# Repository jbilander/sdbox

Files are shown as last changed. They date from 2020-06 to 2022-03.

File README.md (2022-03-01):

# SDBox for Amiga

***
This version `v1` is superseded by the new `SDBox-v2` here: https://github.com/jbilander/SDBox-v2

There is also a SDBox Mini available here: https://github.com/jbilander/SDBox-Mini
***

### A parallel to sd-card project for the Amiga

This code uses the code from the amiga-par-to-spi-adapter https://github.com/niklasekstrom/amiga-par-to-spi-adapter written by Niklas Ekström. KiCad design, Schematics and files for DesignSpark Mechanical v4 is made by me. Design of the 3d-printable sdbox case is made by me and Tobias Niva (niva3d, http://www.niva3d.com/). It is a collaborative work done by us three, Enjoy!

***

<a href="images/sdbox_rev_1a_pic1.png">
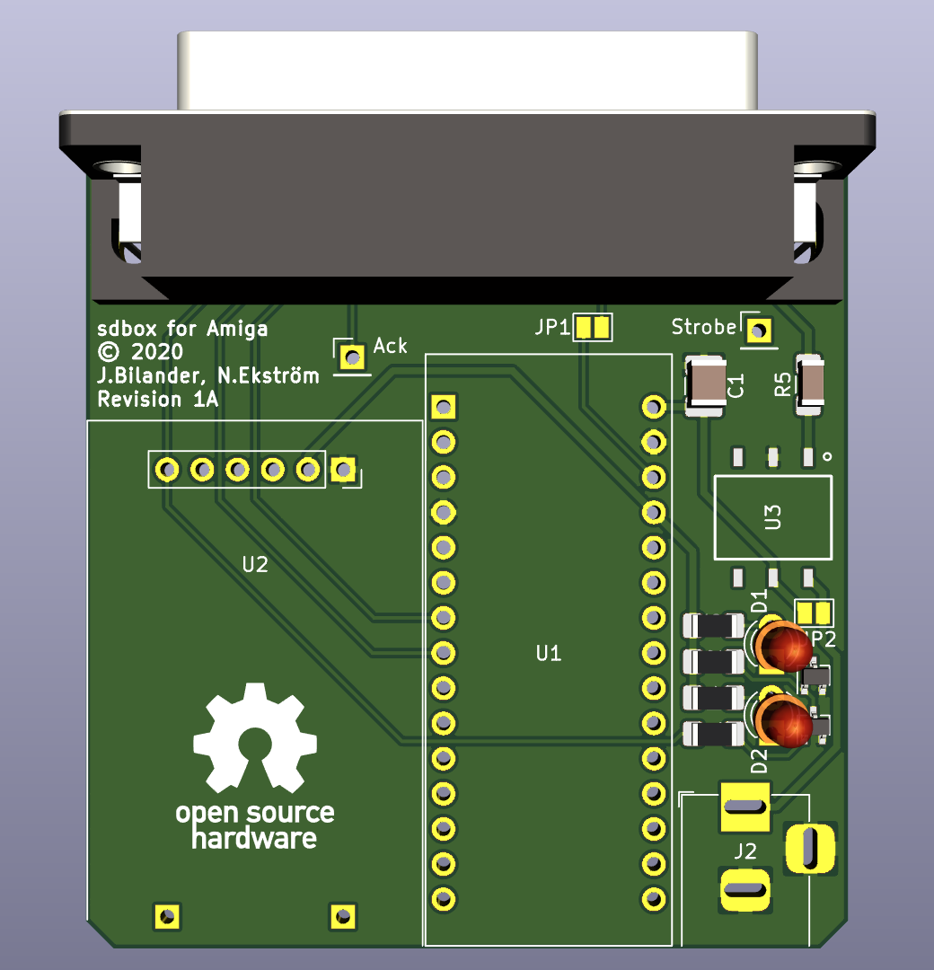
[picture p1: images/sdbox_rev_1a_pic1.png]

</a>
<a href="images/pcb_pic1.jpg">
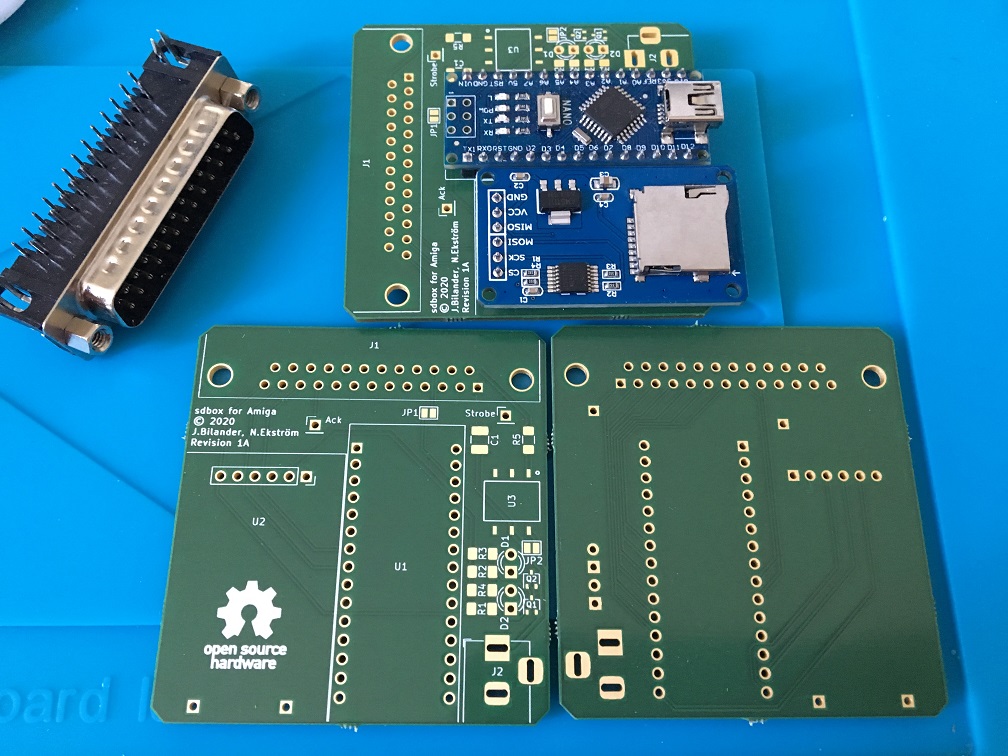
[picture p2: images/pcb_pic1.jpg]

</a>
<a href="images/sd_box_pic1.jpg">
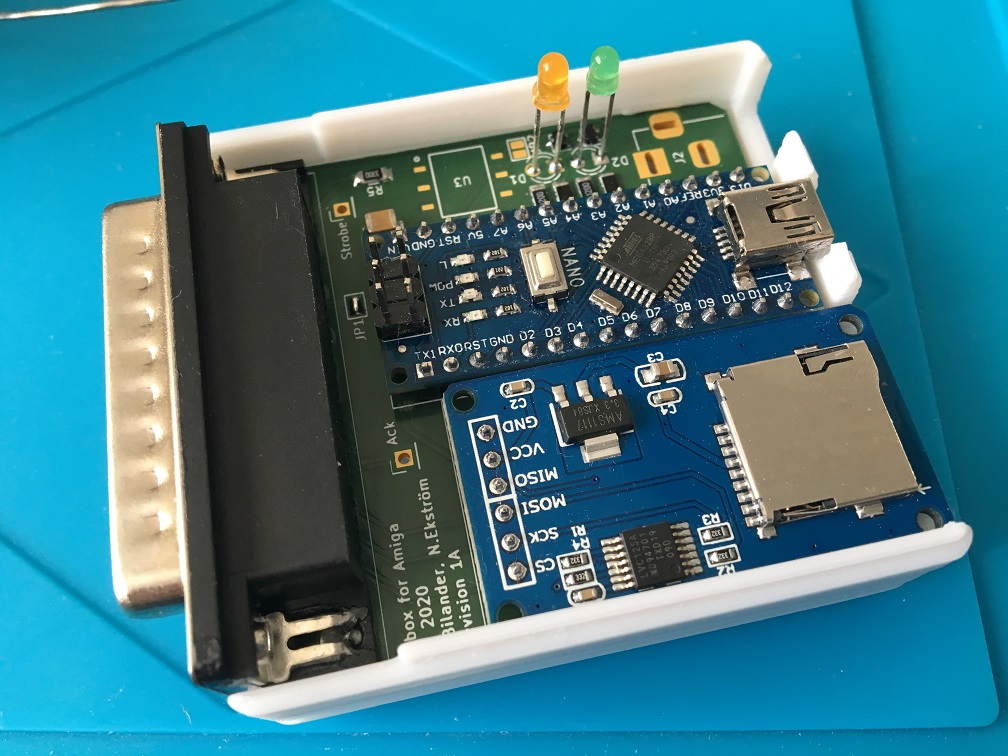
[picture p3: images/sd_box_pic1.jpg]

</a>
<a href="images/sdbox_front.jpg">
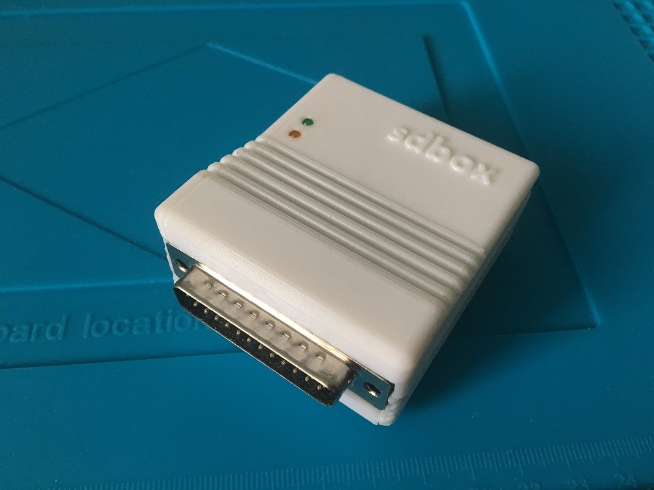
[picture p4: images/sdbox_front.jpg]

</a>
<a href="images/sdbox_backside_pic1.jpg">
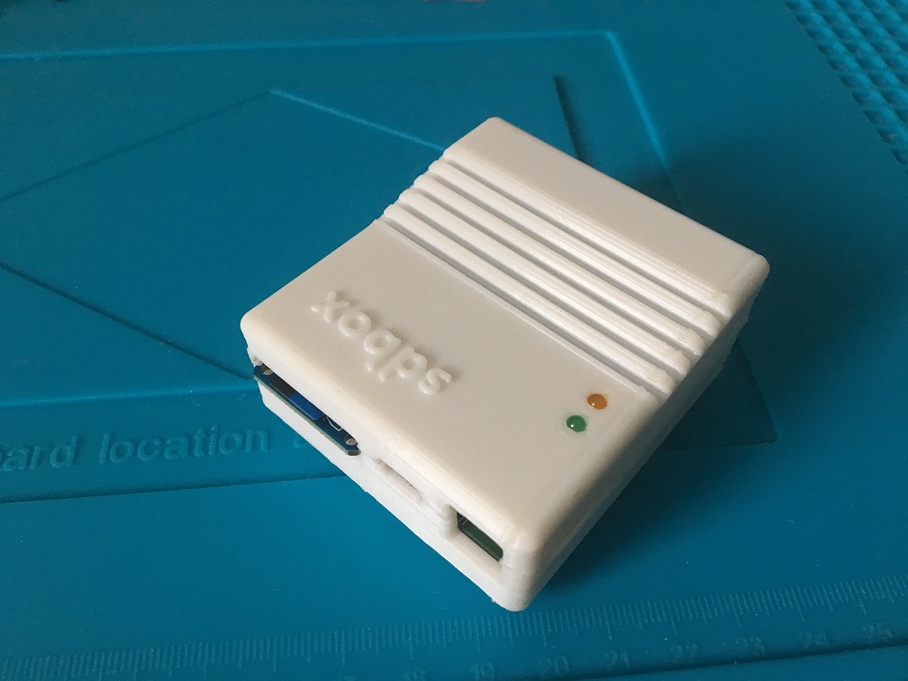
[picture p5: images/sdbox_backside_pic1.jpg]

</a>
<a href="images/sdbox_backside_pic2.jpg">
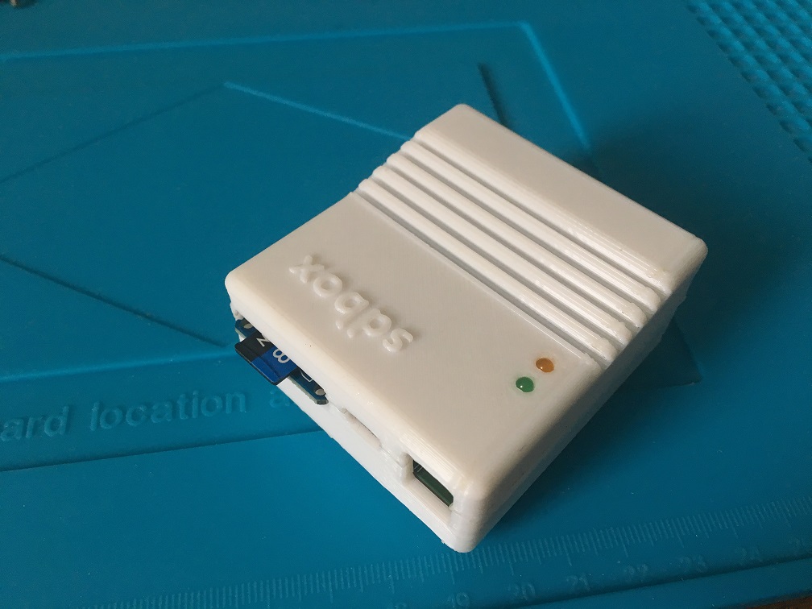
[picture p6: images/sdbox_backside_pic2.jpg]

</a>

***

What is the sdbox for Amiga? 

It is a small device that you can plug into your Amiga's parallel port and get access to a sd-card formatted with e.g. a windows FAT file system. It uses an Arduino Nano V3 and a common cheap MicroSD Card Adapter that has a voltage level shifter on board. These small devices are soldered onto a small PCB together with a male d-sub db25 connector that fits into the Amiga parallel port (The A1000 needs a proper gender changer, be aware). The device must be powered externally either through the usb-connector on the Nano or via the separate barrel jack connector on the main PCB. A power supply with 1A DC capacity should suffice. `5V` via USB or `7-12V` via the barrel jack power connector that goes to the VIN of the Nano V3. The driver should be AmigaOS system friendly but takes exclusive access over the parallel port so don't expect to run other things on this port together with the sdbox with some kind of breakout cable. It should work from 1.3 and upwards, verified working on 1.3, 3.1 and 3.1.4 so far.

The schematics, BOM, kicad drawings and the 3d-printable case source and stl files can all be found in the hardware folder.

PCBs can be order directly via link below or you can send the gerbers zip (or generate gerbers yourself) and send them to your favorite boardhouse.

https://aisler.net/p/YVXJBQHM

***
Ok enough talk!, show us some videos:
<br />

Copying from Amiga to sd-card<br />
https://i.imgur.com/um15pal.mp4

Copying from sd-card to the Amiga (cpu fastrom activated, KS ROM loaded into Fast RAM)<br />
https://i.imgur.com/G6VRPpx.mp4

Copying from sd-card to the Amiga  (without fastrom activated) <br />
https://i.imgur.com/ADebdlJ.mp4

***

<a href="images/sd_box_pic2.jpg">
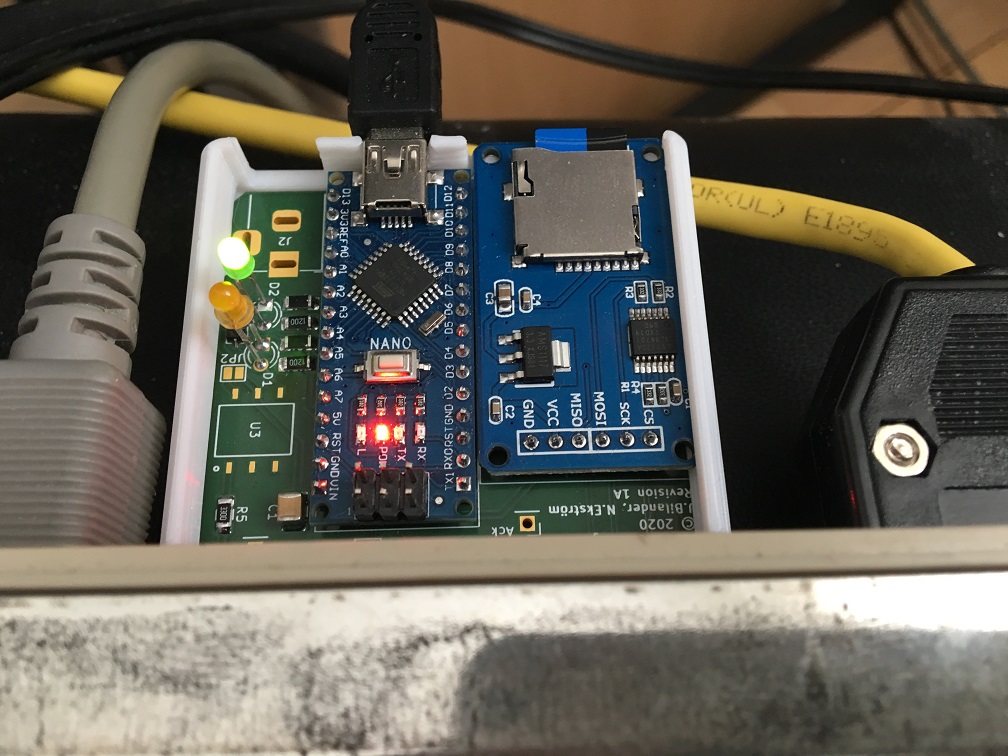
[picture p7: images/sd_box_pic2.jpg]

</a>
<a href="images/sd_box_pic3.jpg">
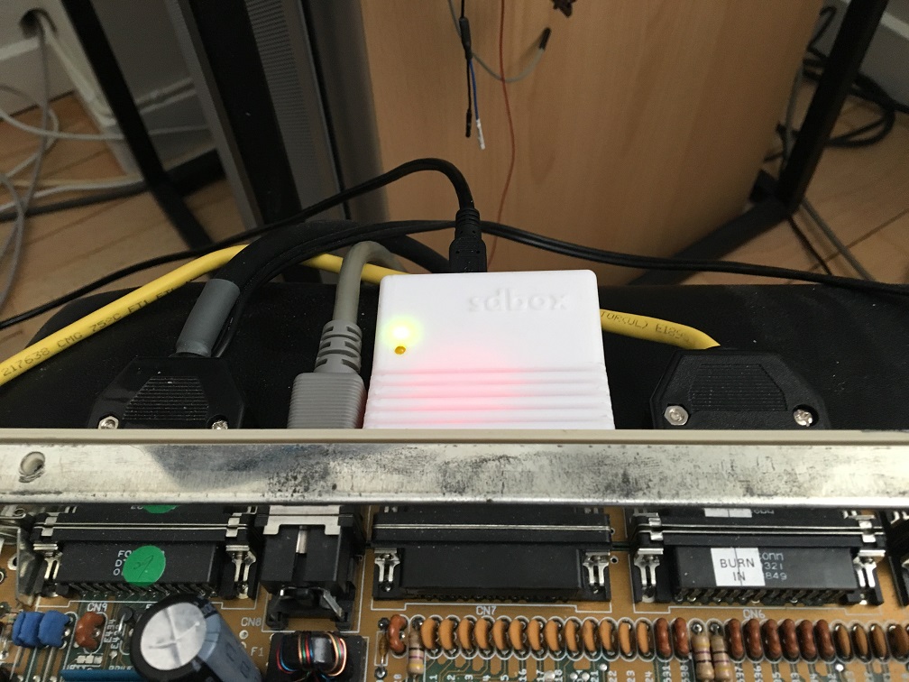
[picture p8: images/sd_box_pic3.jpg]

</a>
<a href="images/sd_box_pic4.jpg">
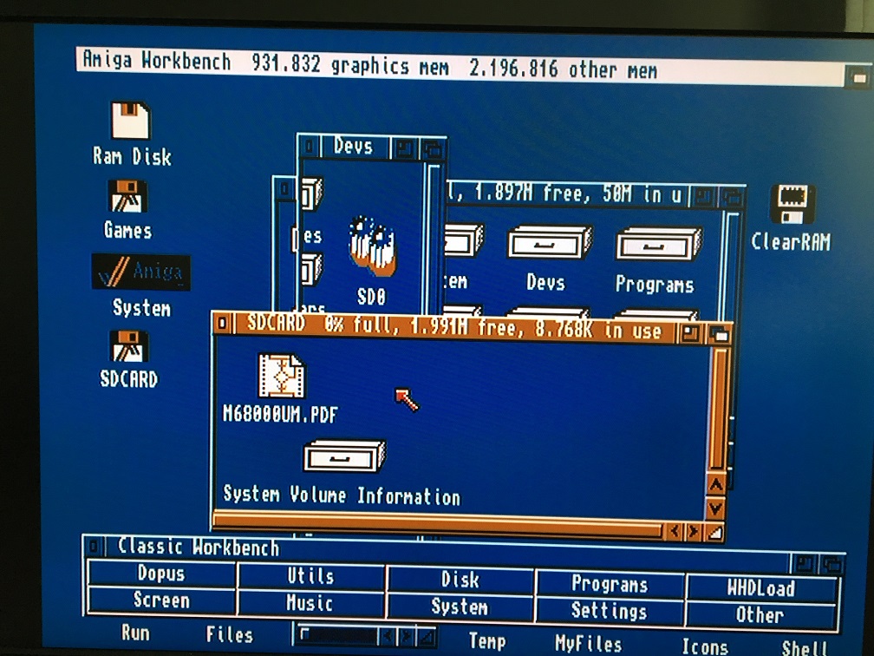
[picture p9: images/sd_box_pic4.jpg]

</a>

***

<a href="images/sdbox_3d_model_pic1.jpg">
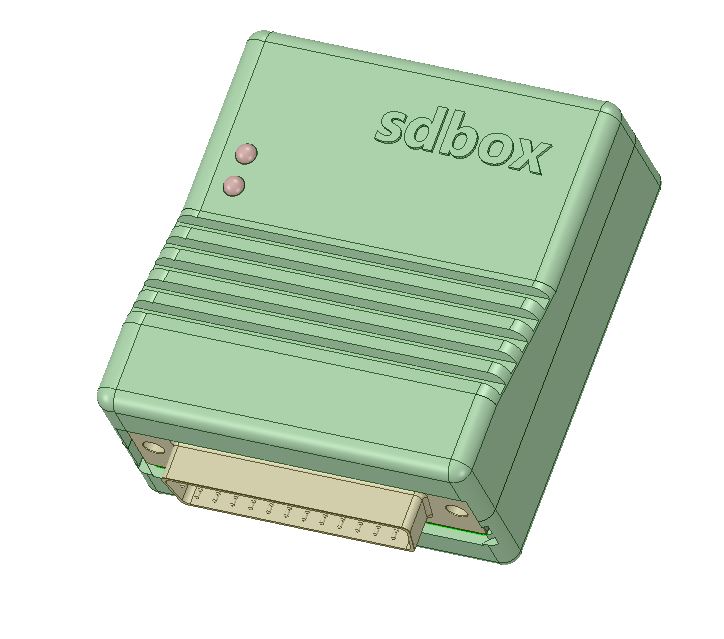
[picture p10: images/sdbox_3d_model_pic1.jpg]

</a>
<a href="images/vFinal-4view.png">
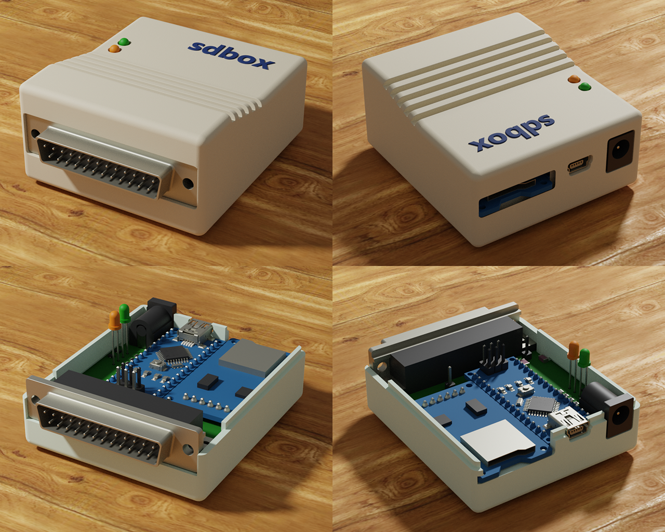
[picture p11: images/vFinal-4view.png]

</a>
<br />

More rendered pictures and concepts by `niva3d` under the `images/_renders` directory, made in Blender, check it out!

***

### 3d-printing

Check the README in the `hardware/DSM` folder

***

### Howto build the spisd.device driver

Check the README in the sd folder.

For the lazy: Binaries available now in a zip file under the `release` tab above.

***

### Caveats

One little caveat to keep in mind is that we do no CRC-verification of data being copied so please verify your files afterwards manually if you are going to copy important files over this way like taking a backup or something. Another caveat is that not all sd-cards might work with the sdbox so aim for a cheap 4/8 GB card and format it with a smaller partition `below 4GB` with FAT is a good starting point. If you see an error message saying `bad number` when trying to mount `SD0` it may be an indication that your particular sd-card simply doesn't work with the sdbox for some reason.

Everything done here is provide `as is`, don't blame us if your Amiga CIAs dies or your files get corrupted using the sdbox. I don't think it will happen though. Be careful though when plugging the sdbox in or out of the Amiga, always do that with the Amiga turned off.

    Some advice from Tom Handley / 18 April 93 (taken from pario on Aminet)

    NEVER connect, disconnect, or switch, parallel port lines with the power on!  
    ALWAYS shut the power off first!  In most cases, you should use the following sequence:

       Power up:   - Turn on your Amiga
                   - Turn on the external device

       Power down: - Turn off the external device
                   - Turn off your Amiga
                   
    If you have been switching devices with the power on you have been lucky...
    Not following the above precaution, and static electricity, are the two main
    causes of user-induced 8520 failures.
***

The sequence I use when powering the sdbox via USB is this:

* Plug the micro sd-card into the MicroSD card slot of the sdbox
* With the Amiga turned off plug the sdbox into the Amiga 
* Connect the +5V USB power cable into the sdbox, the two LEDs will light up with a steady shine. Don't worry that the activity LED light turns on, it's on when the SEL/CS line goes low (Zero). It will turn off as soon as the Amiga is turned on.
* Turn on the Amiga
* In wb mount the card
* When done, turn off the Amiga, the sdbox Activity LED will light up again as a reminder to unplug the USB power cable
* Unplug the sdbox from the Amiga if you want to remove it.

This has worked without any issues for me.

Hopefully powering via the barrel jack and using U3 chip (Solid State Relay) will work and automatically handle the Power cycling following the Amiga's on/off.

__UPDATE: Powering via the barrel jack is now verified and working.__ see last section in this readme

***

### Kudos

Many thanks to Mike Stirling for writing the original k1208-drivers and making them open source, we built further on his code. It was a good starting point. Thanks Mike and kipper2k and others involved in k1208.

***

### Performance 

What about performance you may ask? 

Well, Niklas managed to write the drivers with some real clever assembler to make it go at 2E-speed (theoretical 350 KB/s, IRL around 225-280 KB/s) if you have some kind of Accelerator installed in your A500. 
Copying a 23 MB file from the SD-card to the compact flash in the HC508 took 98 seconds, giving a throughput of 225 KB/s. We think this is a good result given the fact of the slow clocking of the CIAs (E-clock). It will also work with a standard 68k CPU at 7 MHz although slower.

With my TF534 and 3.1 rom loaded into Fast RAM via the command `cpu fastrom` (requires a MMU) I get 280 KB/s in SysInfo, and without fastrom 250 KB/s. It is a little slower copying to the Amiga than from the Amiga.

<a href="images/screenshots/sdcard_sysinfo_speed.jpg">
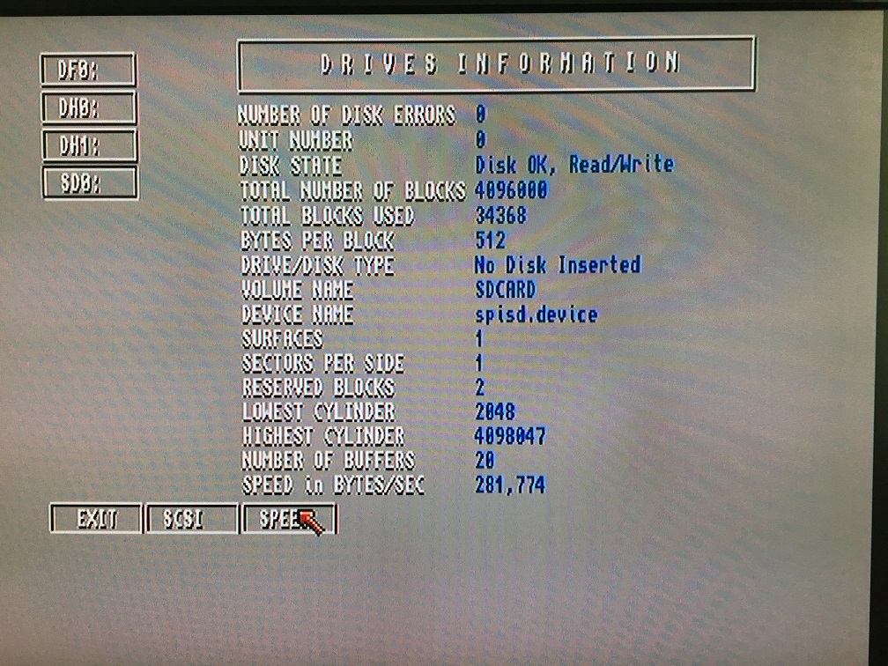
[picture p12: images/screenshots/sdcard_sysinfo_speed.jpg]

</a>
<a href="images/screenshots/amiga_parallel_port_2E_speed.jpg">
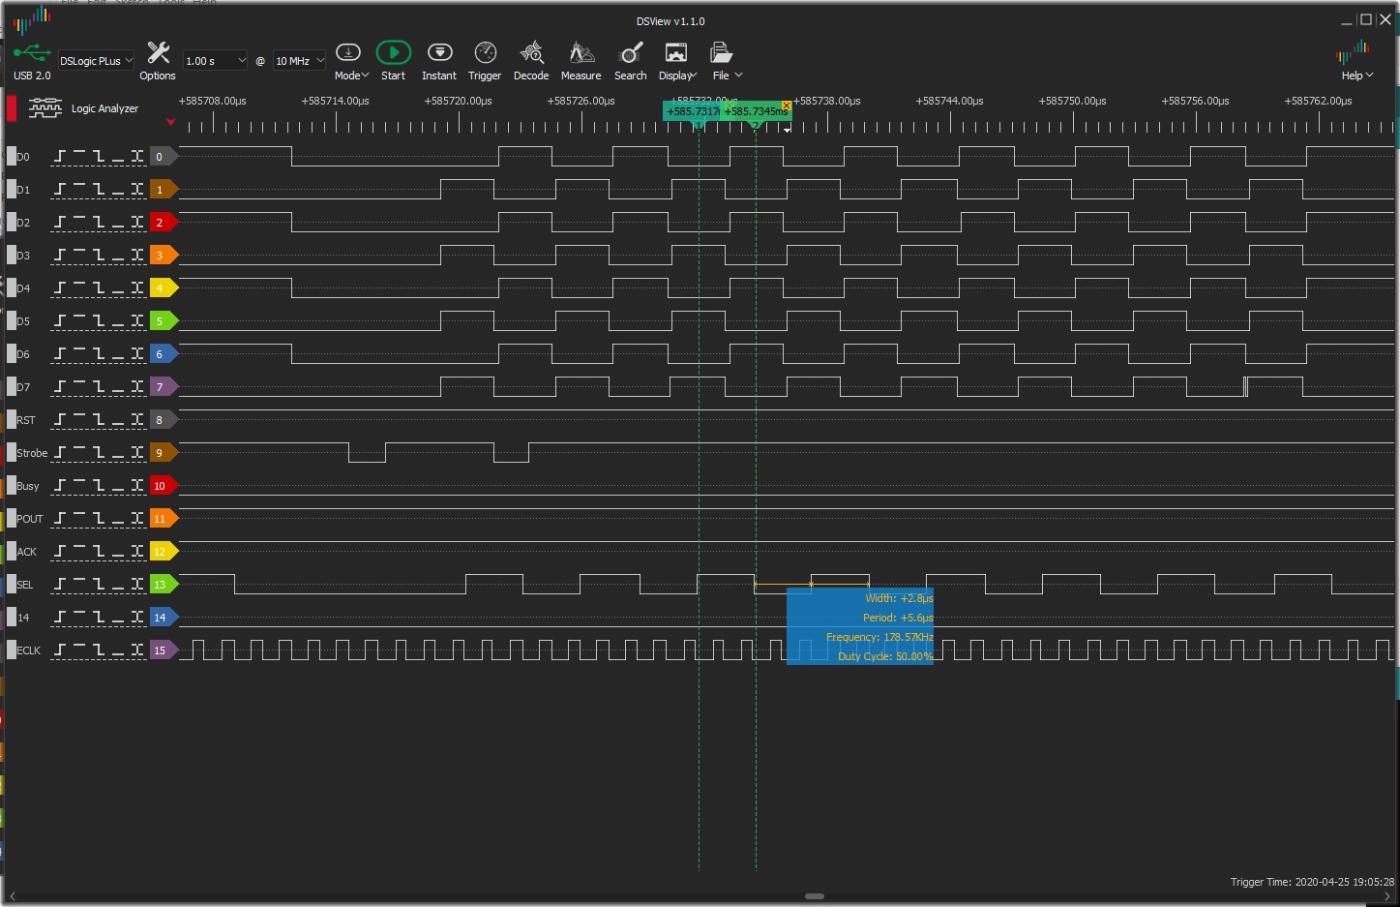
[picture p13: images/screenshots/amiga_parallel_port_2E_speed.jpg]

</a>

Speed definition of 2E here: <br />
https://lallafa.de/blog/2015/09/amiga-parallel-port-how-fast-can-you-go/

***

### Howto build the sdbox

Start with removing the angled pins from the MicroSD Card Adapter and replace with straight pins like shown on pictures below:

<a href="images/build/sdbox_build_pic1.jpg">
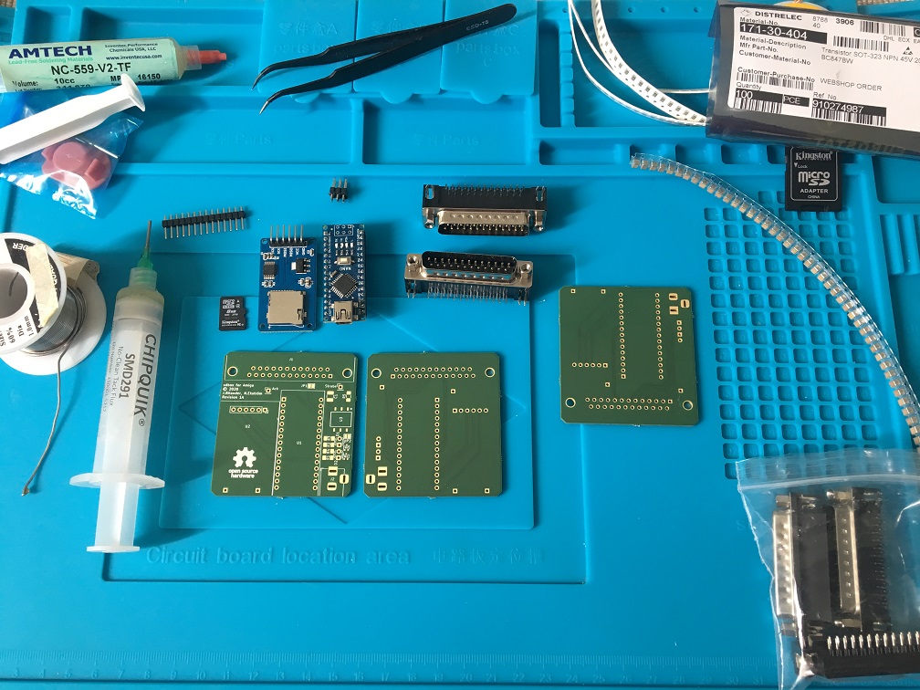
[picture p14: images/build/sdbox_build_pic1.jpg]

</a>
<a href="images/build/sdbox_build_pic2.jpg">
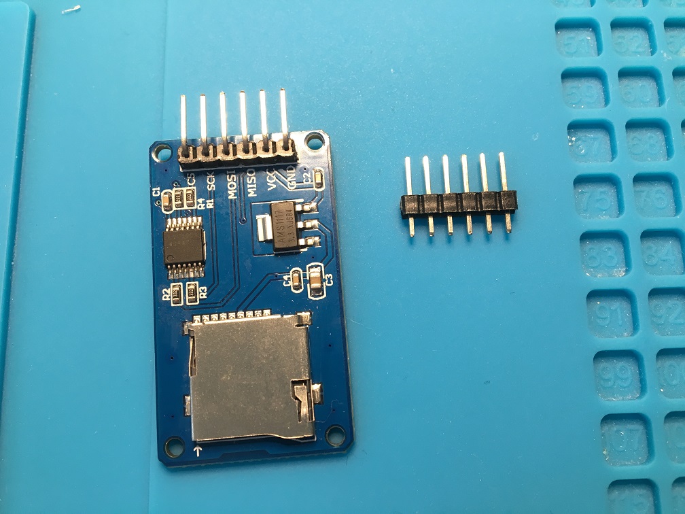
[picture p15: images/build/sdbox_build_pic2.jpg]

</a>
<a href="images/build/sdbox_build_pic3.jpg">
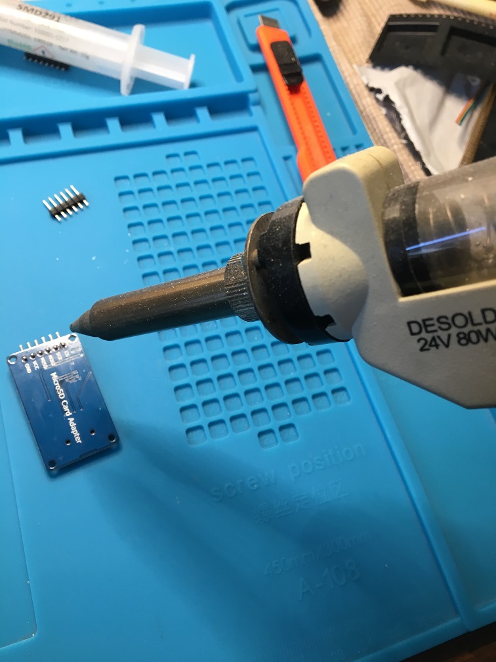
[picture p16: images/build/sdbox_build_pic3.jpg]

</a>
<a href="images/build/sdbox_build_pic4.jpg">
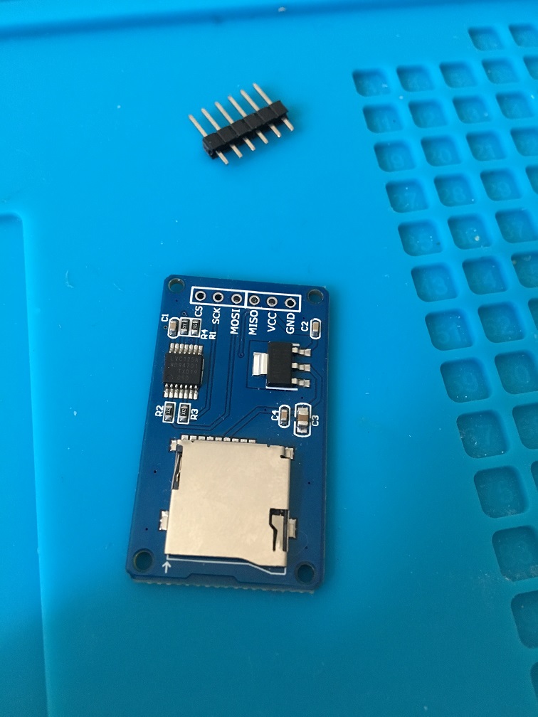
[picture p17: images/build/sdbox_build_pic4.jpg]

</a>
<a href="images/build/sdbox_build_pic5.jpg">
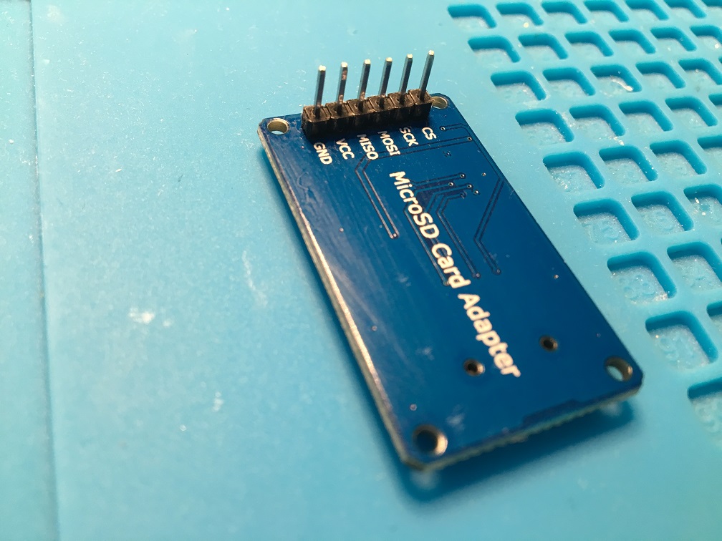
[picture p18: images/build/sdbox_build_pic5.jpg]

</a>
<a href="images/build/sdbox_build_pic6.jpg">
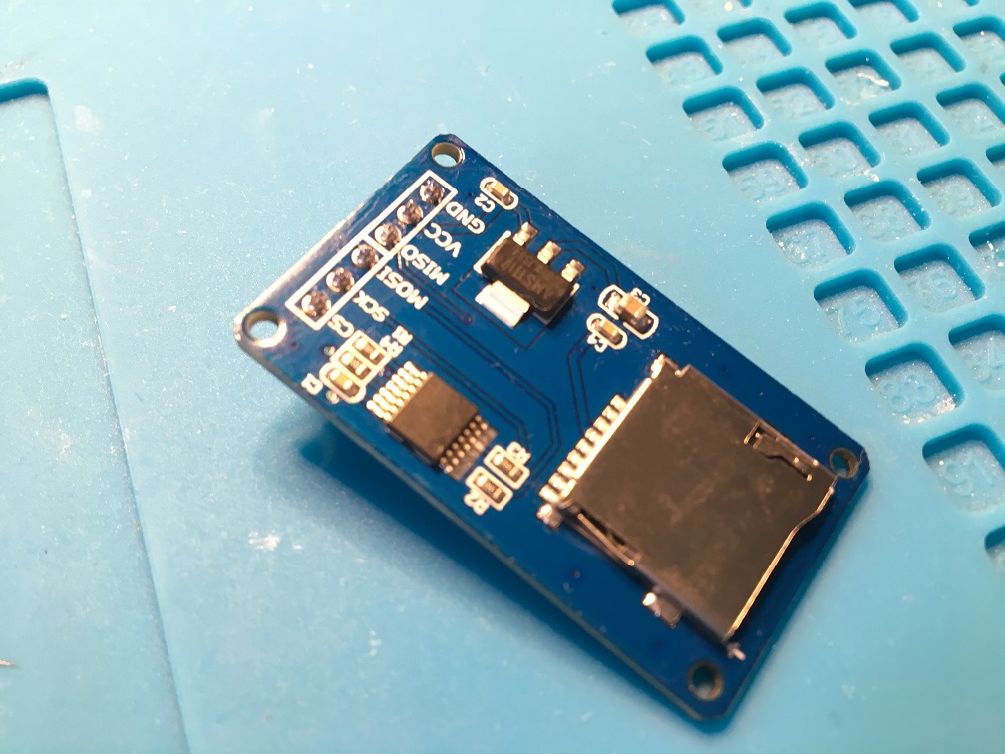
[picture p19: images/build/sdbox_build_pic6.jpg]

</a>

***

Now we start soldering on the surface mount parts, the passives, also known as the birdseed :) Start with Q1 and Q2, they are tiny so you probably need some sort of magnification. I use a lamp with a built-in magnifier glass, it works well, I do not have a microscope. Use a fine tip with your solder iron...

***

<a href="images/build/sdbox_build_pic7.jpg">
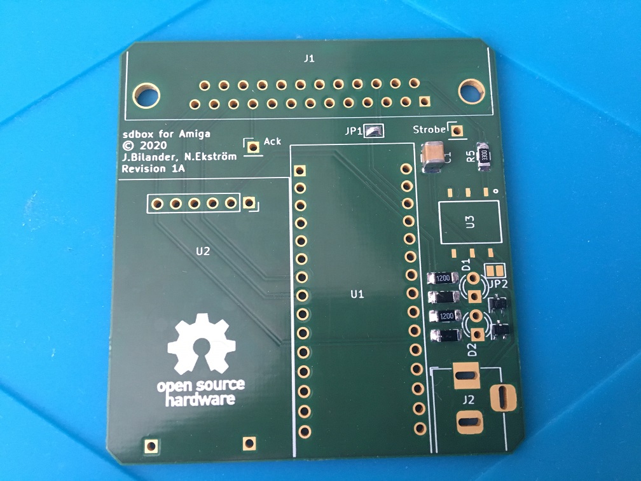
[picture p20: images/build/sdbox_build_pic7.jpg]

</a>
<a href="images/build/sdbox_build_pic8.jpg">
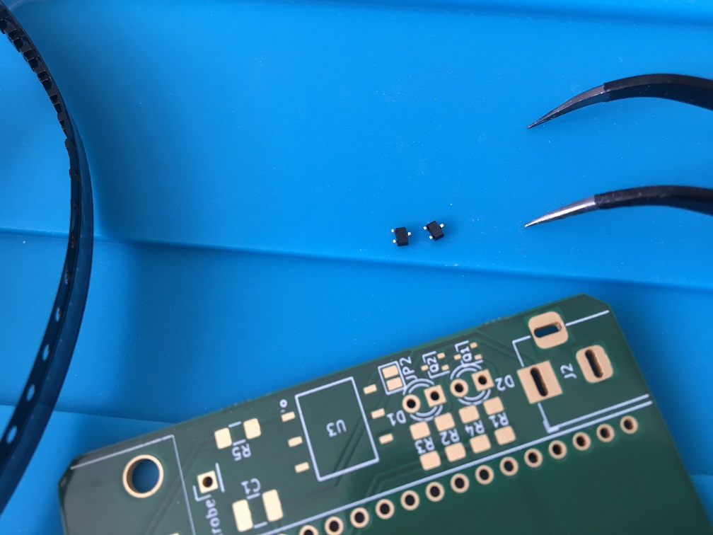
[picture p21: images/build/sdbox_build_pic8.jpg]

</a>
<a href="images/build/sdbox_build_pic10.jpg">
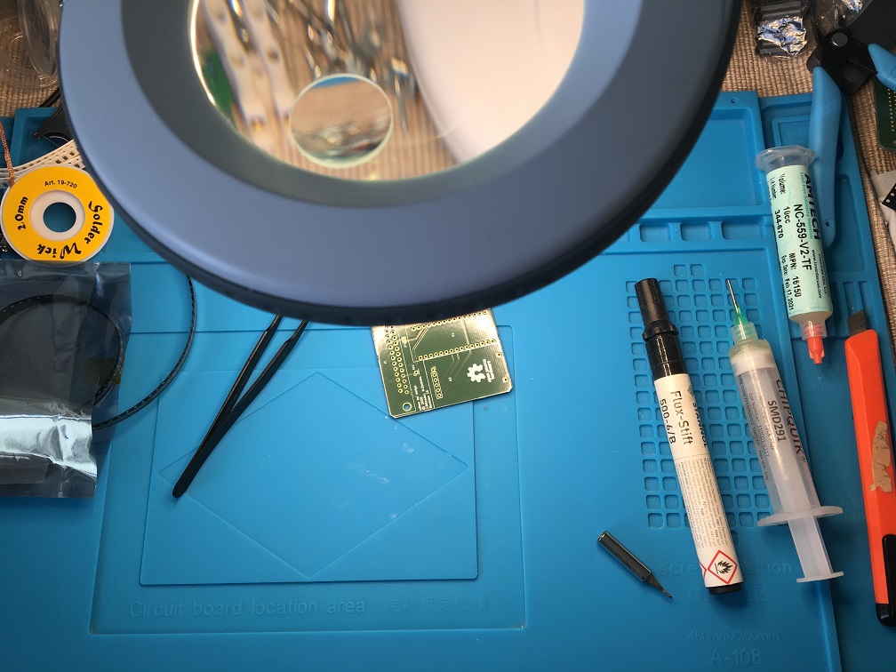
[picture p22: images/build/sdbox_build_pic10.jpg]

</a>
<a href="images/build/sdbox_build_pic9.jpg">
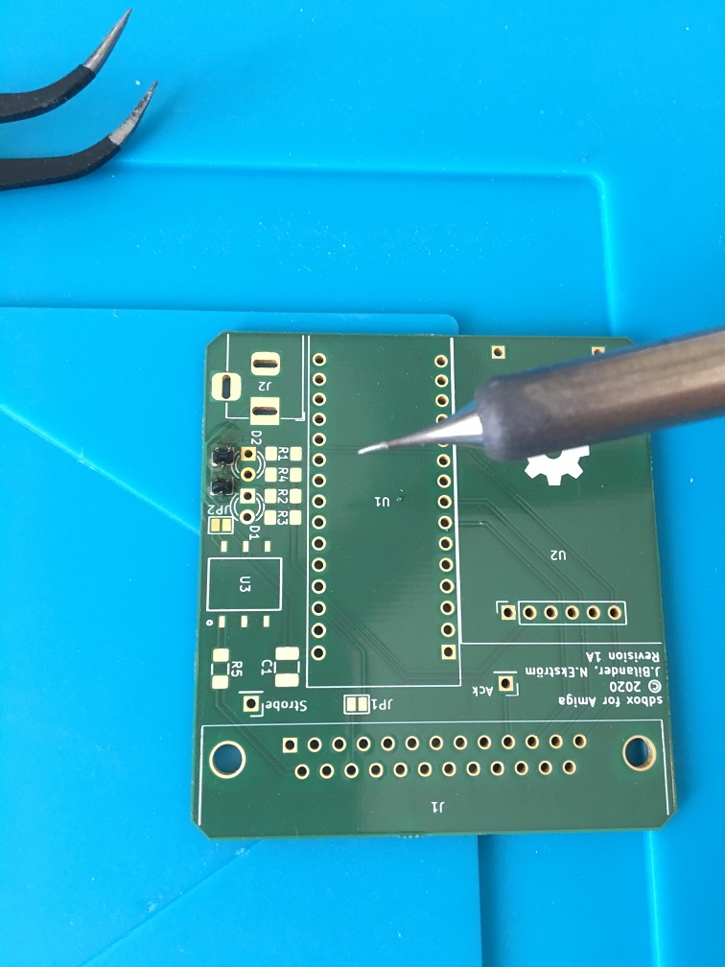
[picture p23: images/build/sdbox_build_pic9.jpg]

</a>
<a href="images/build/sdbox_build_pic11.jpg">
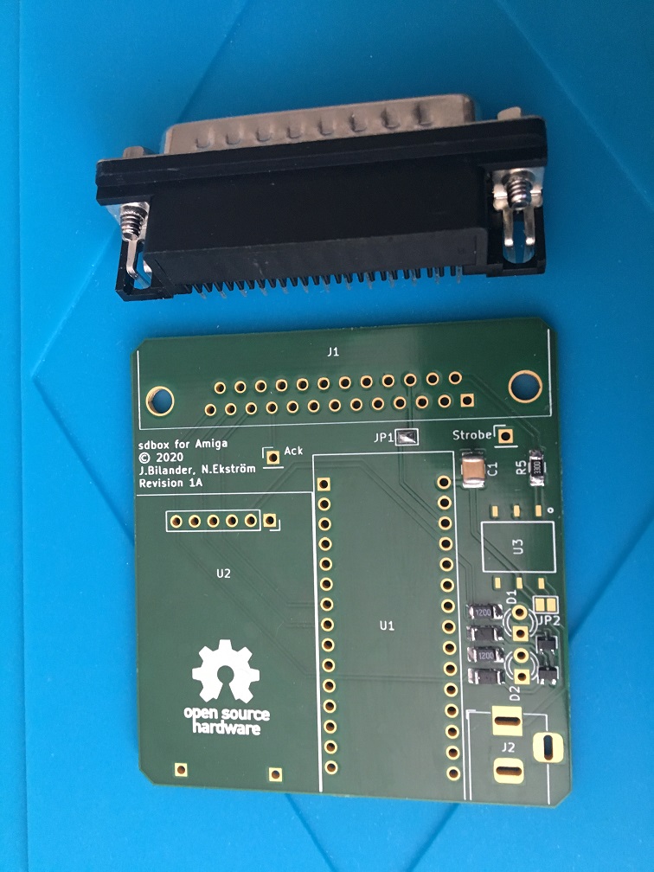
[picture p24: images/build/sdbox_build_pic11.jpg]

</a>

***

Now with the surface mount stuff done we do the through-hole stuff, solder on two cut-down pins as leg support for the MicroSD Card Adapter, the adapter will rest on these and make it in level and the same height as the Nano.

***

<a href="images/build/sdbox_build_pic12.jpg">
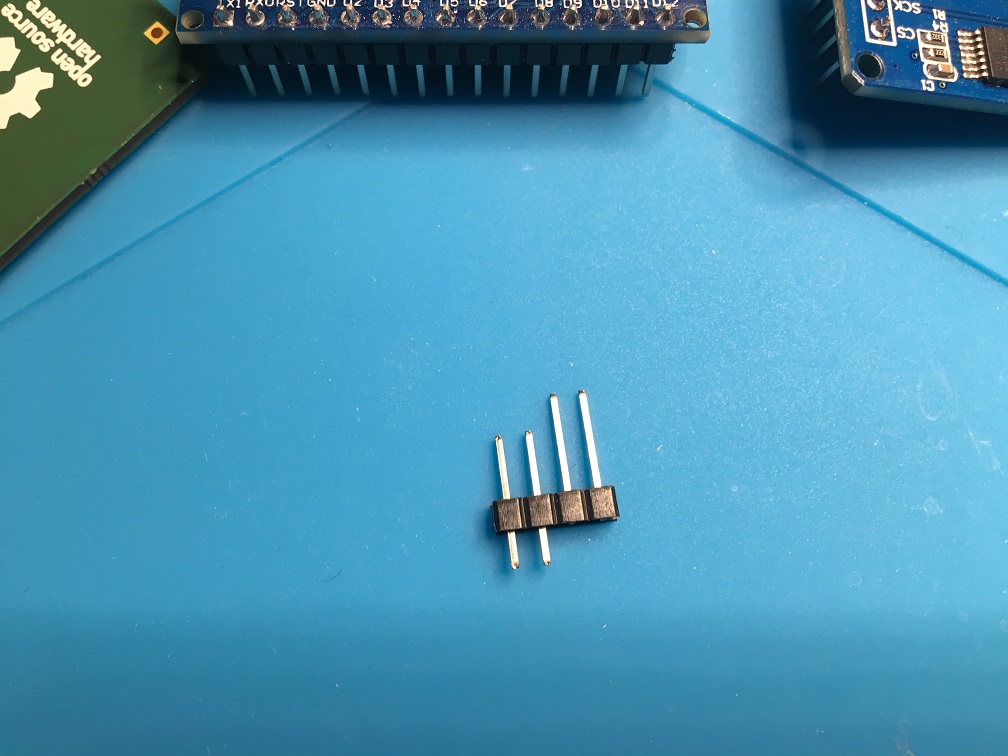
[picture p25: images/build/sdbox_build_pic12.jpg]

</a>
<a href="images/build/sdbox_build_pic13.jpg">
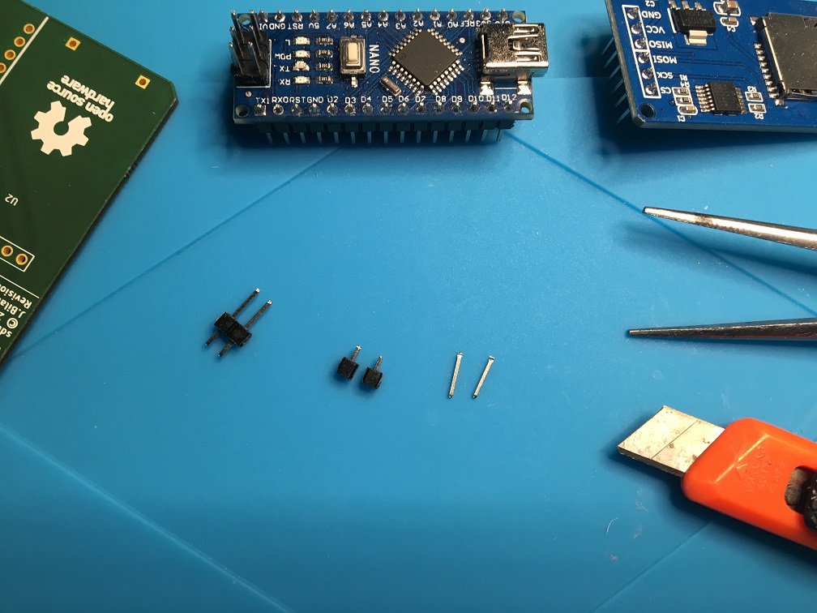
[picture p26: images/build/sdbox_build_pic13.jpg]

</a>
<a href="images/build/sdbox_build_pic14.jpg">
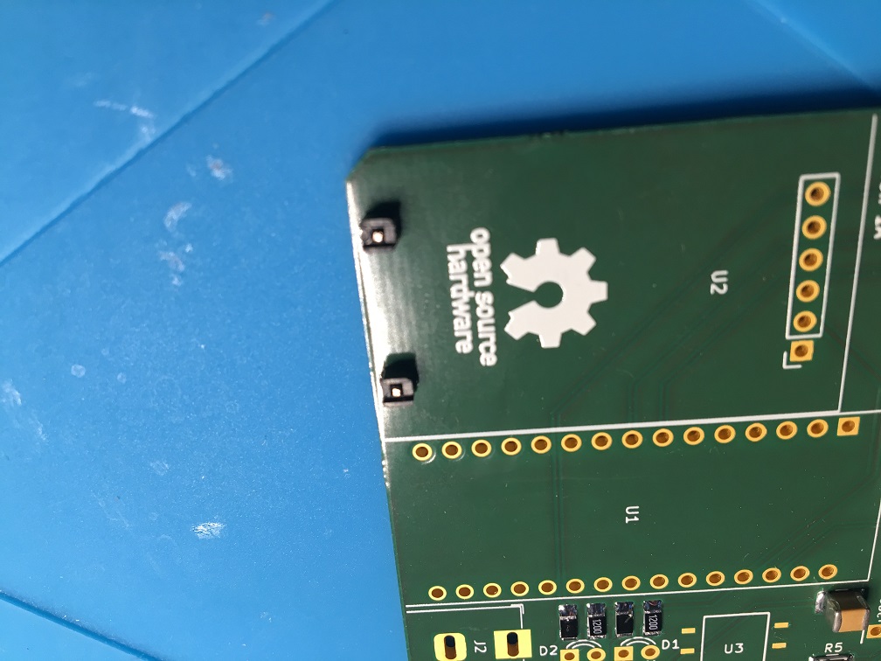
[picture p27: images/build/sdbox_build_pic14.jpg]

</a>
<a href="images/build/sdbox_build_pic15.jpg">
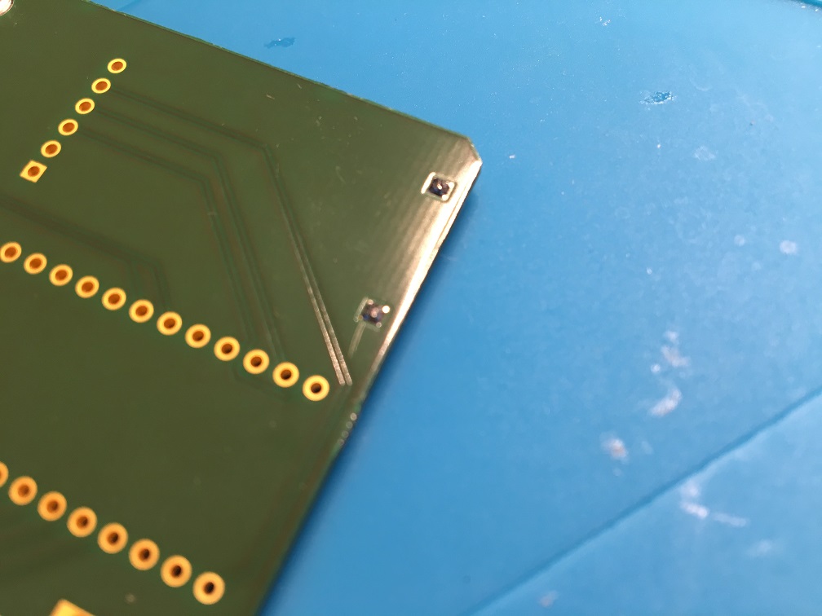
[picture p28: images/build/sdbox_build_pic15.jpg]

</a>

***

Now, with this type of connector the metal plate comes loose when you unscrew the connector nuts. We need to remove them because we don't want to remove them on the Amiga side. Use some super glue and a vise or similar to press them together a couple of minutes until the glue bites. Be quick if you use super glue! Then put the screws back while soldering, we want the metal pieces in there as a support taking some force off the pins when plugging the device in and out of the Amiga.

***
<a href="images/build/sdbox_build_pic16.jpg">
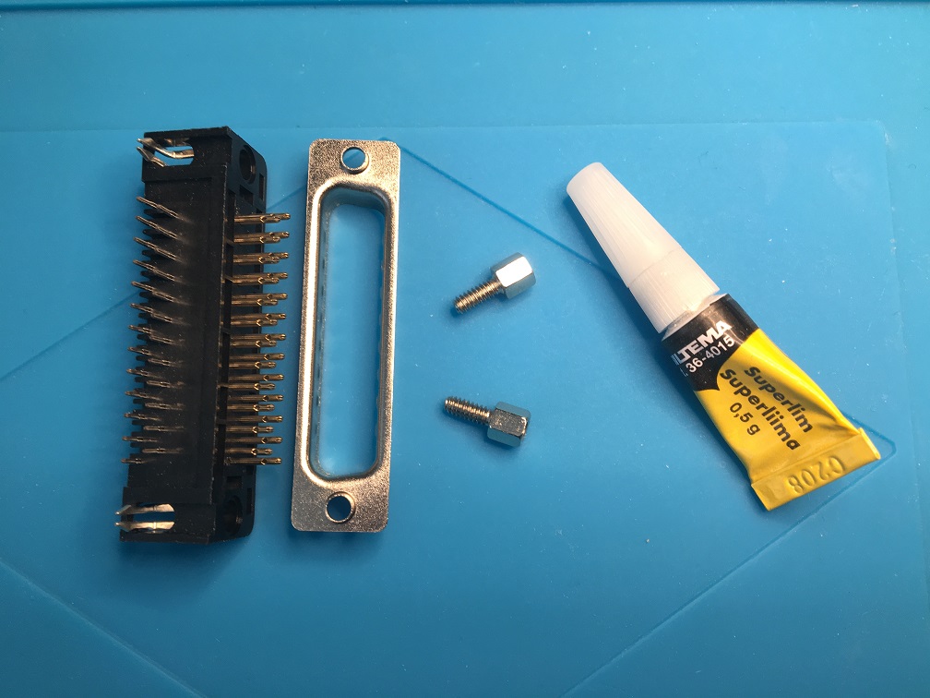
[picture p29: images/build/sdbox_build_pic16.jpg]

</a>
<a href="images/build/sdbox_build_pic17.jpg">
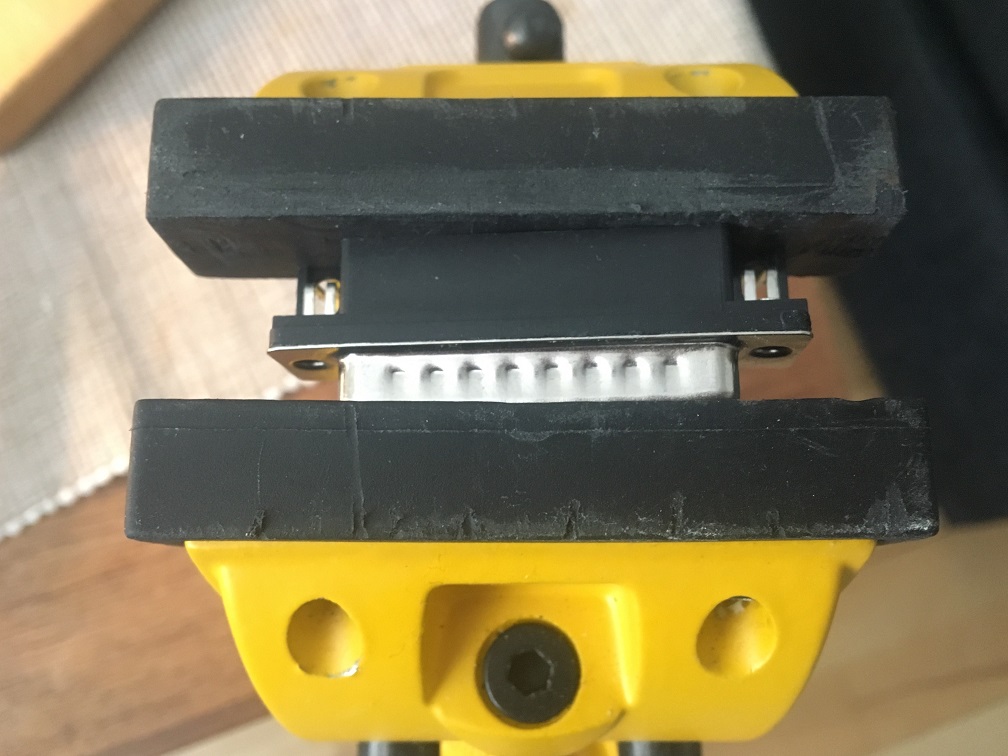
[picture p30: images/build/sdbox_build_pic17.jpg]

</a>
<a href="images/build/sdbox_build_pic18.jpg">
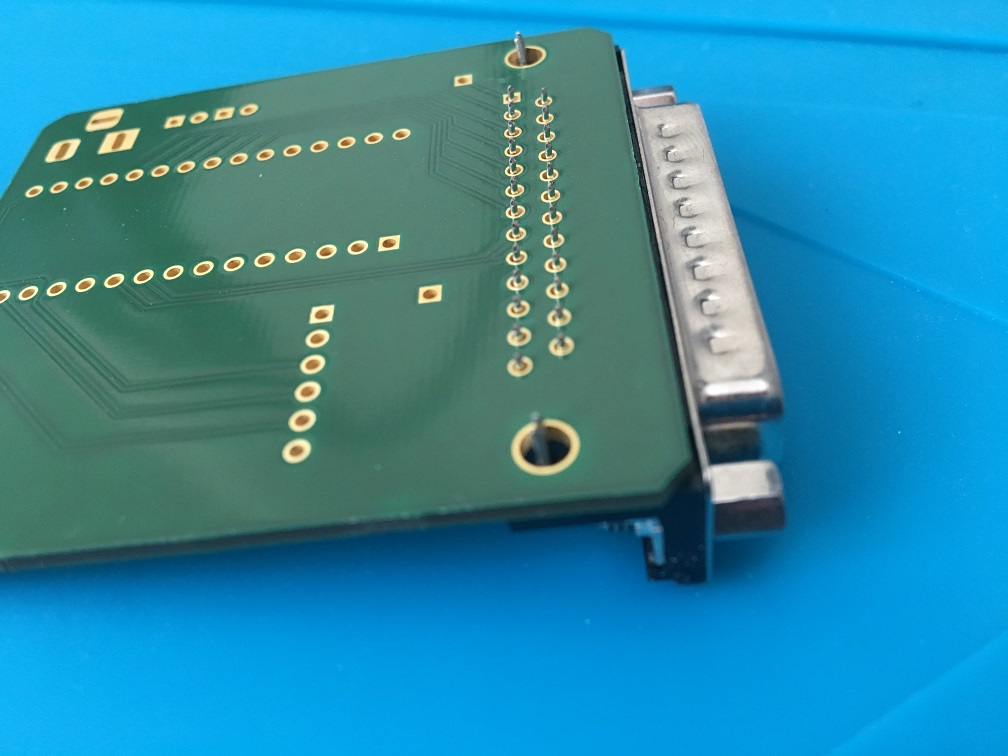
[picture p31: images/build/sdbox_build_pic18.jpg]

</a>
<a href="images/build/sdbox_build_pic19.jpg">
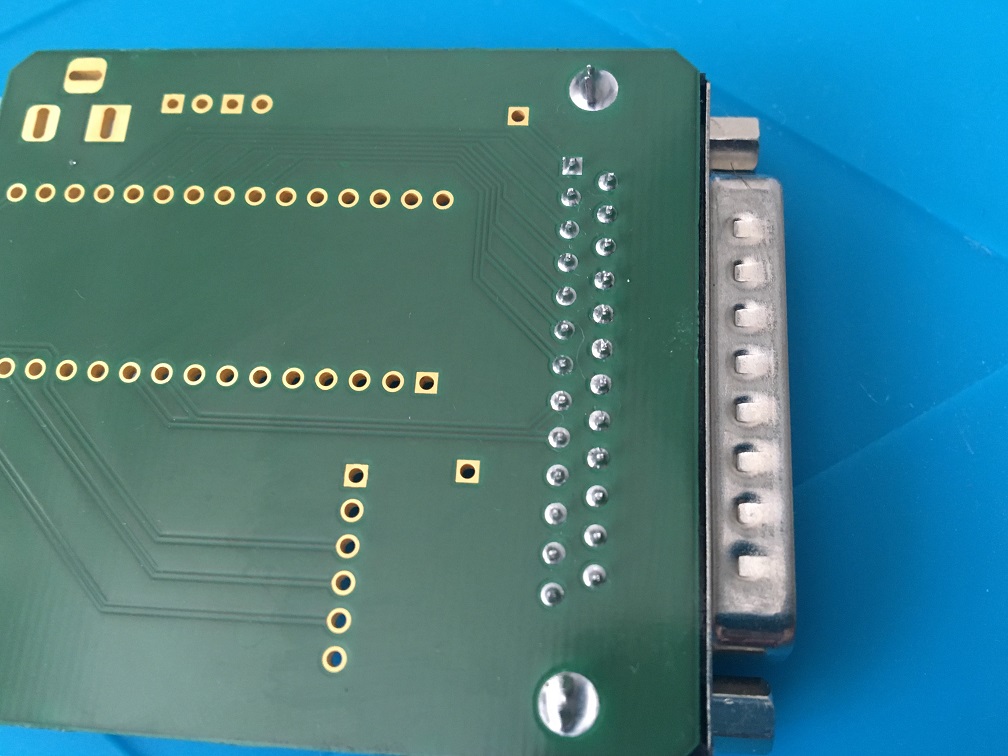
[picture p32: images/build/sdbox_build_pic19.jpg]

</a>

***

Now solder the MicroSD Card Adapter and the Nano down to the PCB as well.

***

<a href="images/build/sdbox_build_pic20.jpg">
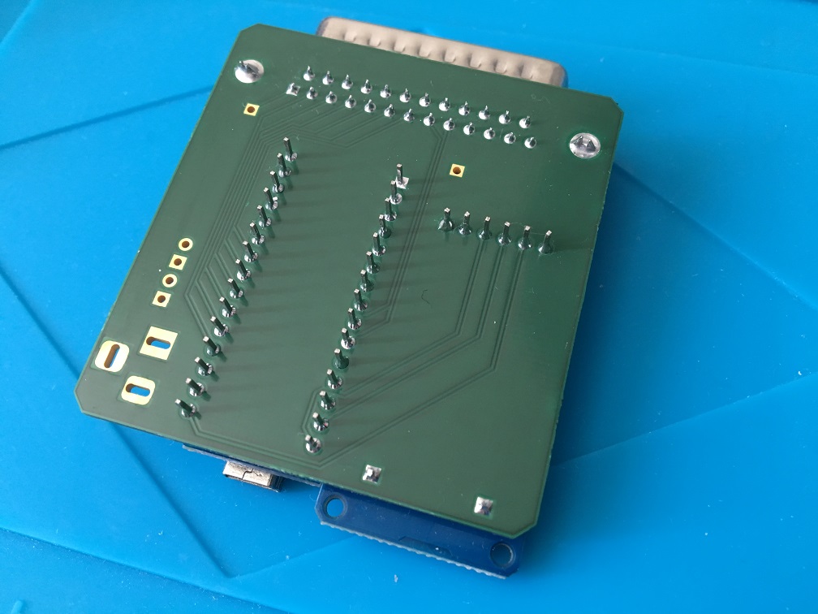
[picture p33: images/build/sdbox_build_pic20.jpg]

</a>
<a href="images/build/sdbox_build_pic21.jpg">
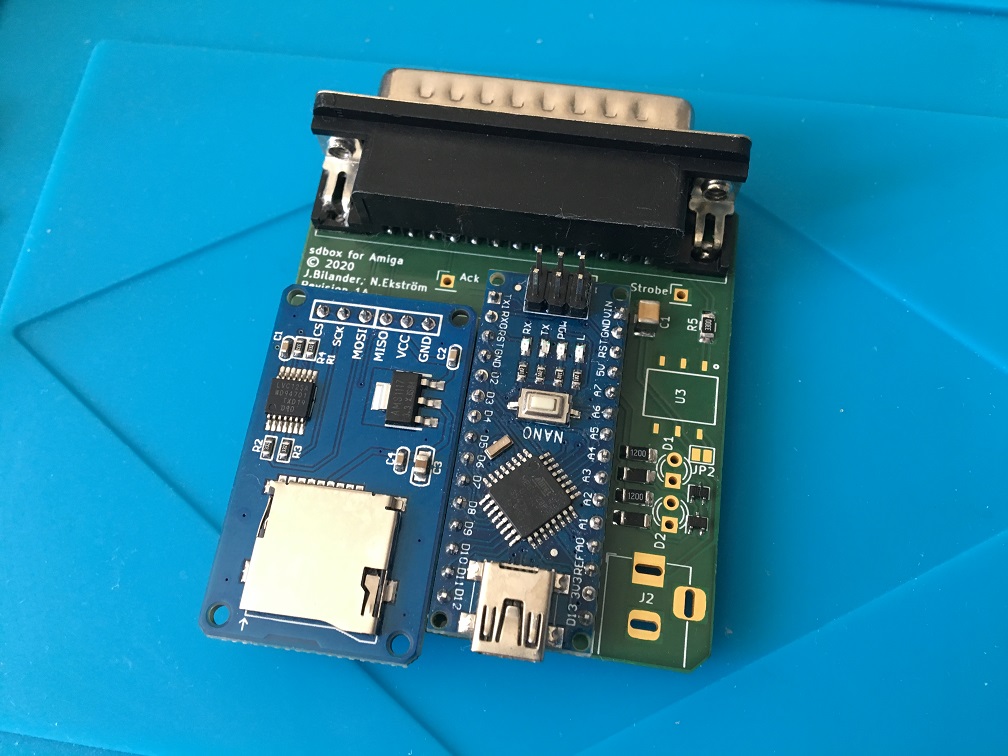
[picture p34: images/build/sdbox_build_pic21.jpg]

</a>

***

Almost done!, time to put the LEDs in. To get the correct LED height for the sdbox 3d-printable case, I used a leftover trial print of the bottom part and drilled a hole through it to give me access to tack the LEDs down, with the iron, while holding the LEDs in place pressing on the legs gently. Cut the legs like in the picture below so that you can remove the pcb from the case and solder and trim them better afterwards. Job done!

***

<a href="images/build/sdbox_build_pic22.jpg">
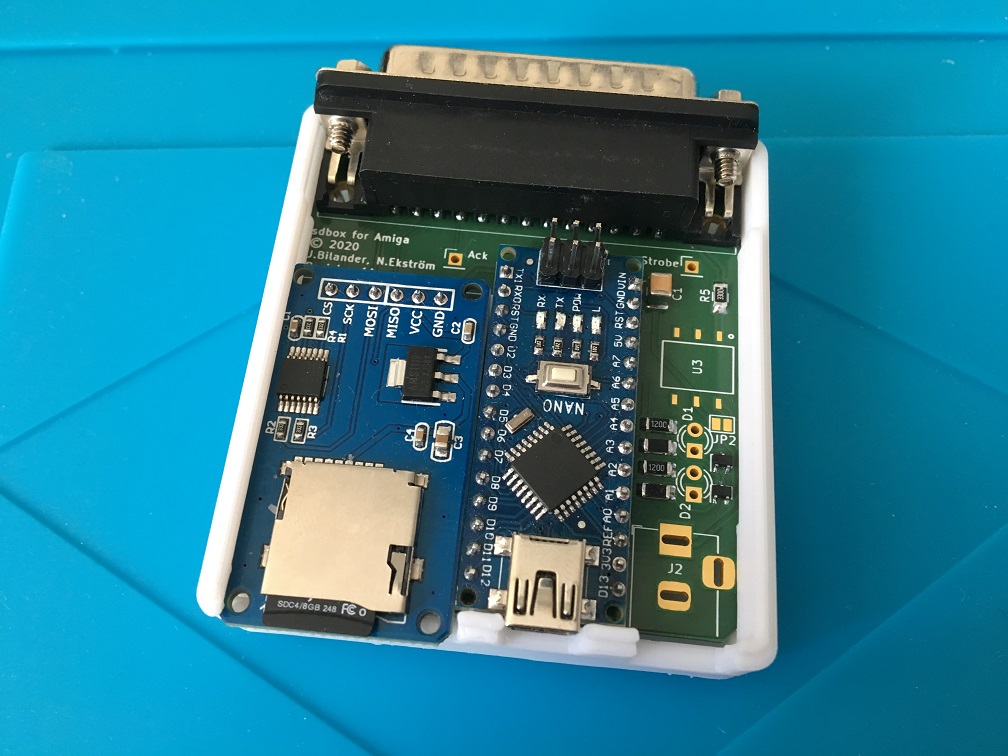
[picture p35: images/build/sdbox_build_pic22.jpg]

</a>
<a href="images/build/sdbox_build_pic23.jpg">
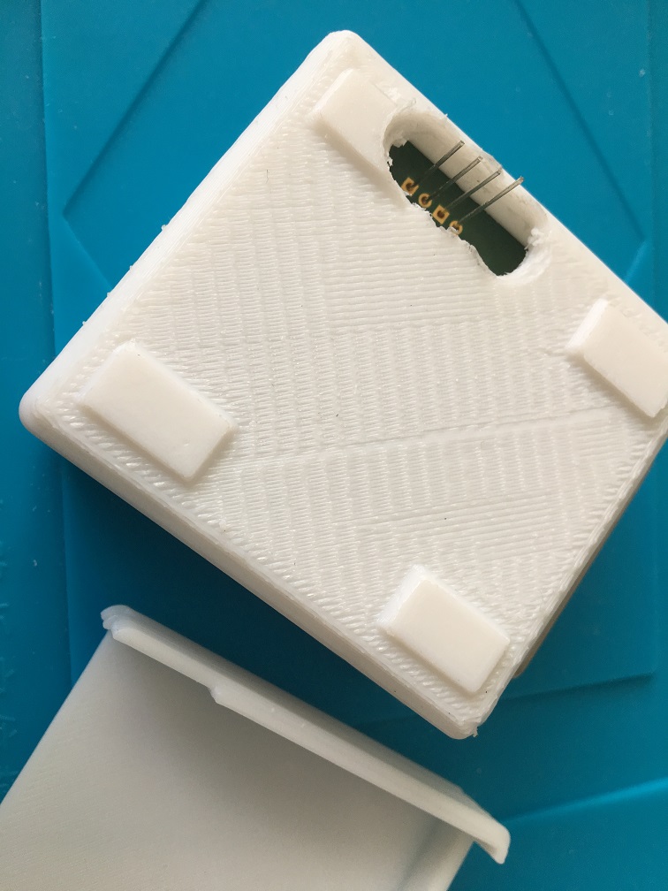
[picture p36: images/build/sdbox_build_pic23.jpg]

</a>
<a href="images/build/sdbox_build_pic24.jpg">
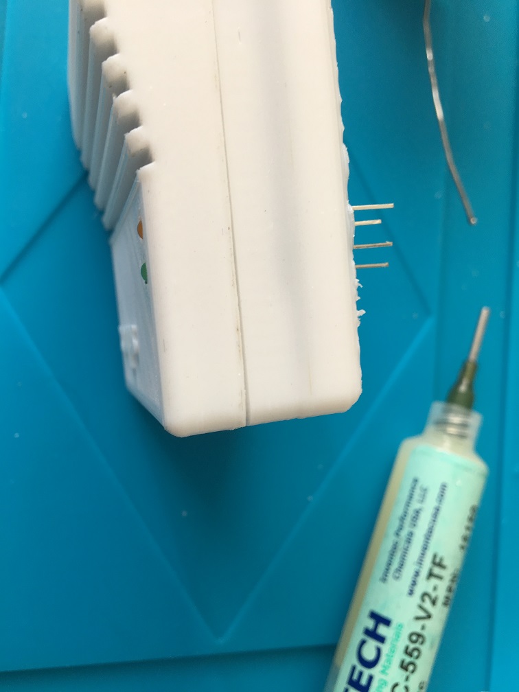
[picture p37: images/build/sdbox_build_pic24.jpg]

</a>
<a href="images/build/sdbox_build_pic25.jpg">
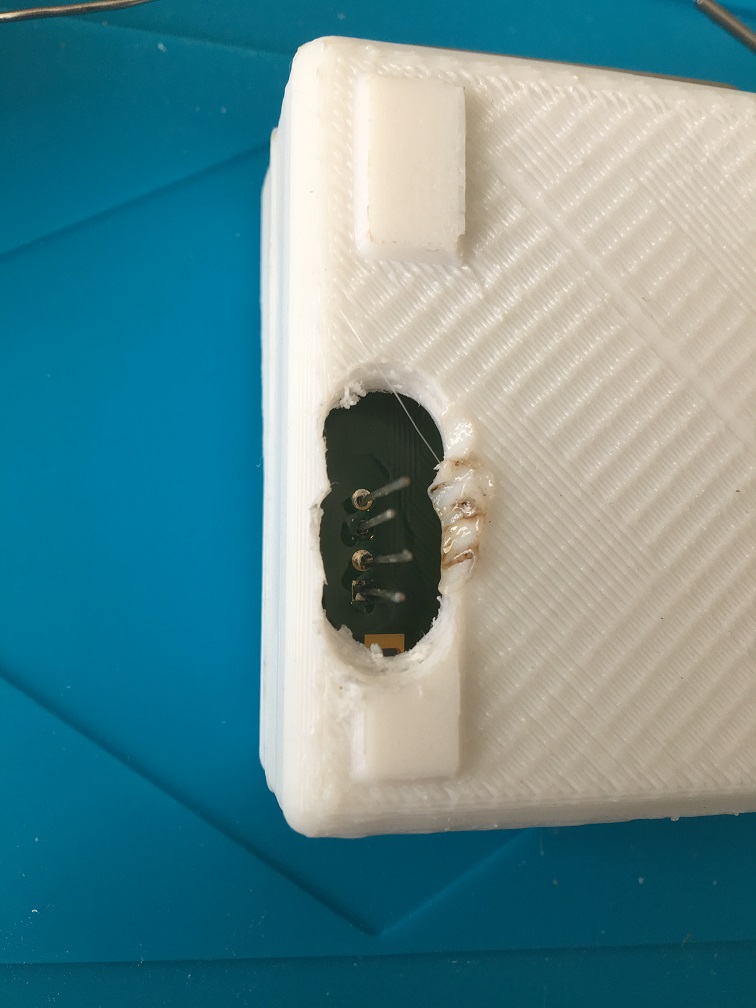
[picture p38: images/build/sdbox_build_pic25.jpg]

</a>
<a href="images/build/sdbox_build_pic26.jpg">
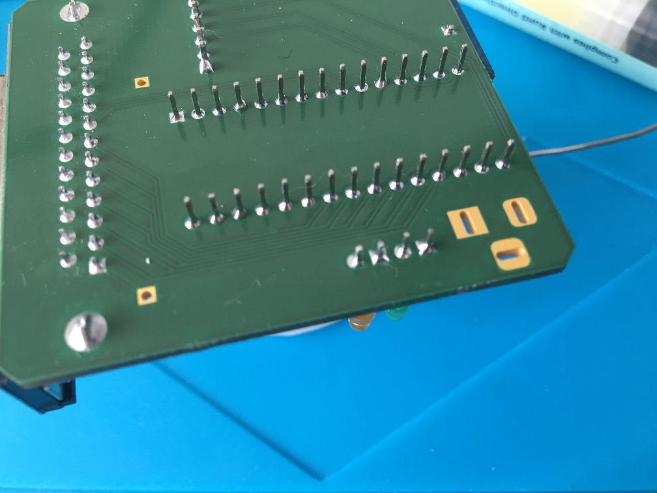
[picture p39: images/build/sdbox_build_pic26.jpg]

</a>
<a href="images/build/sdbox_build_pic27.jpg">
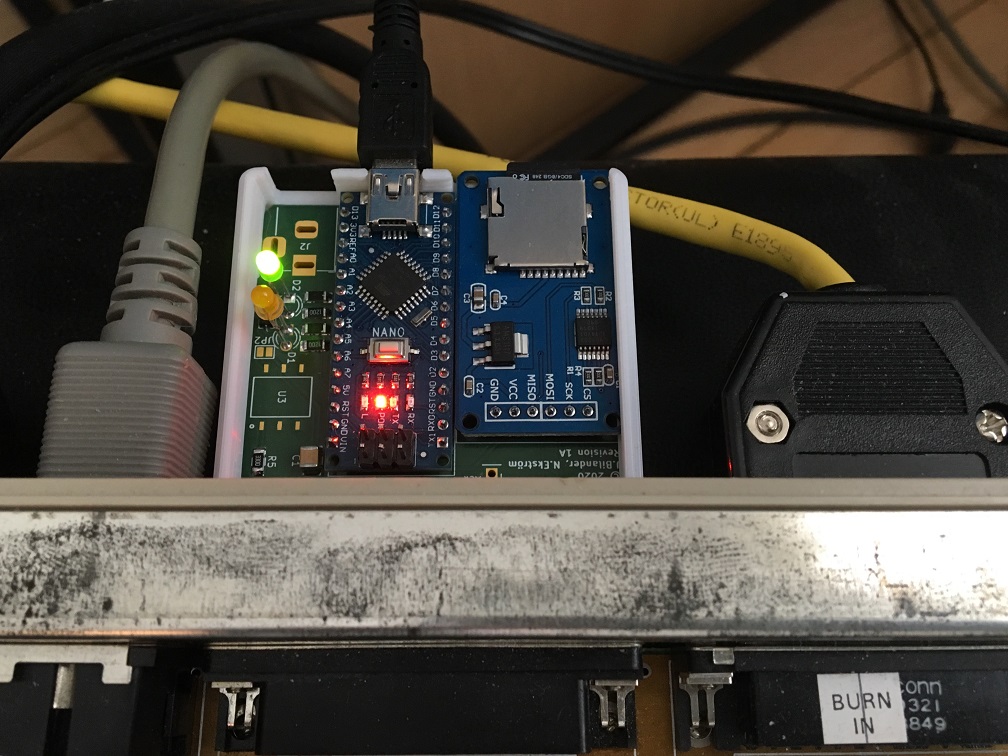
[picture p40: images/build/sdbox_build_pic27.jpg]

</a>

***
### Update: Powering via the barrel jack

So I finally got parts to try out powering the device via the optional barrel jack. It seems to work just fine. I used a `9V DC 1A`, center pin positive, adapter.

Solder the barrel jack and the solid state relay (PVG612S) to the PCB. I made a small parallel extension adapter in order to let me easily measure the control current draw of the `PVG612S`.

***

<a href="images/build/sdbox_build_pic28.jpg">

</a>
<a href="images/build/sdbox_build_pic29.jpg">

</a>
<a href="images/build/sdbox_build_pic30.jpg">

</a>

***

Video clip below, as you can see powering of the sdbox is now controlled by the Amiga's on/off and you can just leave the sdbox always connected via the barrel jack. The control current draw for the solid state relay is around `9.7 mA` which is just below the `10 mA` max recommended draw from the Amigas parallel port pin 14. Great!

https://i.imgur.com/eSkcy3X.mp4

First checking the `9V` adapter and verifying it is indeed center pin positive and outputs around 9V. It shows around `9.3V`. The current draw I measured to around `9.7 mA` with the `330 Ohm` on R5 in series with the Amigas internal `47 Ohm`. Voltage input to `PVG612S` is around `1.2V`, perfect! The `5V` on the Nano V3 shows `5.03V`, Spot On!

***

<a href="images/build/sdbox_build_pic31.jpg">

</a>
<a href="images/build/sdbox_build_pic32.jpg">

</a>
<a href="images/build/sdbox_build_pic33.jpg">

</a>
<a href="images/build/sdbox_build_pic34.jpg">

</a>
<a href="images/build/sdbox_build_pic35.jpg">

</a>

***

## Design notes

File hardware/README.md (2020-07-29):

## sdbox for Amiga

This is a PCB made in KiCad (5.1.2-1) for hooking up an Arduino Nano V3 with a micro-sd-card module to the Amiga parallel-port.

<a href="../images/sdbox_rev_1a_pic1.png">

</a>
<a href="../images/sdbox_rev_1a_pic2.png">
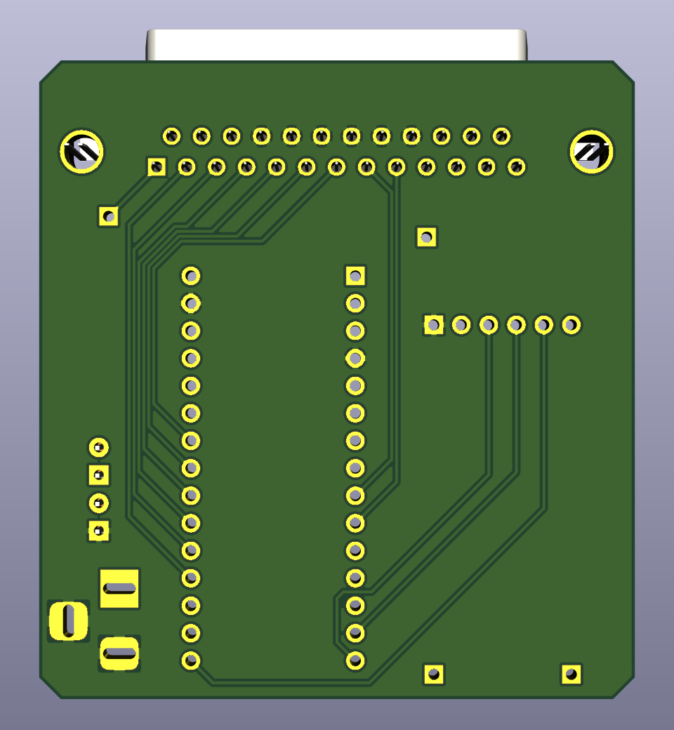
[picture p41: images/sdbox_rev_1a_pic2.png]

</a>
<a href="../images/sdbox_rev_1a_pic3.png">
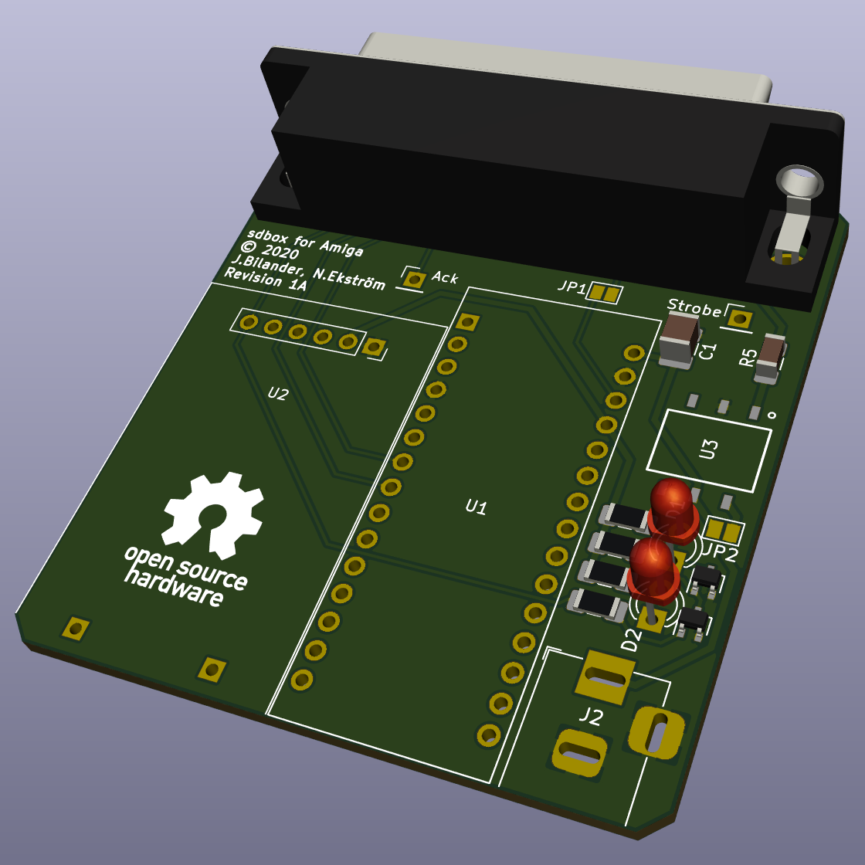
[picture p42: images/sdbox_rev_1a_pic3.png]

</a>
<a href="../images/sdbox_rev_1a_pic4.png">
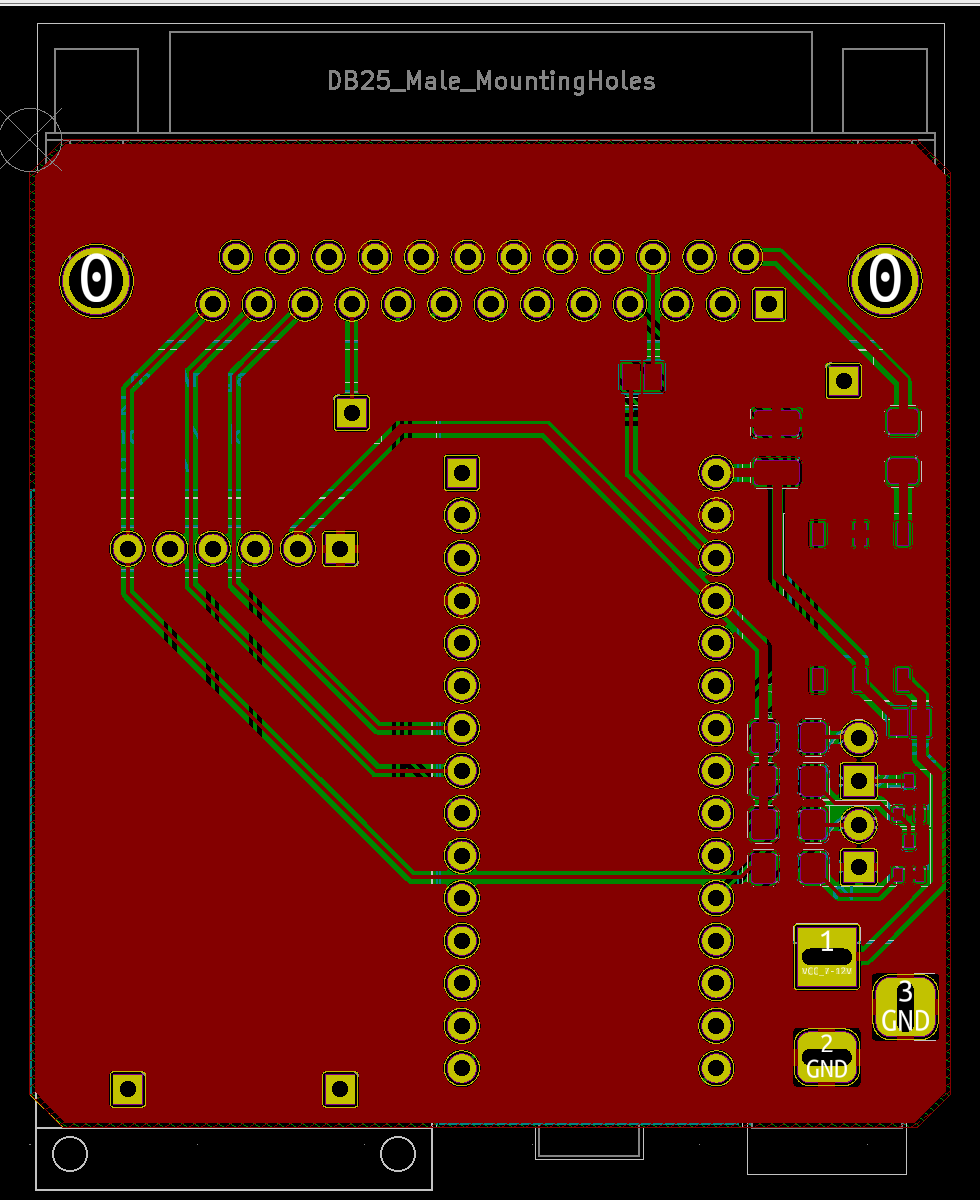
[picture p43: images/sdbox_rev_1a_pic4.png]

</a>
<a href="../images/sdbox_schematics_rev_1a.png">
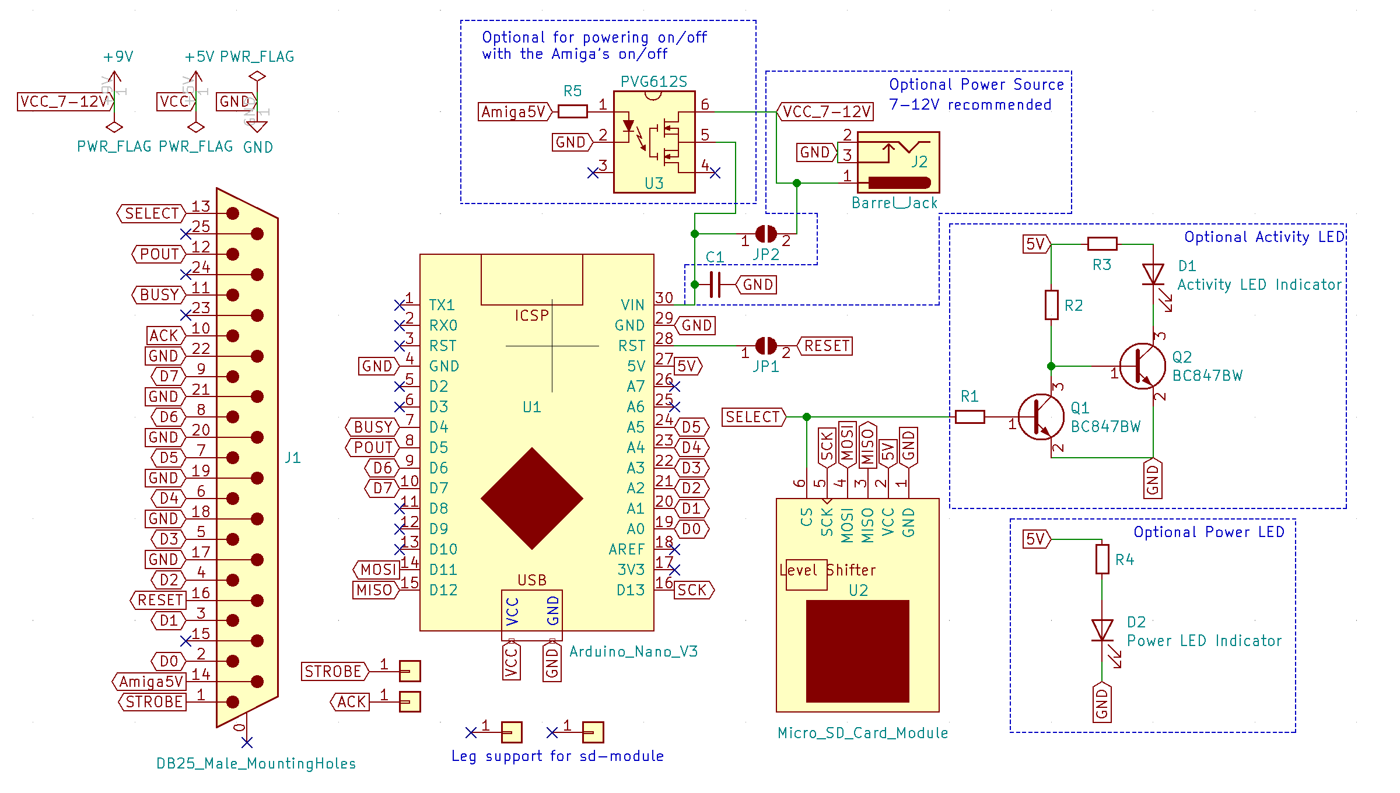
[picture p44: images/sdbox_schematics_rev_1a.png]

</a>

***

For 3d-printing the sdbox case, check the README in the DSM folder.

***

BOM, now verified!

Please note, you don't need to populate C1 if you're not going to use the barrel jack. R5 is only needed if U3 is populated.
***

PART  | Value | Description
----- | ----- | -------
U1    |       | Arduino Nano V3
U2    |       | Micro SD-Card Adapter (with onboard bidirectional level shifter)
U2    |Pin strip| 1 Pcs 2.54mm Single Row Male Pin Header Strip For mounting and connecting Micro SD-Card Adapter directly into base PCB. Cut out one with 6 pins and two with single pins. The current angled pins on module will be desoldered and removed.
U3    |PVG612S| Solid State Relay, 6-SMD (0,300", 7,62mm) Automatic power down with the Amiga (optional)
J1    |DB25   | DB25 Male MountingHoles 
J2    |5.5x2.1 mm | Barrel Jack Power Connector, center positive (optional)
C1    |100uF-220uF| 1210 ceramic decoupling capacitor for VIN, 16 VDC or at least above you voltage input 7-12V. Not needed if powering via USB.
R1    |4.7k Ohm| 1206 smd resistor (should give around 0.9mA when CS/SEL is high)
R2    |4.7k Ohm| 1206 smd resistor
R3    |120 Ohm| 1206 smd resistor (should give around 2.14V, 24 mA over D1)
R4    |120 Ohm| 1206 smd resistor (should give around 2.17V, 24 mA over D2)
R5    |330 Ohm| 1206 smd resistor (should give around 1.2V and 10 mA control current with the Amiga 47 Ohm in series from pin 14) Not needed if U3 not populated
D1    |LED 3mm| SD Activity LED, Diffused Orange / Amber, pitch 2.54 mm, 1.8V-2.3V, 20-30 mA, 605-610nm
D2    |LED 3mm| Power LED, Green Diffused T-1, pitch 2.54 mm, 25 mcd, 565 nm, 2.2 V, 25 mA
Q1    |BC847BW| Small Signal Transistor, NPN polarity, SOT-323
Q2    |BC847BW| Small Signal Transistor, NPN polarity, SOT-323
JP1   |Solder jumper| Enable this to reset Nano in conjunction with Ctrl-Amiga-Amiga
JP2   |Solder jumper| Enable this to use barrel jack connector without U3 chip

***

<a href="../images/arduino_nano_v3.jpg">
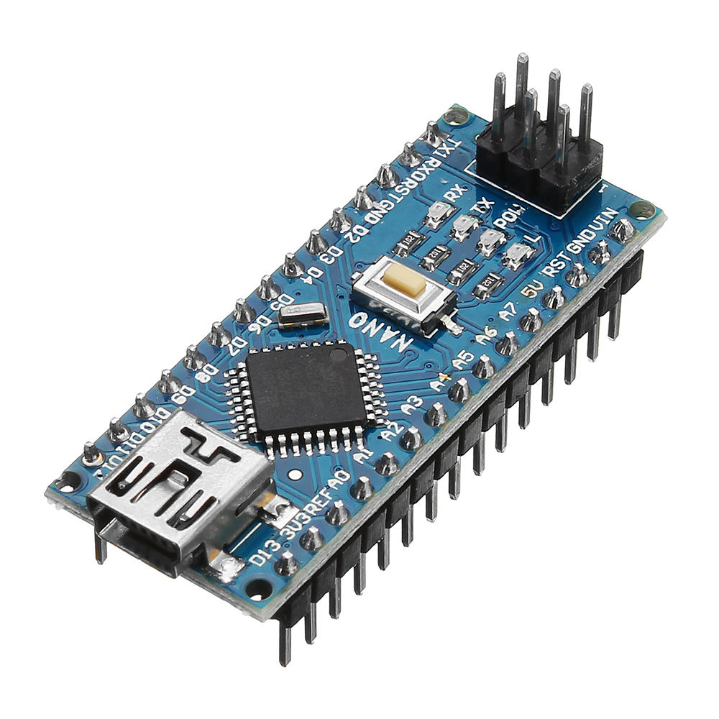
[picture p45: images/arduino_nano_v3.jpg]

</a>
<a href="../images/micro_sd_card_module.jpg">
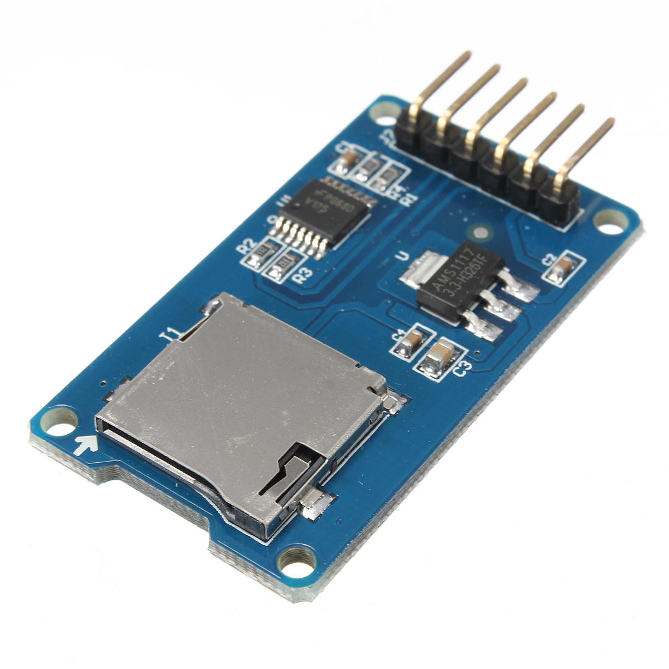
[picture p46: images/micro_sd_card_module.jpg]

</a>
<a href="../images/d-sub_db25_male_plug_solder_connector.jpg">
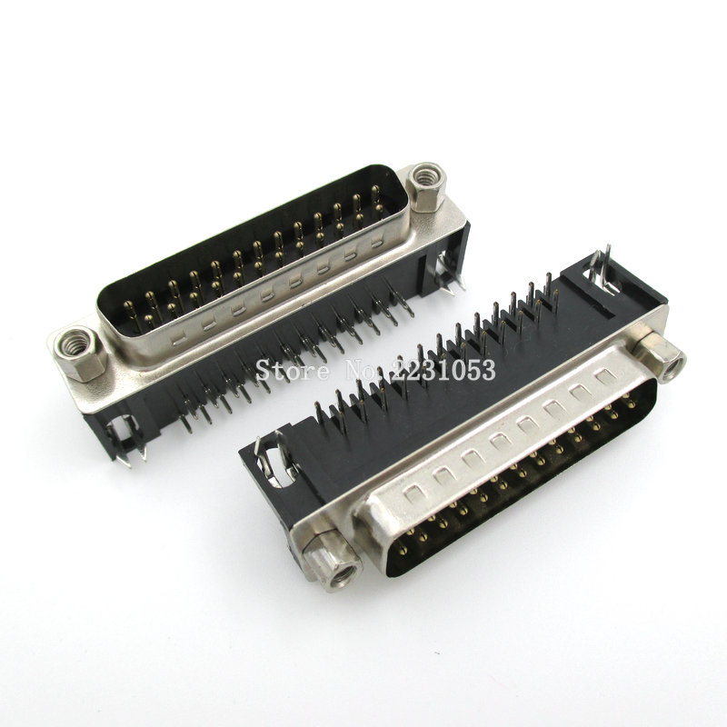
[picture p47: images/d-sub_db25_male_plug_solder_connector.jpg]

</a>
<a href="../images/barrel_jack_connector.jpg">
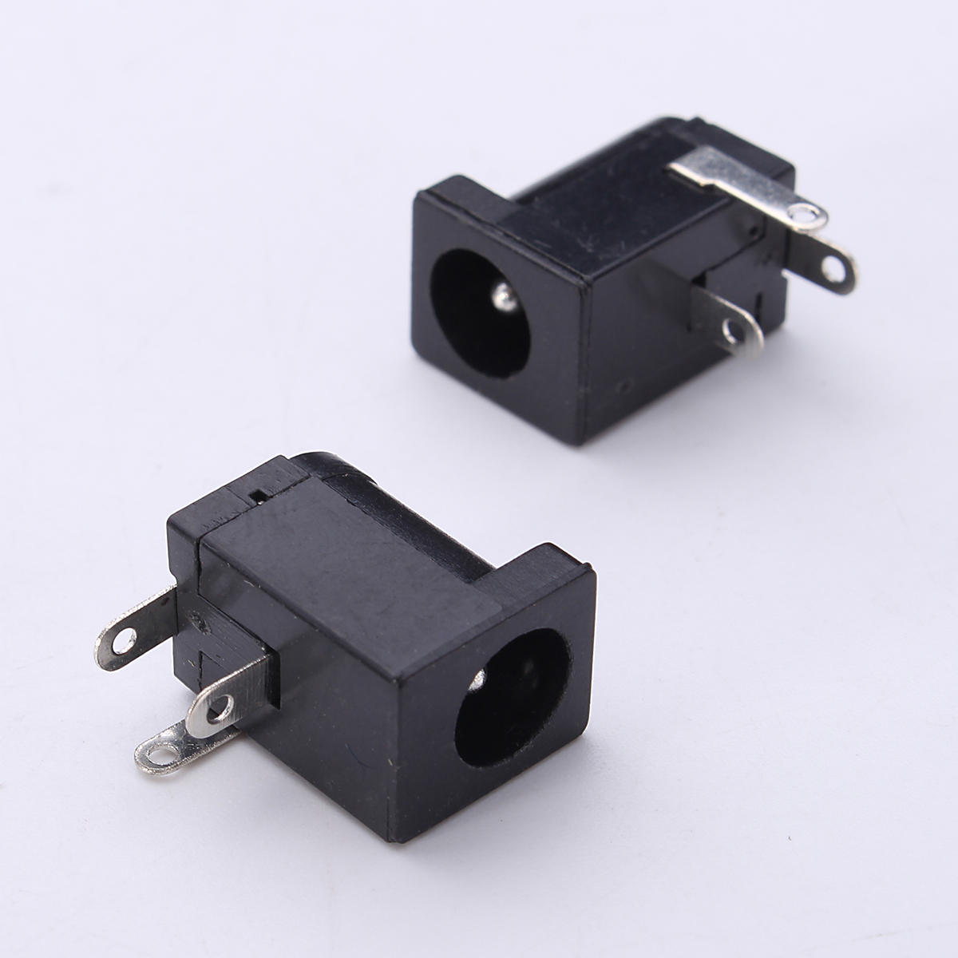
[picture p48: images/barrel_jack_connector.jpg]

</a>
<a href="../images/dc_9V_2A_AC_adapter_charger_power_supply_pic.jpg">
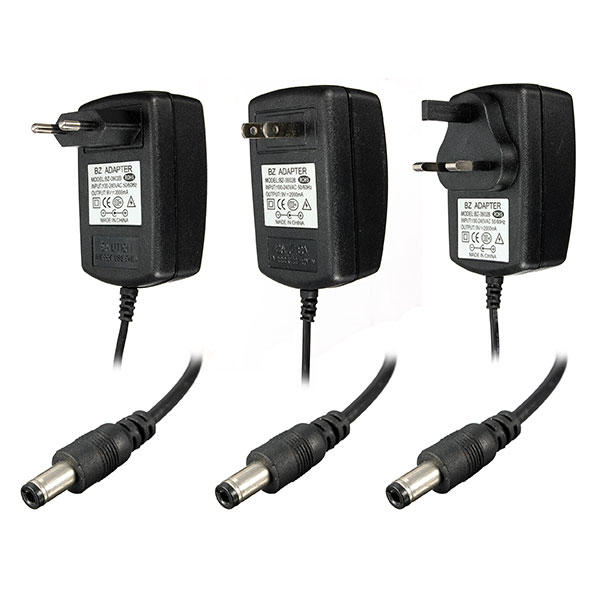
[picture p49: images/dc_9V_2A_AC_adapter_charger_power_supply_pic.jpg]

</a>

***

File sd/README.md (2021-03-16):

# SD card module

An SD card module can be used with the SPI adapter in order to mount the SD card as a volume in AmigaOS.
This driver uses the code written by Mike Sterling: https://github.com/mikestir/k1208-drivers/tree/master/sd. Thanks Mike!

The file `sd.c` does all the heavy lifiting and remains largely unchanged compared to Mike's original. 

Typing `make` will produce the binary spisd.device which should go into the DEVS: directory.

Install the [fat95 file system handler](http://aminet.net/package/disk/misc/fat95) in L: and copy the mountfile `SD0` (available in the `amiga` folder of this repo) to some suitable place e.g. `Devs` where it can be used to mount the SD card on demand by simply double-clicking the icon (read more about how this works in other places, e.g. the fat95 documentation). For automatic mount on boot put the `SD0` file in the `Devs/DOSDrivers` folder.

### Build the spisd.device driver with gcc-2.95.3 https://github.com/adtools/amigaos-cross-toolchain in path:

    jbilander@apollo:~/projects/sdbox$ make
    make -C sd
    make[1]: Entering directory '/home/jbilander/projects/sdbox/sd'
    mkdir build-device
    m68k-amigaos-gcc -m68000 -s -O2 -Wall -fomit-frame-pointer -noixemul -fbaserel -I. -I../common -ramiga-dev -c -o build-device/device.o device.c
    m68k-amigaos-gcc -m68000 -s -O2 -Wall -fomit-frame-pointer -noixemul -fbaserel -I. -I../common -ramiga-dev -c -o build-device/spi-par.o ../common/spi-par.c
    m68k-amigaos-as -m68000  -o build-device/spi-par-low.o ../common/spi-par-low.s
    m68k-amigaos-gcc -m68000 -s -O2 -Wall -fomit-frame-pointer -noixemul -fbaserel -I. -I../common -ramiga-dev -c -o build-device/sd.o sd.c
    m68k-amigaos-gcc -m68000 -s -O2 -Wall -fomit-frame-pointer -noixemul -fbaserel -I. -I../common -ramiga-dev -c -o build-device/timer.o ../common/timer.c
    m68k-amigaos-gcc -m68000 -s -O2 -Wall -fomit-frame-pointer -noixemul -fbaserel -I. -I../common -ramiga-dev -Wl,-Map=build-device/spisd.device.map  -o build-device/spisd.device build-device/device.o build-device/spi-par.o build-device/spi-par-low.o build-device/sd.o build-device/timer.o
    make[1]: Leaving directory '/home/jbilander/projects/sdbox/sd'
    jbilander@apollo:~/projects/sdbox$ cd sd/build-device/
    jbilander@apollo:~/projects/sdbox/sd/build-device$ ls -al
    total 61
    drwxrwxr-x 2 jbilander jbilander    9 Jun  7 23:43 .
    drwxrwxr-x 3 jbilander jbilander    9 Jun  7 23:43 ..
    -rw-rw-r-- 1 jbilander jbilander 1810 Jun  7 23:43 device.o
    -rw-rw-r-- 1 jbilander jbilander 2995 Jun  7 23:43 sd.o
    -rw-rw-r-- 1 jbilander jbilander 1059 Jun  7 23:43 spi-par-low.o
    -rw-rw-r-- 1 jbilander jbilander 1375 Jun  7 23:43 spi-par.o
    -rwxrwxr-x 1 jbilander jbilander 5044 Jun  7 23:43 spisd.device
    -rw-rw-r-- 1 jbilander jbilander 9521 Jun  7 23:43 spisd.device.map
    -rw-rw-r-- 1 jbilander jbilander  294 Jun  7 23:43 timer.o
    jbilander@apollo:~/projects/sdbox/sd/build-device$

***

Mounting `SD0:` on demand by double clicking the `SD0` file, you can also type `mount SD0:` in a shell-prompt.

<a href="../images/screenshots/on_demand_mounting_sd0.jpg">
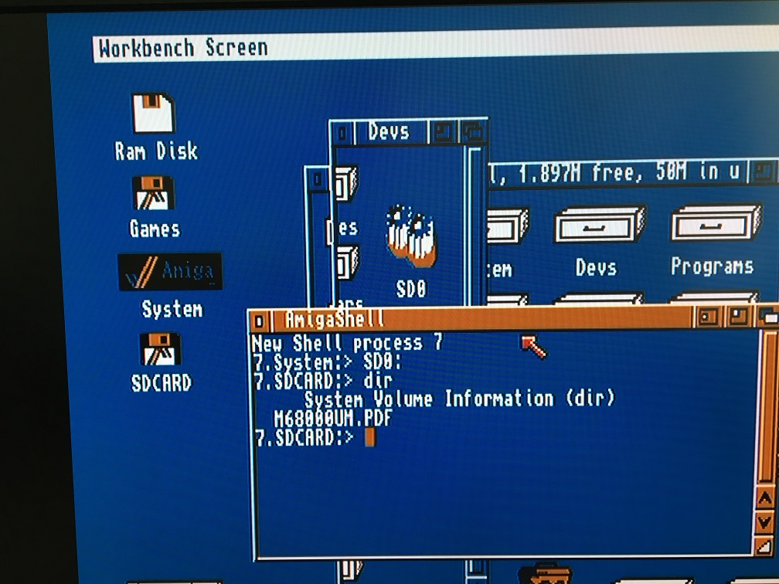
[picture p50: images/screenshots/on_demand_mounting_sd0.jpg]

</a>

***

### Running sdbox on a stock A500 with wb 1.3 on KS 1.3 booting from floppy with drivers installed

Running sdbox on a stock A500 with wb 1.3 on KS 1.3 original mask rom `v34.5` and booting wb adf (via gotek) with sdbox-drivers included. I removed the `printer.device` and the `printers` directory in order to get free space to fit the drivers on the floppy image.

<a href="../images/sdbox_on_stock_A500_gotek_boot.jpg">
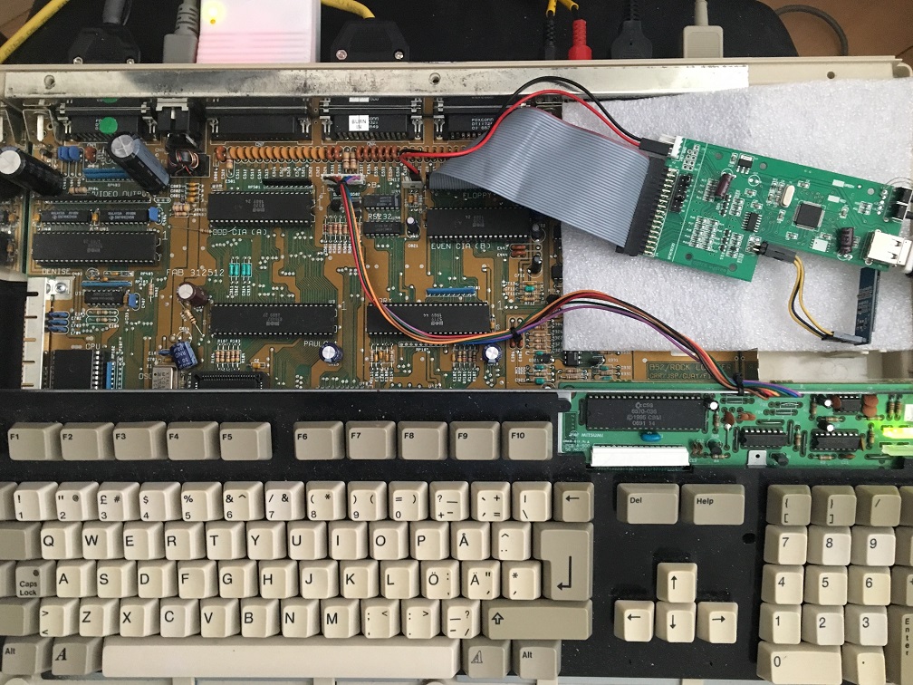
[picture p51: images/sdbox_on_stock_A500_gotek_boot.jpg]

</a><br />

Verifed working :
* `wb 1.3 (v34.20)` (`BlockSize = 512` needs to be removed and the entry `Reserved = 0` to be in the mountfile `SD0`)
* `wb 1.3.2 (v34.28)` (Requires `BlockSize = 512` entry in mountfile)
* `wb 1.3.3 (v34.34)` (Requires `BlockSize = 512` entry in mountfile)

Each entry must begin with the device name (in this case, `SD0:`) and must end with a number sign `#`.

    SD0:  FileSystem     = l:fat95
        Device         = spisd.device
        Unit           = 0
        Flags          = 0
        LowCyl         = 0
        HighCyl        = 0
        Surfaces       = 1
        BlocksPerTrack = 1
        BlockSize      = 512
        Reserved       = 0
        Buffers        = 20
        BufMemType     = 1
        BootPri        = 0
        StackSize      = 4096
        Priority       = 5
        GlobVec        = -1
        DosType        = 0x46415401
    #

<a href="../images/screenshots/wb_1.3_v34.20.jpg">
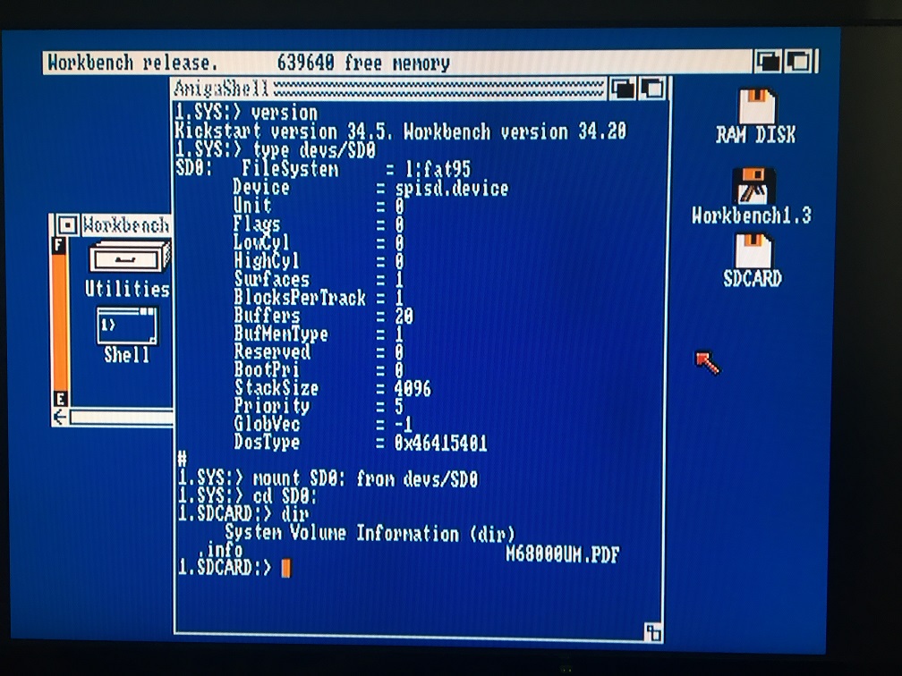
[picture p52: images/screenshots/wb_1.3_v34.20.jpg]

</a>
<a href="../images/screenshots/wb_1.3.2_v34.28.jpg">
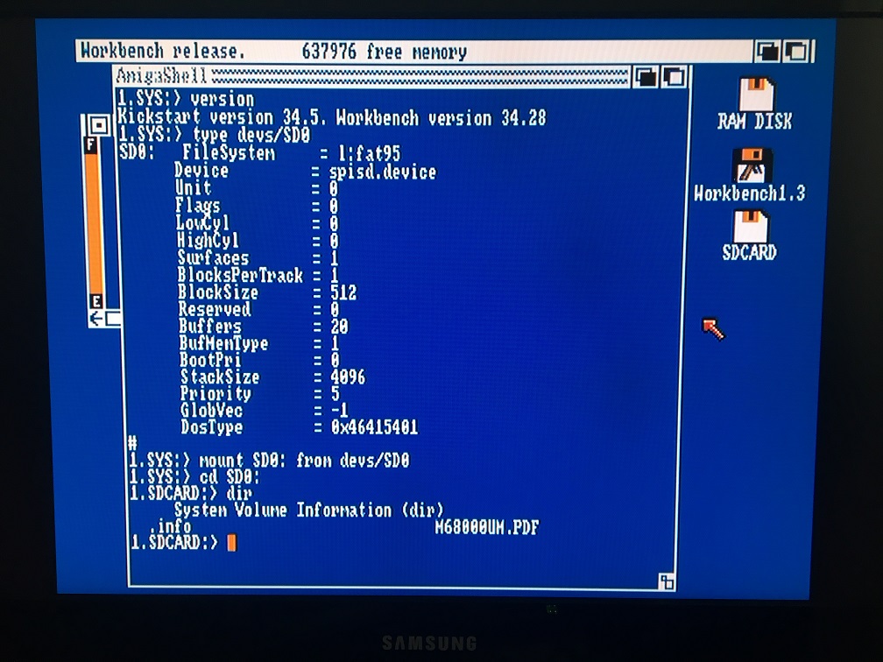
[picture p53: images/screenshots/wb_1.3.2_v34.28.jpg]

</a>
<a href="../images/screenshots/wb_1.3.3_v34.34.jpg">
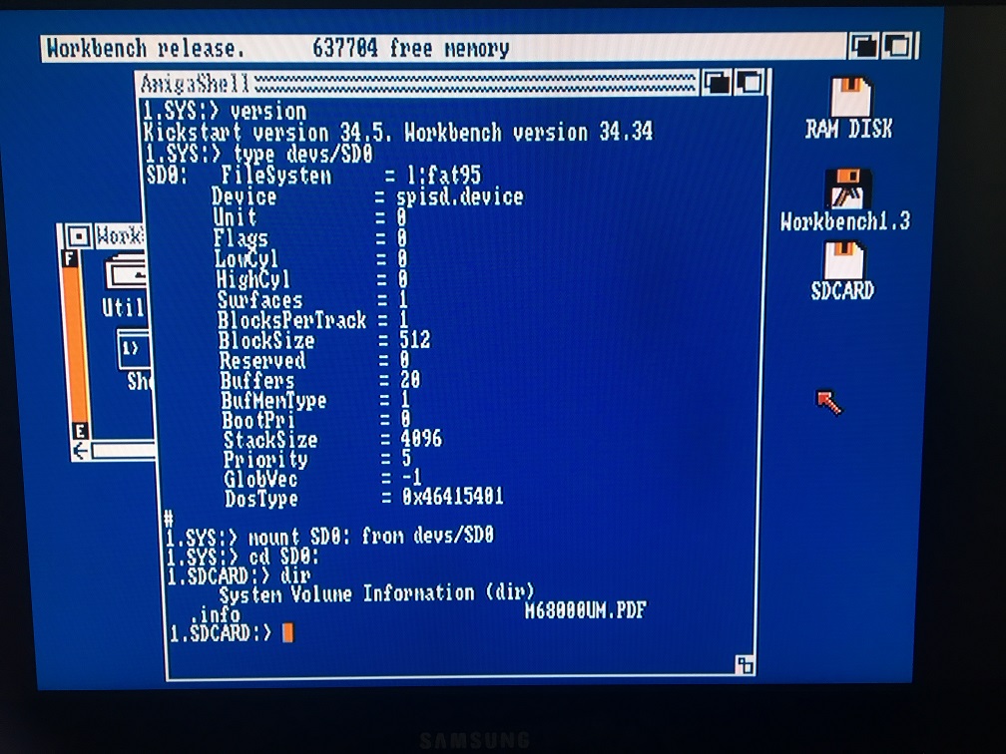
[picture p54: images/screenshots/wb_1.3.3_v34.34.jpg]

</a><br />
<br />

Please note, in order to see files and folders appear as icons in wb 1.3 you need `*.info` files of correct type that matches the names of your folder or file since 1.3 doesn't seem to have a "show all folder and files" option.

***

### Running sdbox on a stock A500 with wb 3.1 on KS 3.1 booting from floppy with drivers installed

You can mount either via command line or double-click the SD0 file:

<a href="../images/screenshots/wb_3.1_v40.42_pic1.jpg">
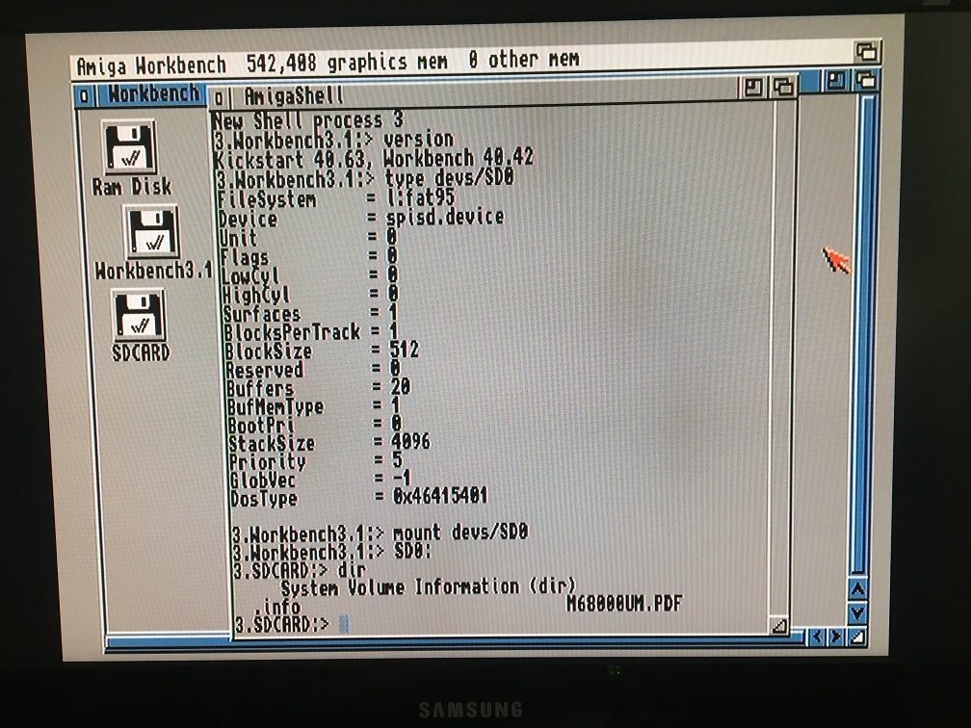
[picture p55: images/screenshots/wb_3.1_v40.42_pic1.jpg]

</a>
<a href="../images/screenshots/wb_3.1_v40.42_pic2.jpg">
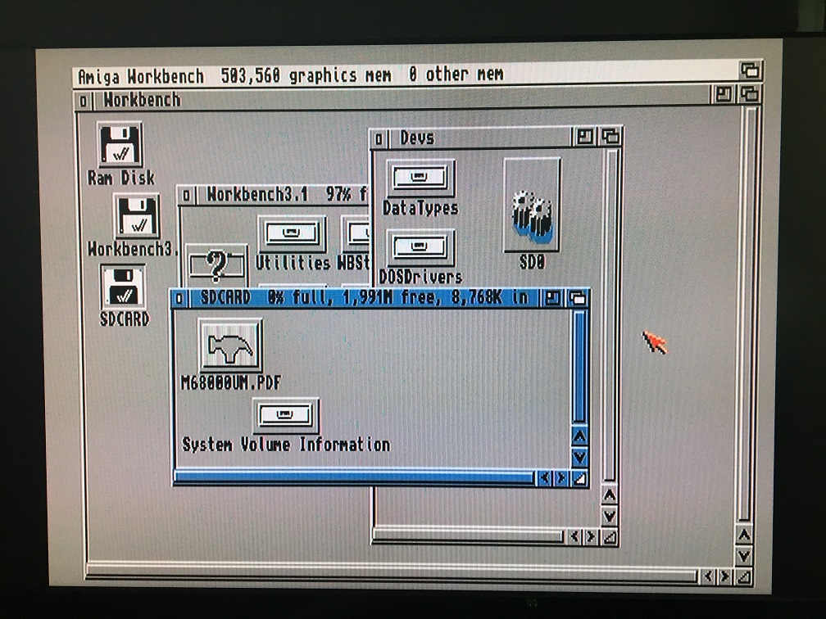
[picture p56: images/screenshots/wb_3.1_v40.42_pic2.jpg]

</a>

***

### Running sdbox on a A1200

<a href="../images/sdbox_installed_on_A1200_pic1.jpg">
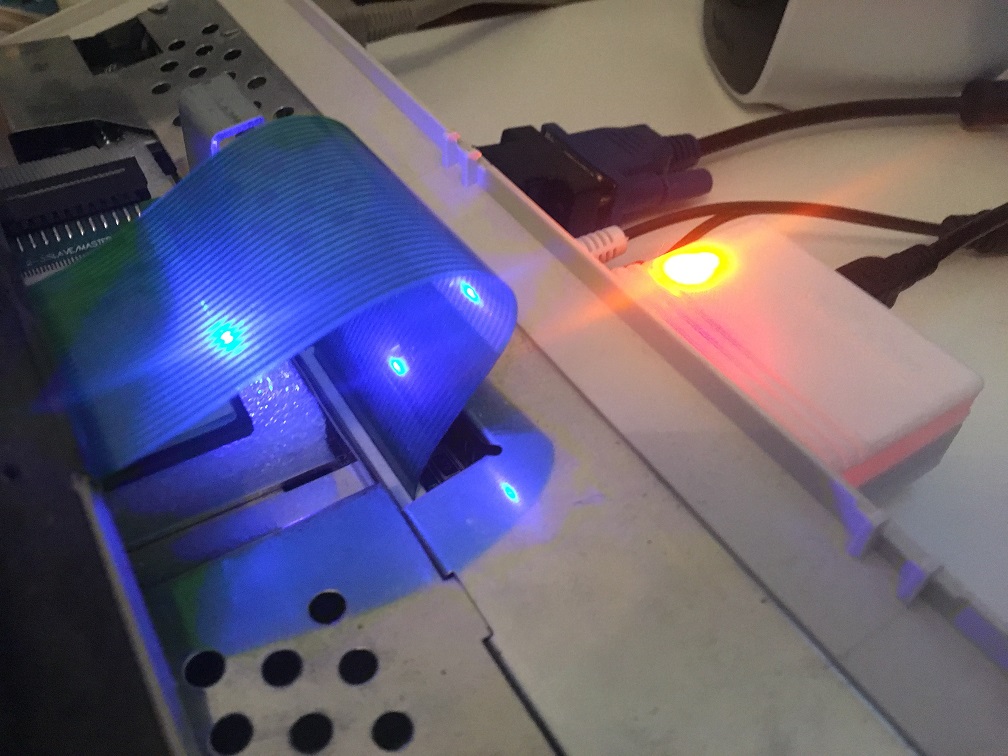
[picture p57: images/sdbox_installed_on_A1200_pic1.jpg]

</a>
<a href="../images/sdbox_installed_on_A1200_pic2.jpg">
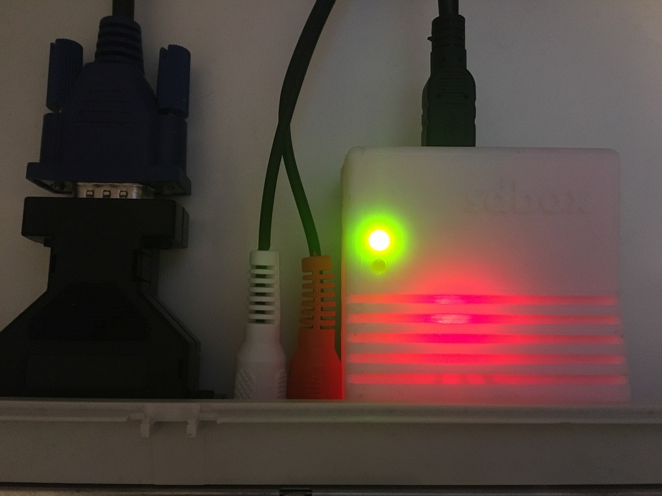
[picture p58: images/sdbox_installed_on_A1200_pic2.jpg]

</a><br />
<a href="../images/screenshots/copying_drag_n_drop_A1200_314_pic1.jpg">
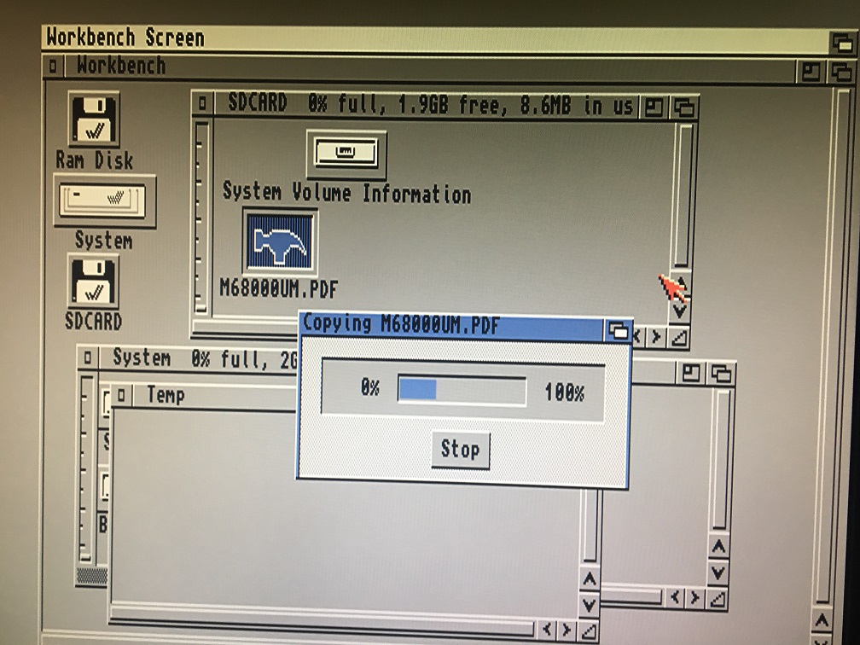
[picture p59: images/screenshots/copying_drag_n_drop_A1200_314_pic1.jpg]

</a>
<a href="../images/screenshots/copying_drag_n_drop_A1200_314_pic2.jpg">
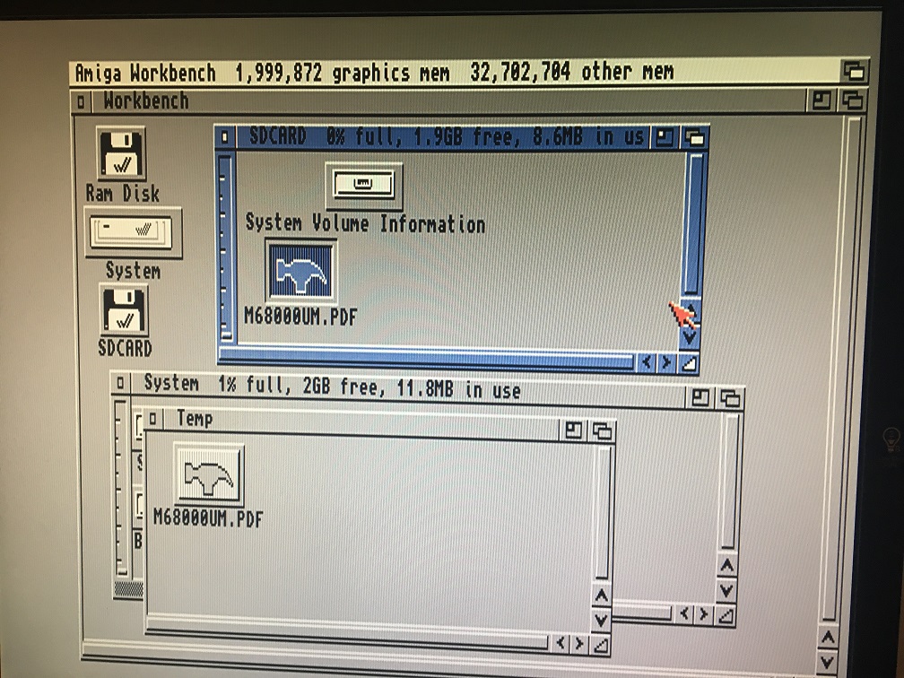
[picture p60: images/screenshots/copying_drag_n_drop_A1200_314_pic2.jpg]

</a>

***

Copying driver file over via Kermit (`cki196.exe` for Amiga 3.1) and a null modem cable:

<a href="../images/screenshots/kermit_transfer_pic1.jpg">
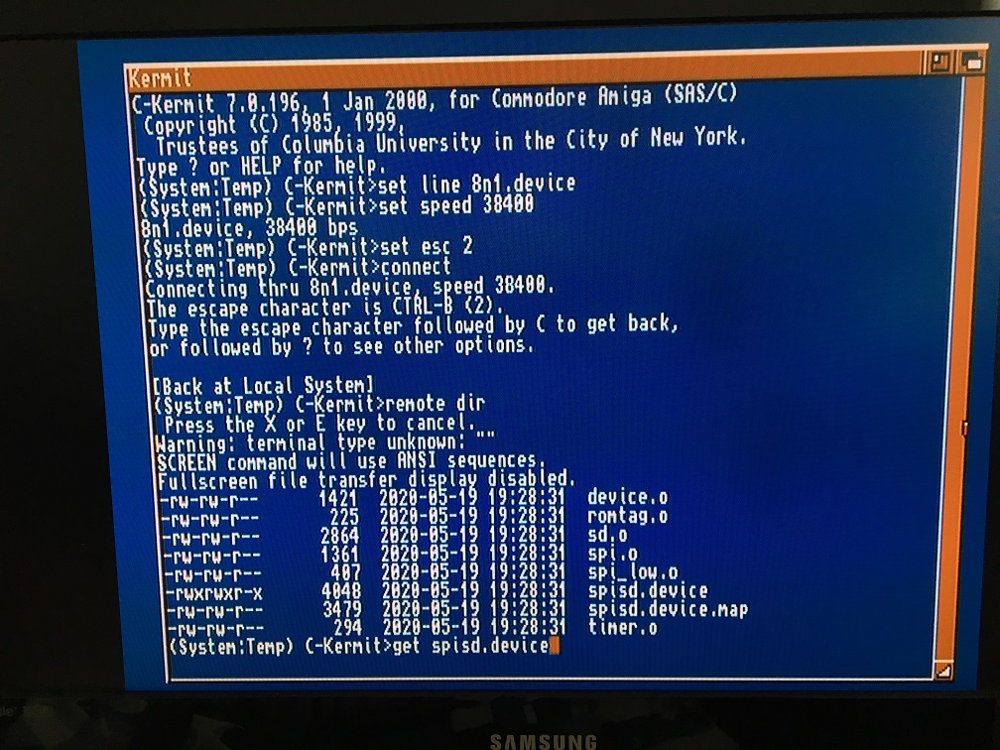
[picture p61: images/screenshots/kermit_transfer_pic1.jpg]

</a>

<a href="../images/screenshots/kermit_transfer_pic2.jpg">
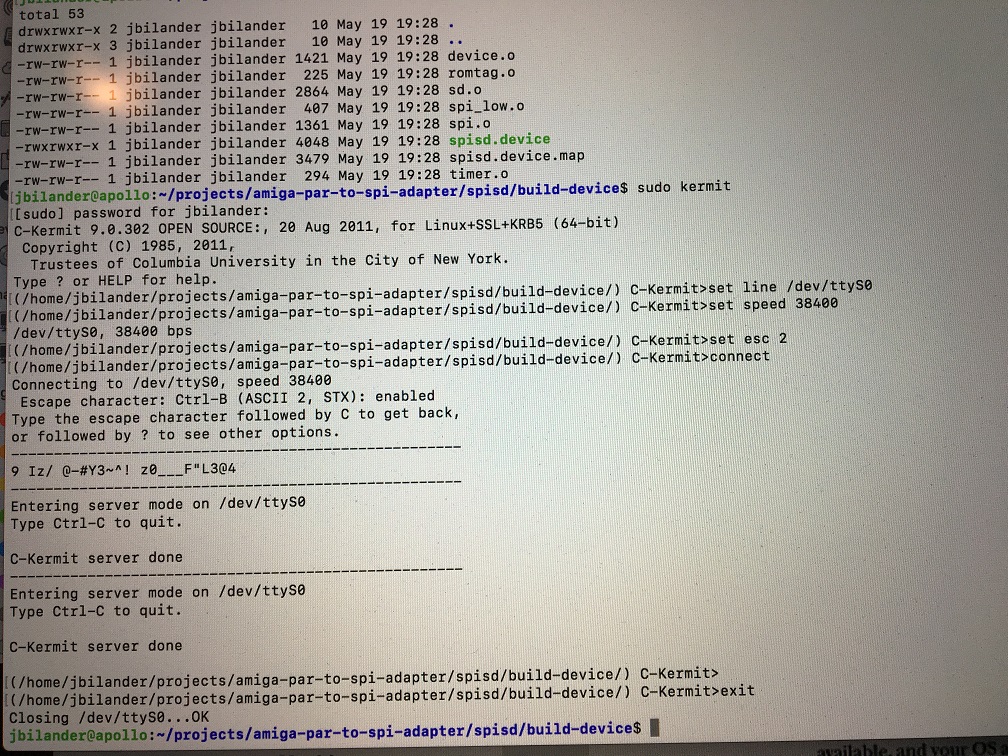
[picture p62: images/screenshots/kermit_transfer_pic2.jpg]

</a>

***

If you get the `bad number`error when trying to access `SDO:` after mounting the `SD0` file it may be an indication that your card isn't compatible with the sdbox for some reason. Probably you need a 10k pull-up resistor on the MISO-line, check under the Issues tab for how to do this. You can follow SukkoPera's instructions of where to solder the pull-up resistor. Many thanks to SukkoPera for contributing. You can check for activity on MISO/MOSI if you have access to an oscilloscope or a logic analyzer.

<a href="../images/screenshots/bad_number_error_mounting_sd0.jpg">
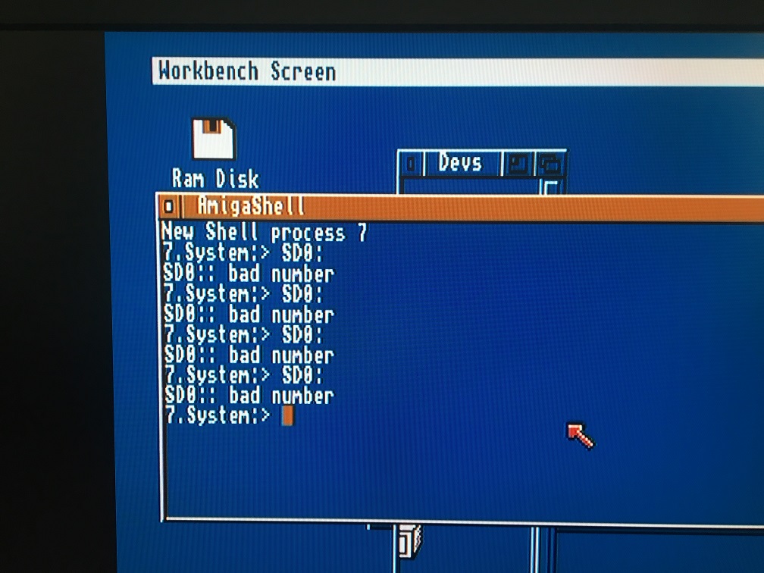
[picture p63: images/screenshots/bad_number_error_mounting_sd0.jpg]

</a>

***

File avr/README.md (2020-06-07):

# AVR microcontroller code

The AVR code is carefully timed.
For each byte that is read or written, the AVR has 45 clock cycles (at 16 MHz) to:

- start an SPI tranfer
- wait until the SPI transfer is complete
- wait until the Amiga signals that it is ready to receive or send a byte
- read/write the byte to send/receive

## Building and flashing

On Linux: running `make` will build the hex file and flash it to the AVR using the Arduino boot loader method. You can use `make build` and `make flash` to perform the steps individually.

On Windows: `build.bat` builds the hex file, and `flash.bat` flashes it. These batch files assumes that you have installed the Arduino IDE in the usual location. Note that you have to update which COM port the Arduino is connected to in flash.bat.

## Flashing with old bootloader

If you get sync errors when flashing the Nano V3 you might have a Nano with the old bootloader. To flash use `-b57600` setting instead and it should work fine, like this:

<a href="../images/flash_avr_windows.jpg">
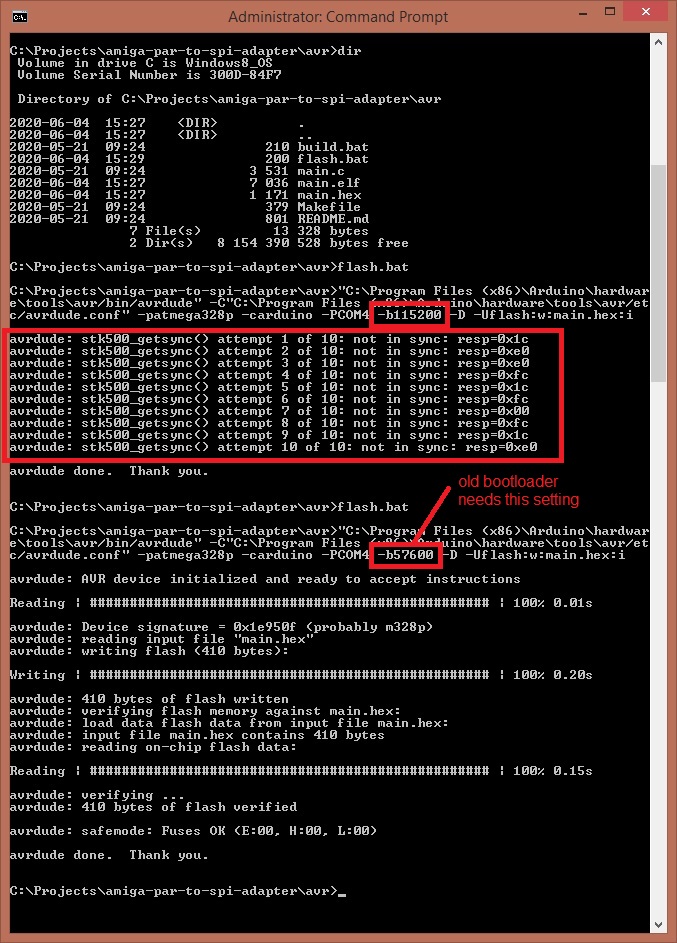
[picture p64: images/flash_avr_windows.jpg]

</a>

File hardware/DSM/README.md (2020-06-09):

### 3d-models

The 3d-model of the sdbox is constructed in DesignSpark Mechanical V4.

The sdbox is designed by me and `Tobias Niva` (niva3d) http://www.niva3d.com/ TN's renderings made in Blender can be found in the repo under `images/_renders`

Exported obj-files is available under the `obj` directory.

The font used for the sdbox is the one below, using the 3d-text function in Sketch and importing it into DSM v4

<a href="../../images/sdbox_text_settings.jpg">

</a>

# 3d-printing the sdbox case

### Printing the bottom part

I used these settings when slicing the stl in Cura, they work well for me when printing in PLA with Mr Ender.

<a href="../../images/3d_printing/cura_sdbox_case_bottom_print.jpg">

</a>

***
<a href="../../images/3d_printing/3d_printing_pic1.jpg">

</a>
<a href="../../images/3d_printing/3d_printing_pic2.jpg">

</a>
<a href="../../images/3d_printing/3d_printing_pic3.jpg">

</a>
<a href="../../images/3d_printing/3d_printing_pic4.jpg">

</a>
<a href="../../images/3d_printing/3d_printing_pic5.jpg">

</a>
<a href="../../images/3d_printing/3d_printing_pic6.jpg">

</a>
<a href="../../images/3d_printing/3d_printing_pic7.jpg">

</a>
<a href="../../images/3d_printing/3d_printing_pic8.jpg">

</a>
<a href="../../images/3d_printing/3d_printing_pic9.jpg">

</a>
<a href="../../images/3d_printing/3d_printing_pic10.jpg">

</a>

***

### Printing the top part

I used these settings when slicing the stl in Cura, they work well for me when printing in PLA with Mr Ender.

<a href="../../images/3d_printing/cura_sdbox_case_top_print.jpg">

</a>

***

<a href="../../images/3d_printing/3d_printing_pic11.jpg">

</a>
<a href="../../images/3d_printing/3d_printing_pic12.jpg">

</a>
<a href="../../images/3d_printing/3d_printing_pic13.jpg">

</a>
<a href="../../images/3d_printing/3d_printing_pic14.jpg">

</a>
<a href="../../images/3d_printing/3d_printing_pic15.jpg">

</a>
<a href="../../images/3d_printing/3d_printing_pic16.jpg">

</a>
<a href="../../images/3d_printing/3d_printing_pic17.jpg">

</a>
<a href="../../images/3d_printing/3d_printing_pic18.jpg">

</a>
<a href="../../images/3d_printing/3d_printing_pic19.jpg">

</a>

***

### Printing the front cover

When printing the front cover I used similar settings but had to make a slightly smaller model of the cover because it didn't fit otherwise, probably it expands somewhat on the heat bed, even using that smaller model you will have to trim it on the locking mechanism to make it fit perfectly.

<a href="../../images/3d_printing/cura_sdbox_case_plate_print_slightly_smaller.jpg">

</a>

***

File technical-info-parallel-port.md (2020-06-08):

The parallel port (centronics interface) pinout for A1000, A500/A2000 and PC. On the Amiga 1000 some lines are used differently and the connector is of db25 female type.

              PIN     A1000                 A500/A2000        PC
    ---------------------------------------------------------------------             
    Output      1     /DRDY (data ready)    /STROBE           /STROBE
    I/O         2     Data 0                Data 0            Data 0
    I/O         3     Data 1                Data 1            Data 1
    I/O         4     Data 2                Data 2            Data 2
    I/O         5     Data 3                Data 3            Data 3
    I/O         6     Data 4                Data 4            Data 4
    I/O         7     Data 5                Data 5            Data 5
    I/O         8     Data 6                Data 6            Data 6
    I/O         9     Data 7                Data 7            Data 7
    Input      10     /ACK (data received)  /ACK              /ACK
    I/O        11     BUSY (data)           BUSY              BUSY
    I/O        12     POUT (clk, Paper Out) POUT              POUT
    I/O        13     SEL (printer online)  SEL               SEL
               14     GND                   +5V Pullup        /AUTOFDXT
               15     GND                   NC (Unused)       /ERROR
               16     GND                   /RESET*           /INIT                  
               17     GND                   GND               /SLCT IN                           
            18-22     GND                   GND               GND
               23     +5V Pullup            GND               GND
               24     NC (Unused)           GND               GND
               25     /RESET*               GND               GND
    
    * Buffered reset line from the Amiga (Output)
***    

The Centronics interface on the Amiga should bring joy to any hacker's heart. It is completely PC compatible. Unfortunately, the Amiga 1000 Centronics port does not conform to the PC standard. First, a female connector was used instead of the usual male db25 connector, and second pin 23 is +5V instead of ground as it is usually on most printer cables. If such a cable is used with the A1000, a short occurs and the Amiga can be damaged.

Internally all the Centronics port lines (except for +5V and Reset) are connected directly to the port lines of the individual CIA's. The exact assignment are as follows:

***

    Centronics Pin No.     Function        CIA     Pin  Pin designation
                1           Strobe          A       18      /PC
                2           Data bit 0      A       10      PB0
                3           Data bit 1      A       11      PB1
                4           Data bit 2      A       12      PB2
                5           Data bit 3      A       13      PB3
                6           Data bit 4      A       14      PB4
                7           Data bit 5      A       15      PB5
                8           Data bit 6      A       16      PB6
                9           Data bit 7      A       17      PB7
               10           Acknowledge     A       24      /FLAG
               11           Busy            B        2      PA0
                                                and 39      SP
               12           Paper Out       B        3      PA1
                                                and 40      CNT
               13           Select          B        4      PA2
 
***
Datasheet: http://archive.6502.org/datasheets/mos_6526_cia_recreated.pdf
* 8520 is functionally equivalent to the 6526 except for the simplified TOD circuitry. 
***

The Centronics interface is a parallel interface. The data byte lies on the eight data lines. When the computer has placed a valid byte on the data lines it clears the STROBE line to 0 for 1.4 microseconds, signalling the printer that a valid byte is ready for it. The printer must then acknowledge this by pulling the Ack line low for at least one microsecond. The computer then place the next byte on the bus.

The printer uses the BUSY line to indicate that it is occupied and can not accept any more data at the moment. This occurs when the printer buffer is full, for example. The computer then waits until BUSY goes high again before it continues sending data. With the Paper Out line the printer tells the computer that it is out of paper. The select line is also controlled by the printer and indicates whether it is ONLINE (selected, SEL high) or OFFLINE (unselected, SEL low).

The Centronics port is well suited as a universal interface for connecting home-built expansions such as an audio digitizer or an EPROM burner, since almost all of the lines can be programmed to be either inputs or outputs.

***

8520A CIA-A  | (Complex Interface Adapter, ODD CIA at U7)
------------ | -------------
/IRQ         | /INT2 input from Paula, Low Priority Interrrupt Request
/RES         | System reset line
D0-D7        | Processor data bus bits 0-7
A0-A3        | Processor address bus bits 8-11
φ2           | Processor E clock
R/W          | Processor R/W
PA7          | Game port 1 pin 6 (fire button)
PA6          | Game port 0 pin 6 (fire button)
PA5          | /RDY    "disk ready" signal from the disk drive
PA4          | /TK0    "disk track 00" signal from disk drive
PA3          | /WPRO   "write protect" signal from disk drive
PA2          | /CHNG   "disk change" signal from disk drive
PA1          | LED     Control over the power LED (0=on, 1=off)
PA0          | OVL     memory overlay bit (do not change!)
SP           | KDAT    Serial keyboard data
CNT          | KCLK    Clock for keyboard data
&#x1F535;  **_PB0-PB7_**| **_Centronics port data lines_**
&#x1F535;  **_PC_**     | **_/DRDY     Centronics handshake signal: data ready (Strobe)_**
&#x1F535;  **_FLAG_**  | **_/ACK       Centronics handshake signal: data acknowledge_**

***

8520A CIA-B  | (Complex Interface Adapter, EVEN CIA at U8)
------------ | -------------
/IRQ         | /INT6 input from Paula, High Priority Interrupt Request
/RES         | System reset line
D0-D7        | Processor data bus bits 8-15
A0-A3        | Processor address bus bits 8-11
φ2           | Processor E clock
R/W          | Processor R/W
PA7          | /DTR serial interface, /DTR signal
PA6          | /RTS serial interface, /RTS signal
PA5          | /CD serial interface, /CD signal
PA4          | /CTS serial interface, /CTS signal
PA3          | /DSR serial interface, /DSR signal
&#x1F535; **_PA2_**| **_SEL Centronics "select" signal_**
&#x1F535; **_PA1_**| **_POUT Centronics "paper out" signal_**
&#x1F535; **_PA0_**| **_BUSY Centronics "busy" signal_**
&#x1F535; **_SP_** | **_BUSY connected directly to PA0_**
&#x1F535; **_CNT_**| **_POUT connected directly to PA1_**
PB7          | /MTR "motor" signal to disk drive
PB6          | /SEL3 "drive select" for drive 3
PB5          | /SEL2 "drive select" for drive 2
PB4          | /SEL1 "drive select" for drive 1
PB3          | /SEL0 "drive select" for drive 0 (internal)
PB2          | /SIDE "side select" signal to disk drive
PB1          | DIR "direction" signal to disk drive
PB0          | /STEP "step" signal to disk drive
FLAG         | /INDEX "index" signal from disk drive
PC           | not used

***

The 8250 has the following features: two programmable 8-bit parallel ports (PA and PB), two 16-bit timers (A and B), a bidirectional serial port (SP) and a 24-bit counter (event counter) with an alarm function upon reaching a programmed value. All of the functions can generate interrupts.

The addresses `$BFE001` for CIA-A and `$BFD000` for CIA-B are the base of the CIAs specified by Commodore. The selection between the two CIAs is made with address line A12 and A13. CIA-A is selected when `A12=0` and CIA-B is selected when `A13=0`. Since the data bus of CIA-A is connected to processor data lines `D0-D7 (odd addresses)` and CIA-B to `D8-D15 (even addresses)`, the two can be accessed together in one word access if `A12` and `A13` are both 0.

The addressing scheme for the CIA's can be summarized as follows. CIA-A is selected by the following addresses (binary):

    101x xxxx xxx0 rrrr xxxx xxx1
    
and CIA-B by:

    101x xxxx xx0x rrrr xxxx xxx0
    
The function of the 8250 are organixed in 16 registers. The four bits designated rrrr select the corresponding registers. The various registers of the CIAs appear multiple times in the range from `$A00000` to `$BFFFFF`.  To the processor they look like ordinary memory locations, since all peripheral components in a 68000 system are memory mapped. The registers of a chip are accessed like memory locations.

The E clock on the 68000 is connected to the ⌀2 input of the 8250. The 16 internal registers are selected with the four address inputs A0-A3. Here is a explanation of the 16 registers (actually only 15 registers, since register 11 is unsused):

       CIA-A                                     CIA-B                                     Name    Function
       ---------------------------------------------------------------------------------------------------------------------
    0  $BFE001 : 1011 1111 1110 0000 0000 0001   $BFD000 : 1011 1111 1101 0000 0000 0000   PA      Port register A
    1  $BFE101 : 1011 1111 1110 0001 0000 0001   $BFD100 : 1011 1111 1101 0001 0000 0000   PB      Port register B
    2  $BFE201 : 1011 1111 1110 0010 0000 0001   $BFD200 : 1011 1111 1101 0010 0000 0000   DDRA    Data direction register A
    3  $BFE301 : 1011 1111 1110 0011 0000 0001   $BFD300 : 1011 1111 1101 0011 0000 0000   DDRB    Data direction register B
    4  $BFE401 : 1011 1111 1110 0100 0000 0001   $BFD400 : 1011 1111 1101 0100 0000 0000   TALO    Timer A low byte
    5  $BFE501 : 1011 1111 1110 0101 0000 0001   $BFD500 : 1011 1111 1101 0101 0000 0000   TAHI    Timer A high value
    6  $BFE601 : 1011 1111 1110 0110 0000 0001   $BFD600 : 1011 1111 1101 0110 0000 0000   TBLO    Timer B low byte
    7  $BFE701 : 1011 1111 1110 0111 0000 0001   $BFD700 : 1011 1111 1101 0111 0000 0000   TBHI    Timer B high byte
    8  $BFE801 : 1011 1111 1110 1000 0000 0001   $BFD800 : 1011 1111 1101 1000 0000 0000   E. LSB  Event counter bits 0-7
    9  $BFE901 : 1011 1111 1110 1001 0000 0001   $BFD900 : 1011 1111 1101 1001 0000 0000   E. MID  Event counter bits 8-15
    10 $BFEA01 : 1011 1111 1110 1010 0000 0001   $BFDA00 : 1011 1111 1101 1010 0000 0000   E. MSB  Event counter bits 16-23
    11 $BFEB01 : 1011 1111 1110 1011 0000 0001   $BFDB00 : 1011 1111 1101 1011 0000 0000   -       Unused
    12 $BFEC01 : 1011 1111 1110 1100 0000 0001   $BFDC00 : 1011 1111 1101 1100 0000 0000   SP      Serial port register
    13 $BFED01 : 1011 1111 1110 1101 0000 0001   $BFDD00 : 1011 1111 1101 1101 0000 0000   ICR     Interrupt control register
    14 $BFEE01 : 1011 1111 1110 1110 0000 0001   $BFDE00 : 1011 1111 1101 1110 0000 0000   CRA     Control register A
    15 $BFEF01 : 1011 1111 1110 1111 0000 0001   $BFDF00 : 1011 1111 1101 1111 0000 0000   CRB     Control register B

***

### The parallel ports

    Reg.  Name  D7    D6    D5    D4    D3    D2    D1    D0
    ---------------------------------------------------------
    0     PA    PA7   PA6   PA5   PA4   PA3   PA2   PA1   PA0
    1     PB    PB7   PB6   PB5   PB4   PB3   PB2   PB1   PB0
    2     DDRA  DPA7  DPA6  DPA5  DPA4  DPA3  DPA2  DPA1  DPA0
    3     DDRB  DPB7  DPB6  DPB5  DPB4  DPB3  DPB2  DPB1  DPB0

The 8250 has two 8-bit parallel ports, PA and PB, each of which is assigned a data register. The chip has 16 port lines, PA0-PA7 and PB0-PB7. Each port line can be used as either an input or an output. The input or output of a port line is called the data direction. The 8250 allows the data direction of each line to be controlled individually. Each port has data direction registers, DDRA and DDRB. 

If a bit in the data direction register is 0, the corresponding line is an input. The state of the port lines can be determined by reading the appropriate bits of the data direction register. If a bit in DDR is set to 1, then the corresponding port line becomes an output.

In general, writing to the data registers always stores the value in it, while reading always returns the state of the port lines. The bits in the data registers is placed in the port lines. Therefore when reading the port which is configured as an output, the contents of the data register is returned, while when writing to an input the value is stored in the data register, but doesn't appear on the port lines until the port is configured as output.

To simplify the data transfer through the parallel ports, the 8250 has two handshake lines, PC and FLAG.

The PC output goes low for one clock period on each access to the data register B (PB, reg 1). The FLAG input responds to such downward transitions. Every time the state of the FLAG line changes from 1 to 0, the FLAG bit is set in the interrupt controller register (ICR, reg. $D). These two lines allow a simple handshaking in which the FLAG and PC lines of two CIA's are cross-connected.

The sender need only write its data to the port register and then wait for a FLAG signal before sending each additional byte. Since FLAG can generate an interrupt, the sender can even perform other tasks while it is waiting. The same applies to the receiver, except that it reads the data from the port instead of writing it.

***

The simplest way to program this interface is directly through the hardware registers. This has the disadvantage that problems can occur with multitasking if another program wants to access this interface, thus it is better to access it through Amiga DOS. The data format is then predefined but you lose the ability to program individual bits as inputs and outputs, however.

***

### Digital I/O

Digital data can be both sent and received. It is also possible to program individual bits of the eight bit data lines as inputs and the rest as outputs. This is only possible with direct programming of the hardware register `$BFE301`.

Here we'll just look at using the entire port as input or output. There is also a device for this: the `parallel.device`. An extension must be made to the normal I/O structure in order to use this device. This extension has the following construction:

    Offset                 Name                  Contents
    --------------------------------------------------------------------------------
    48                     PWBufLen              Length of the output buffer
    52                     ParStatus             Status of the device
    53                     ParFlags              Parallel flags
    54-61                  PTermArray            Termination mask
    
    The status byte contains the following status bits:
    
    Bit                    Name                  Meaning, if set
    --------------------------------------------------------------------------------
    0                      PBUSY                 Printer busy
    1                      PAPEROUT              No more paper
    2                      PSEL                  Printer selected
    3                      RWDIR                 Data direction (0 = read, 1 = write)
    
    The following bits represent the parallel flags:
    
    Bit                    Name                  Meaning, if set
    --------------------------------------------------------------------------------
    1                      EOFMODE               EOF mode enabled
    2                      ACKMODE               Set this bit if you want to use ACK handshaking.
    3                      FASTMODE              High-speed mode. Will send out data as long as the BUSY signal is low.
    4                      SLOWMODE              Slow-speed mode for transfers to very slow printers.      
    5                      SHARED                Access possible for other tasks. Don't use with FASTMODE
    
If you want to read from the parallel port, the question arises as to how the receiver is to recognize the end of the transfer. It is possible to use a given byte sequence to stop the reception. This sequence is stored in the two long words of `TermArray`. This termination sequence is activated if bit 1 of the flag byte is set `(EOFMODE)` and the `SETPARAMS` command `(10)` is then called.

Please Note:

* Strobe functions as input data accepted from Amiga in input mode (similar to ACK* in output mode).
* Ack functions as input-data-ready from parallel device in input mode (similar to Strobe* in output mode).

http://www.theflatnet.de/pub/cbm/amiga/AmigaDevDocs/hard_e.html#e-2-1

***

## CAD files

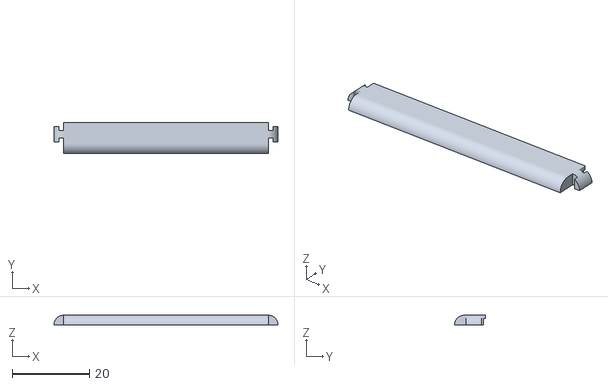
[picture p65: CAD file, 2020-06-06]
hardware/DSM/stl/sdbox_case_plate.stl
58.0 x 8.00 x 2.50

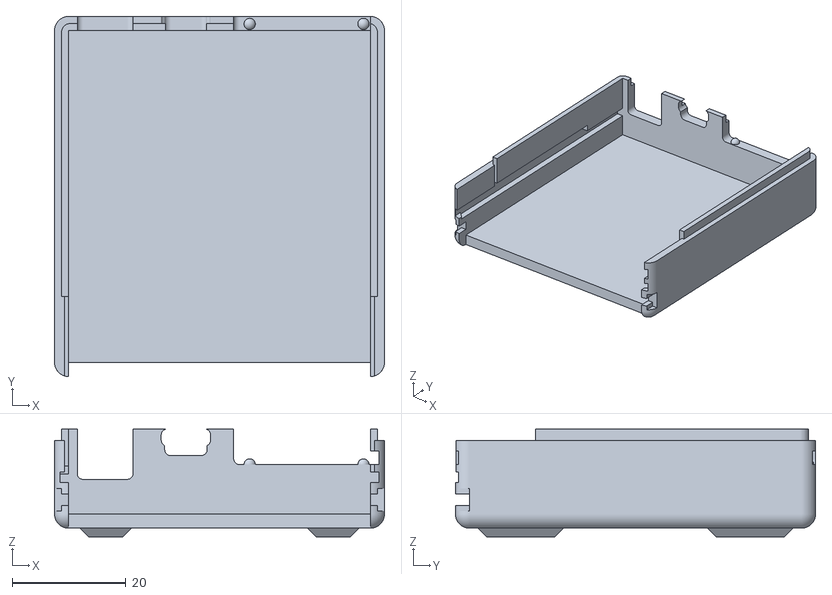
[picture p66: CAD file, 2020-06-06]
hardware/DSM/stl/sdbox_case_bottom.stl
58.0 x 63.3 x 18.9

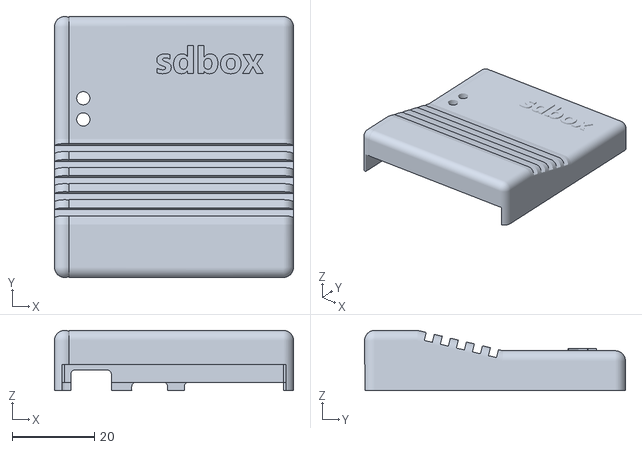
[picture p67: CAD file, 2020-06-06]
hardware/DSM/stl/sdbox_case_top.stl
58.0 x 63.3 x 14.6

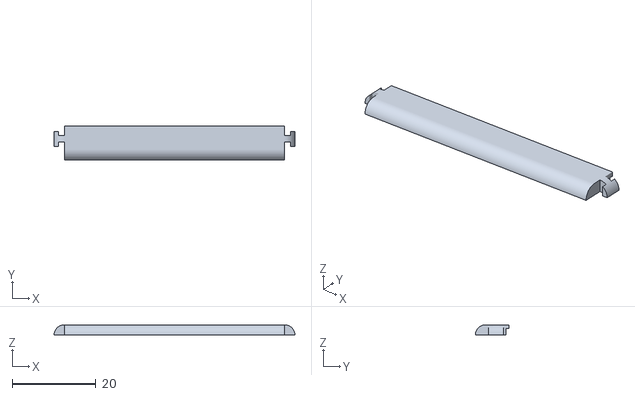
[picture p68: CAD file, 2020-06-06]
hardware/DSM/stl/sdbox_case_slightly_smaller_front_plate.stl
57.5 x 8.00 x 2.50

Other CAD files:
hardware/DSM/sdbox_text.skp

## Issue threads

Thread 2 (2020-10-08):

Unable to load

BleuLlama, 2020-10-08:
- I've created the hardware per the schematic (Arduino Nano, SD interface only)
- I have confirmed that (by jumpering CS on the sd card interface to D10 on that board temporarily) that the Nano can read the contents of the SD card, so I know that wiring is correct, the interface is functional, and the sd card is readable.

- I am powering the Nano from an external power source (not off of my Amiga's parallel port)
- In L: I have the handler file from aminet "fat95" (26868 bytes)
- in Devs: I have the files: "spinet.device" (5500 bytes), and "spisd.device" (4392 bytes)
- I have the SD0 file appended to my devs:mountlist

- I type:  Mount SD0:   (or Mount SD0 from devs:sd0
- no errors, so i type: dir sd0:
-- in 1.3, I get the error: Could not get information for SD0:   Error 115
-- in 2.05 I get the error: Could not get information for SD0: bad number
- If I attempt to change directory:  cd SD0:
-- in 1.3, i get the error: "Unable to load sd0:: Error 115"
-- in 2.05, i get the error: sd0:: bad number

The sd card is a 4 gig card formatted FAT using the "SD Card Formatter" application on my Mac.  I have tried other cards with no success either.

I'm sure it's something obvious i'm doing wrong... any suggestions?

jbilander, 2020-10-08:
Hi,

You can try and format with FAT and a smaller partition, try different cluster size when formatting. I've tried with a 2 GB partition on a 8 GB card and it worked for me, but you can try with even smaller, and if that doesn't work try FAT32. I formatted in Windows though after cleaning the sd-card with diskpart. There is a thread on the a1k.org forum on how to make the SD-Box more compatible by modifying the sd-card-adapter with pull-ups. It is a german forum but it is ok to write in English. Also you can verify that you have a working parallel-port by using Keirf's excellent Amiga Test Kit, boot from the ATK-adf https://github.com/keirf/Amiga-Stuff/releases .Write the adf to a floppy or If you have a gotek just put the adf on a usb stick and boot from it. It can check your CIA's timings and in one of the menus you have instructions howto make a dongle to test the parallel-port to verify it works correctly. Another thing to check that your Nano has a 16 MHz oscillator. It is needed since the timing is based on that. I've heard some Nano V3 clones sometimes has a 8 MHz oscillator and that will not work with the SD-Box. Hope this helps! /J

BleuLlama, 2020-10-08:
I tried that card with other formats, and none were successful. I just found a 1 gig card, and it showed the same results. (Fat32)
I've verified my parallel port with the Amiga Test Kit, with the parallel port loopback adapter for it.
Yes, my nano is 16mhz.
(Thank you for the suggestions, etc!)

I also just tried the 0.3 binaries here, to no avail. :(

I'll look into that thread you mentioned...

kendickson, 2020-12-06:
Hi BleuLlama. Have you been able to make any progress? I've got the same problem – mount succeeds (or, at least, doesn't give any error), but then trying to change directory I get "Unable to load sd0:: Error 115".

BleuLlama, 2020-12-06:
I was never successful with it, and ended up getting distracted by another
hobby.

On Sun, Dec 6, 2020 at 12:20 AM Ken Dickson <notifications@github.com>
wrote:

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

--
Scott Lawrence
yorgle@gmail.com

SukkoPera, 2021-01-25:
Very same problem here. I have tried an SD cart with just a single FAT16-formatted partition, no luck :(.

jbilander, 2021-01-25:
To troubleshoot I would try and rule out if this is your Amiga, your SD-Box or your microSD-card causing the problem. If you have a friend with a known working SD-Box then try your card in his/her SD-Box. This way you will know if your formatted card is compatible or not. Next step is try your SD-Box in a known working Amiga running SD-Box meaning unplug the good working SD-Box on that machine and try yours in that same machine. This way you will rule out if anything is wrong with your SD-Box. If it doesn't work then you will have to start troubleshoot your SD-Box, check voltage levels, check no dry soldering joints, check for continuity between pins, verify the Nano, verify the SD-Card adapter etc. If your SD-Box works in another Amiga but not in yours, chances are your configuration wasn't done correctly or your CIA-chips or parallel-port isn't working correctly. To verify that your Amiga's parallel-port is working you can make a dongle and use Amiga Test Kit to test it together with verifying the CIA-timings. Some things to verify before that:

- Latest _fat95_ file (from aminet) is in L:
- Latest _spisd.device_ file is in Devs:
- Correct _SD0_ file (and the _SD0.info_ file) is in Devs:
- _main.hex_ file is flashed successfully to your Nano.
- Your Nano V3 (clone) has a 16 MHz oscillator.
- If powering via usb, check your power adapter (phone charger) gives a stable 5V.
- Identify dry joints. Unlike good solder joints that are shiny, dry joints have a dull or matt finish. Also when soldering them they appear to have a more granular appearance as the solder is melted.

To mount card manually in wb 1.3 in a shell-prompt type this:

    cd Devs
    mount SD0: from SD0
    cd SD0:

After hitting enter in the last step the activity LED should start blinking. If successful it shows an icon on the workbench with the volume name of the microSD-card. In order to see folder and files as icons in wb they need to have corresponding *.info files of correct type with the same name as the file/folder to appear in a window.

I use a _Netac 8 GB microSD HC_ card formatted with a 1 GB FAT partition in Windows. I used diskpart in a windows cmd-prompt to clean it before creating the 1GB FAT partition in _diskmgmt.msc_ with default values.  I haven't had any problem at all with this card using it in my SD-Box with my Amigas.

https://i.imgur.com/KVXiJ9K.jpg

Hope it helps, /J

SukkoPera, 2021-01-25:
I have no friends with other SDBox's, but I can build another one. I will definitely investigate and do more tests, but what I can say at the moment is that the Nano, SD adapter, SD card and parallel port are all working good on their own, flashing was successful and the clock is 16 MHz.

I can add that I'm testing on an A500 rev.8A with a TF530 card and KS 3.1. I used the SD0 file from the *sdbox/amiga* directory, which seems to match the

Anyway, I think that since there's 3 of us here having the exact same problem, there must be something going on. Could you please verify that the *spisd.device* contained in *sdbox_drivers_v0.4.zip* is a "good" one? I tried to recompile it, but the binary I built on one machine crashes the amiga as soon as it's loaded, on another machine the cross-compiler won't build (I think because I have GCC 10). I saw that some guys around are still using v0.3, but I haven't tried it yet.

jbilander, 2021-01-25:
Hi SukkoPera, yes I verified v0.4 before I put it out on github, but I haven't done much testing. I think it should work with a TF530 installed. I have only tried with a TF534 but the E/VPA/VMA logic is the same between the two I think. The TF generates the E-CLK on posedge which I think is slightly wrong, it should be on the falling edge but it should work anyway. What you can try is put back in the plain 68000 CPU, that should definitely eliminate any E-CLK/VMA/VPA problems although you only get like ~83 KB/s transfer speed. I will send you an email with a prepared adf that I know works and you can troubleshoot further with...

SukkoPera, 2021-01-25:
OK, thanks to the ADF you sent me I made some progress: it turns out that if you use the `mount sd0: from devs:sd0` syntax, [this mountlist](https://github.com/jbilander/sdbox/blob/master/amiga/SD0) is not adequate, as it needs to start with `SD0:` and to end with a `#`. I have replaced it with the one that was on your floppy and at least now I can see the Activity led light up and blink a few times when I try to access the `SD0:` device, but then the dreaded *bad number* show up again.
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
SukkoPera, 2021-01-25:
I've tried 3 different SD cards:
- Kingmax 128 MB
- SanDisk 1 GB
- SanDisk 4 GB

But no luck :(. Even with the new board, I can't see any activity on the MISO/MOSI lines :(.

SukkoPera, 2021-01-26:
I think I've found a solution. I need to make some more tests when I get home, but I feel optimistic :).

SukkoPera, 2021-01-26:
So, here we go: thanks to [this topic on the Arduino forum](https://forum.arduino.cc/index.php?topic=604921.0), in particular to [lepoloni's post](https://forum.arduino.cc/index.php?topic=604921.msg4314215#msg4314215), I tried to put a 10k pull-up resistor on the MISO line before it reaches R4 and it did the trick on both of my boards! My 1 GB card is now recognized 100% of the time and seems to be working fine. The 4 GB one seems to have too big a filesystem while the 128 MB one gives read I/O errors, but I'll keep trying with this one.

Here are some pictures (sorry but I still need to clean the boards after all the building and tentative bodges):

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

After looking at the schematics of the module, I thought that R4, which is supposed to be there for protection, has no utility at all, since it doesn't look like the buffer is suddenly going to reverse its direction, so I thought I could remove the pull-up and bridge R4 altogether. This seems to work on the board with the larger SD module, while the smaller one still needs the pullup, which is very odd as the basic circuit seems to be the same.

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

Anyway, hope this helps, I'll keep doing more tests. Thanks @jbilander for your support!

PS: The board is my own modification of @jbilander's one. I made it mainly for my personal use (I like edge connectors) but it's available [here](https://github.com/SukkoPera/sdbox) if anybody is interested.

jbilander, 2021-01-26:
Very nice, glad you got it working. Yes I think pull-ups on the SD Card Adapter is what they did and talked about in the SD-Box thread on the german forum a1k.org too. I mentioned it in my first comment here but that thread seems to now be behind a registration wall unfortunately, so very good that you documented and shared your findings here. Many Thanks 👍 Maybe that 4 GB card of yours will work if you format it with a single smaller partition like 2 GB FAT or so.

SukkoPera, 2021-01-26:
After more testing, I decided to reinstall the pull-up resistor on the larger board too, it makes it more reliable to get any card to mount at the first attempt.

I got the 128 MB card working, seems like fat95 likes  partitions with type `0b` (W95 FAT32) better, I think I was using `06` (FAT16) before. I also got a 32 GB card working by making a single 2 GB partition on it (Maybe larger ones work too, I didn't try any other size). It takes a while to mount, but it works. I don't want to erase the 4 GB card so I guess I'll stop here with my tests.

I think all of this information should be added to the docs, as it will be easier for new users to find there.

kendickson, 2021-01-26:
Thanks for all of the investigation SukkoPera, and for the additional feedback, jbilander. I'll add a 10k resistor to my build (great photos – very helpful!) and see if it's the trick I was missing as well. Cheers.

Sm2dux, 2022-01-05:
Hi I have a A500 rev6,and a sdbox,the easiest way to mount wb1.3 (20) is to replace the startup-sequence with this,  cd Devs:
Mount sd0: from sd0
Cd sd0:
Loadwb
Endcli

Rezamjj, 2022-10-13:
Hi, I have the second version of this board and I have exactly the same problem (error 115). What should I do? Please help me.

jbilander, 2022-10-14:
> Hi, I have the second version of this board and I have exactly the same problem (error 115). What should I do? Please help me.

For the rev 2 board use the V2 driver and firmware available here, best if you compile/build them yourself and you will get the latest bugfixed driver.

https://github.com/jbilander/SDBox-v2
https://github.com/jbilander/amiga-par-to-spi-adapter

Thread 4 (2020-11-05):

Amiga hangs while booting when SD0 is placed in DH0:Devs/DOSDrivers and sdbox not connected

salocinx, 2020-11-05:
Hi

I meanwhile managed to run the `sdbox` on my Amiga 1200 with Blizzard IV 030 and 64MB Fast-RAM. Very cool !!

However, if I place the `SD0` mount list in `DH0:Devs/DOSDrivers` and the `sdbox` is **not** connected to the Amiga, the machine somewhen hangs during the boot sequence (black screen, no additional information).

Any idea why this happens and a possible work-around?

jbilander, 2020-11-05:
Hi, nice you got it working. Yes this is a known TODO. Check comment in code here:

https://github.com/jbilander/sdbox/blob/master/common/spi-par.c#L48

salocinx, 2020-11-05:
Great, thanks for the hint! I am currently setting up an Ubuntu 16.04 i386 machine. Maybe I can support you. Let's see.

salocinx, 2020-11-05:
Uhm... getting error while trying to build the m68k toolchain. The following are not available anymore:
```

http://server.owl.de/~frank/tags/vasm1_8d.tar.gz
http://server.owl.de/~frank/tags/vlink0_16a.tar.gz
http://server.owl.de/~frank/tags/vbcc0_9fP1.tar.gz
```

Some idea?

salocinx, 2020-11-05:
[Here's the solution for the missing files](https://github.com/adtools/amigaos-cross-toolchain/issues/102).

salocinx, 2020-11-05:
I made a crude test and it works. Booting without device attached. Will think about a more elegant way.
```
        uint16_t timeout = 65535;
        uint8_t ctrl = *cia_b_pra;
	while (ctrl & IDLE_MASK) {
		ctrl ^= CLOCK_MASK;
		*cia_b_pra = ctrl;
		ctrl = *cia_b_pra;
                timeout--;
                if(timeout==0) break;
	}
```

jbilander, 2020-11-06:
Hi, nice work. Please make a pull-request with your fix added when you are happy with your solution and I will merge it after having verified it works for me too.

salocinx, 2020-11-07:
I handed in a new pull-request with a more elegant way using the timer sources.

jbilander, 2020-11-08:
Thank you, I will take a look and see if it works for me too, and then merge and make a new 0.4 build. That is the plan.

salocinx, 2020-11-10:
Thanks!

Closed 2020-11-10.

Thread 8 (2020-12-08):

Question: Using kprintf with VBCC ?

salocinx, 2020-12-08:
Hi.

I am interested to dive deeper into the code and solve some issues (e.g. CRC). Is there any hope to use `kprintf` with `VBCC` like demonstrated in your [other project](https://github.com/jbilander/SimpleDevice)?

Thanks!

jbilander, 2020-12-08:
Hi, nice to hear :) Yes I think it will be possible, I haven't done it myself with VBCC though, but what you'll need to do is to link your build with the debug.lib where kprintf resides. In gcc you use -ldebug or -L/path/to/lib/directory. I don't know about VBCC specifics. To be able to test and watch output from a real Amiga machine you will need to hook up a null-modem cable to the serial port and then connect it to for example a linux machine on the other end. Then you can do something like "sudo cat /dev/ttyS0" on the linux machine and follow the output. I followed these instructions when making a cable DB9<->DB25. It works, https://www.amigaforever.com/kb/13-105

salocinx, 2020-12-08:
Thanks for your quick reply! The serial cable shouldn't be the problem, I either use a second Amiga with null-modem cable or otherwise I follow your link and build a cable to connect to my Linux machine - thanks.

I am stuck with the `Makefile`. I have set up a hello world program to test `kprintf()` with a skeleton from the `sdbox` repository.

The good news are, that debug.lib seems to be found, getting no errors regarding this (`EXTRA_LDFLAGS += -ldebug`).

My current `Makefile` looks like this:

```
FILENAME=test
DIR=build
OBJECTS=main.o timer.o

SRCDIRS=. ../common
INCDIRS=. ../common

EXTRA_CFLAGS += -DDEBUG -mcrt=clib2
EXTRA_LDFLAGS += -ldebug

include ../common/common.mk
```
I get the following output with errors when executing `make` (some conflicts, multiple definitions):

```
make -C sd
make[1]: Entering directory '/home/nicolas/Downloads/code/sd'
m68k-amigaos-gcc -m68000 -s -O2 -Wall -fomit-frame-pointer -noixemul -fbaserel  -I. -I../common -DDEBUG -mcrt=clib2 -Wl,-Map=build/test.map -ldebug -o build/test build/main.o build/timer.o
/opt/m68k-amigaos/m68k-amigaos/clib2/lib/nbcrt0.o(.text+0x1a):/opt/m68k-amigaos/m68k-amigaos/clib2/lib/nbcrt0.o: multiple definition of `geta4'
/opt/m68k-amigaos/m68k-amigaos/libnix/lib/libnix/nbcrt0.o(.text+0xca):/opt/m68k-amigaos/m68k-amigaos/libnix/lib/libnix/nbcrt0.o: first defined here
/opt/m68k-amigaos/m68k-amigaos/bin/ld: cannot find -lclib2
collect2: ld returned 1 exit status
../common/common.mk:23: recipe for target 'build/test' failed
make[1]: *** [build/test] Error 1
make[1]: Leaving directory '/home/nicolas/Downloads/code/sd'
Makefile:6: recipe for target 'sd' failed
make: *** [sd] Error 2
```
I then [read here](https://wiki.amigaos.net/wiki/The_Hacking_Way:_Part_1_-_First_Steps#The_C_standard_library_.28libc.29), that `clib2` is not available for `VBCC`, only for `GCC`, but `newlib` and `vclib` should be available for `VBCC` as well.

When changing `EXTRA_CFLAGS += -DDEBUG -mcrt=clib2` to `EXTRA_CFLAGS += -DDEBUG -mcrt=newlib`, I get the following error (same for `vclib`):

`/opt/m68k-amigaos/m68k-amigaos/bin/ld: cannot find -lnewlib`

So `newlib` and `vclib` are not included in my VBCC toolchain as I understand?

I would highly appreciate if you could point me to the right direction, as I ran out of ideas after researching for many hours yesterday and today. Hoping for ideas of any kind :-)

jbilander, 2020-12-08:
Hi that output looks like you are building with the `gcc-2.95.3-toolchain` since VBCC compiles with the VC command. If you want the kprintf to work with the `gcc-2.95.3-toolchain` then this should work...remove `-mcrt=clib2` from your makefile and use `-noixemul` flag, it then links with LibNIX http://cahirwpz.users.sourceforge.net/gcc-amigaos/Invocation.html  and add flags like this:

    EXTRA_CFLAGS=-ramiga-dev -DDEBUG
    EXTRA_LDFLAGS=-ldebug

    CFLAGS=-m68000 -s -O2 -Wall -fomit-frame-pointer -noixemul -fbaserel

You can remove the `-s` (strip) and the `-O2` (optimization) on a debug build as well, it is for release optimization.
Hope it helps!

salocinx, 2020-12-08:
Oh that's embarrassing. I don't know why I thought I was using `VBCC`, probably because I had installed that on another machine lately. But sure, I am using your `sdbox` [common.mk](https://github.com/jbilander/sdbox/blob/master/common/common.mk) which is linked in the `Makefile` above and it's `using m68k-amigaos-gcc`. I am sorry about that...!

Okay had problems with `-ramiga-dev` but now seems to work. I added the following line to [__UserDevOpen()](https://github.com/jbilander/sdbox/blob/master/sd/device.c#L121) function:

`KPrintF((CONST_STRPTR) "UserDevOpen()\n");`

Getting the following output containing errors:

```
nicolas@m68k:~/Downloads/sdbox$ make
make -C sd
make[1]: Entering directory '/home/nicolas/Downloads/sdbox/sd'
m68k-amigaos-gcc -m68000 -Wall -fomit-frame-pointer -noixemul -fbaserel  -I. -I../common -ramiga-dev -c -o build-device/device.o device.c
device.c: In function `__UserDevOpen':
**device.c:123: warning: implicit declaration of function `KPrintF'**
device.c:127: parse error before `struct'
device.c:130: `iostd' undeclared (first use in this function)
device.c:130: (Each undeclared identifier is reported only once
device.c:130: for each function it appears in.)
device.c:136: `err' undeclared (first use in this function)
device.c:142: warning: control reaches end of non-void function
../common/common.mk:29: recipe for target 'build-device/device.o' failed
make[1]: *** [build-device/device.o] Error 1
make[1]: Leaving directory '/home/nicolas/Downloads/sdbox/sd'
Makefile:6: recipe for target 'sd' failed
make: *** [sd] Error 2
```

Do I miss any `#include` statement ?

Basically I am just trying to use `KPrintF` in your sdbox project. I am able to compile the entire project just fine... Maybe it would be easier if you could try to integrate a `KPrintF` call in the sdbox project instead of helping me with my stupid questions here? I am really eager to experiment with the sdbox box code, but I first need `KPrintF` to work...

jbilander, 2020-12-08:
Yes, you need something like this for the KPrintF:

    #if DEBUG
    #include <clib/debug_protos.h>
    #endif

No worries. It can be a little confusing since VBCC (and Vasm) is indeed included in the toolchain, a slightly older version I think, but it is not used in this project, only GCC and its assembler AS is. You can check for VBCC under `m68k-amigaos\bin` `m68k-amigaos\m68k-amigaos\bin` `m68k-amigaos\m68k-amigaos\vbcc` and alter your Makefile CC to point to either VC or vbccm68k should you want to use VBCC I think.

The `-ramiga-dev` flag for gcc-2.95.3-toolchain adds device driver functionality to simplify device driver development, You have a simple skel here that explains it:

https://github.com/adtools/amigaos-cross-toolchain/blob/master/examples/simple-device.c

Hope it helps!

salocinx, 2020-12-08:
Thanks for your ongoing support! Yes, I already had `#include <clib/debug_protos.h>` added to the beginning of the `device.c` file. The compiler also recognizes the header, since if I am renaming it, the compiler complains.

Basically I am fine with `GCC` and I don't want to switch the compiler to `VBCC`. I just want `KPrintF()` to work!

I now searched the toolchain folder at `/opt/m68k-amigaos/...` for KPrintF and it gave me some results:

- /opt/m68k-amigaos/m68k-amigaos/ndk/doc/debug_lib.doc: Some short description of the available functions
- /opt/m68k-amigaos/m68k-amigaos/ndk/include/clib/debug_protos.h: The header file with the defintions

```
VOID KPrintF( CONST_STRPTR formatString, ... );
VOID kprintf( CONST_STRPTR formatString, ... );
```

But when compiling, I still get this error:

```
nicolas@m68k:~/Downloads/sdbox$ make
make -C sd
make[1]: Entering directory '/home/nicolas/Downloads/sdbox/sd'
m68k-amigaos-gcc -m68000 -Wall -fomit-frame-pointer -noixemul -fbaserel  -I. -I../common -ramiga-dev -c -o build-device/device.o device.c
device.c: In function `__UserDevOpen':
device.c:132: parse error before `struct'
device.c:135: `iostd' undeclared (first use in this function)
device.c:135: (Each undeclared identifier is reported only once
device.c:135: for each function it appears in.)
device.c:141: `err' undeclared (first use in this function)
device.c:147: warning: control reaches end of non-void function
../common/common.mk:29: recipe for target 'build-device/device.o' failed
make[1]: *** [build-device/device.o] Error 1
make[1]: Leaving directory '/home/nicolas/Downloads/sdbox/sd'
Makefile:6: recipe for target 'sd' failed
make: *** [sd] Error 2
```

It somehow doesn't recognize `kprintf("TEST")` although `#include <clib/debug_protos.h>` is in place:

```
#include <clib/debug_protos.h>

int __UserDevOpen(struct IORequest *ioreq, uint32_t unit, uint32_t flags)
{
	kprintf("TEST");

	struct IOStdReq *iostd = (struct IOStdReq*)ioreq;
	int err = IOERR_OPENFAIL;

	if (iostd && unit == 0) {
		if (sd_open() == 0) {
			/* Device is open */
			iostd->io_Unit = &ctx->unit;
			ctx->unit.unit_flags = UNITF_ACTIVE;
			ctx->unit.unit_OpenCnt = 1;
			err = 0;
		}
	}

	iostd->io_Error = err;
	return err;
}
```
I already tried to move the `#include` up and down. Also [a guy here says](https://morph.zone/modules/newbb_plus/viewtopic.php?topic_id=8092&forum=12) that -ldebug should be the last flag set to the linker (which is the case when using `EXTRA_LDFLAGS=-ldebug` I guess).

Any idea why it's not linked correctly / not recognized ?

jbilander, 2020-12-08:
Hi, I did a fix so it should now be possible to build a debug-build and use `kprintf`'s

To build with debug, cd into the sd directory and type the following:

`make -f Makefile.debug`

It creates a directory with name `build-device-debug` with a debug driver in it. Hope this helps.

You can check exactly what I did here:
https://github.com/jbilander/sdbox/commit/fc042aba37bc3ca6a2484e1a31ef84eadc527224

salocinx, 2020-12-09:
Hi, you are a real STAR ! Thank you so much, now working excellent 👍🏼  !
So it looks like the ordering for CFLAG and LDFLAG is quite important.
Great, now I am ready for doing some extensive experiments.
I will report back as soon as I accomplished anything useful.

[Here](https://ibb.co/LtGPn7N) and [here](https://ibb.co/n1PjCr0) some pictures of my Amiga development setup ;-)

Closed 2020-12-09.

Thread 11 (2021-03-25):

KS 1.3 adf image with SDBox

mlorenzati, 2021-03-25:
I'm trying to create a modified KS 1.3 adf with SDBox drivers and it's kicking me when I double click the sd0 gear "task held finish all disk activity"

1. Added in l the fat95 file
2. Added in devs the spisd.device file
3. Added the SD0 and SD0.info into the root of the disk to make it clickable

mlorenzati, 2021-03-26:
I was able to make it work with with automount also, I can share de adf

sbilgeri, 2021-05-29:
I got the same error under 1.3 (software error - task held) when I double click the sd0 in the root. What is the solution? did you create the automount in the startup-sequence? ADF would be helpful :-)

jbilander, 2021-05-31:
In WB 1.3 try making an IconX-script that you can double-click to mount the SD-card. The icon-file needs to be of the type "Project" and have IconX specified as Default Tool. Try with the attached files.

[Mount_SDCARD.zip](https://github.com/jbilander/sdbox/files/6569166/Mount_SDCARD.zip)
<br />
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

sbilgeri, 2021-05-31:
Thank you! It worked this way without an error, but had to put a "C:" in front of IconX under WB 1.3 (IconX was not found otherwise - Error 205).

morch-uk, 2021-06-29:
i made it work with workbench 3.1 on ks 3.1
tried making a bootable 1.3 with it, i also:
fat95 file into L
spisd.device file to devs
added SD0 and SD0.info to devs like on my 3.1

when i boot 1.3 on ks 1.3 - if i try "mount sd0: from SD0" i get device sd0: not recognised and if i double click on the SD0 icon i get:
c:mount program failed (error #80000004) wait for disk activity to finish

jbilander, 2021-06-29:
Hi, did you pick the correct SD0-file for your version of WB 1.3 ? Also you need to do _cd devs:_ first or give the full path like this _mount SD0: from devs/SD0_ and then _cd SD0:_ for the disk-icon to appear. Or use the IconX-script (zip-file) that I posted above for double-clicking under 1.3 (with the small change sbilgeri did above adding a C: in front of IconX, see picture above _Default Tool: IconX_ should be _Default Tool: C:IconX_ , hit enter and save)

morch-uk, 2021-06-29:
> Hi, did you pick the correct SD0-file for your version of WB 1.3 ? Also you need to do _cd devs:_ first or give the full path like this _mount SD0: from devs/SD0_ and then _cd SD0:_ for the disk-icon to appear. Or use the IconX-script (zip-file) that I posted above for double-clicking under 1.3 (with the small change sbilgeri did above adding a C: in front of IconX, see picture above _Default Tool: IconX_ should be _Default Tool: C:IconX_ , hit enter and save)

I used the correct sd0 in the 1.3 + folder and now it works :)

Sm2dux, 2021-12-30:
hi all,im often get the message when im copying files to the card,(in german) error and not a dosdisk)
any tip,tnx

emartisoft, 2022-05-07:
> hi all,im often get the message read error,not a dosdisk, when im copying files to the sdbox card,(in german) any tip,tnx

You must format sd card that sized <4GB and allocation unit size are 4096 bytes for FAT32.

salocinx, 2022-05-07:
I think you need to format the card with FAT, not FAT32 (partition must be less than 4GB, use Windows Disk Management tool for example to define the partition). However, I am currently testing the SDBox V2 on many different Amiga environments (around 10 different Amigas with different Kickstarts) and it's unfortunately working only on 50% of the machines. I will post a list of my test results soon.

Retro-updates, 2022-05-13:
> > hi all,im often get the message read error,not a dosdisk, when im copying files to the sdbox card,(in german) any tip,tnx
>
> You must format sd card that sized <4GB and allocation unit size are 4096 bytes for FAT32.

where you able to get it working? SDBox V1 or v2?

Sm2dux, 2022-05-15:
I have sdbox V1,formatted 2gb to fat,
seems to work now,no error messages,type note a dosdisk yet

Sm2dux, 2022-05-15:
i made a startup-sequence fil on df0:(s:startup-sequence)
setpatch
setclock load
resident c:execute pure
mount newcon:
binddrivers
cd devs:
mount SD0: from sd0
cd SD0:
assign >NIL: SD0: exists
if not warn
assign sys: SD0:
assign c: sys:c
assign l:  sys:l
assign fonts: sys:fonts
assign S: sys:s
assign Devs: sys:devs
assign Libs: sys:libs
makedir ram:tr
assign t: ram:tr
path RAM: C: sys:utilities sys: system s: SYS:prefs add
cd SD0:
loadwb
endcli

Sm2dux, 2022-05-15:
i dont now if i missed someting,but it works fine for me

salocinx, 2022-05-16:
I don't have any problems with KS1.3 based Amiga systems so far; but with KS3.1 I often run into r/w errors.

Retro-updates, 2022-05-20:
> I don't have any problems with KS1.3 based Amiga systems so far; but with KS3.1 I often run into r/w errors. With KS3.2 the card is not recognized at all.

would you be able to share the ADF for the KS1.3 which works for the SDBOX v2 ? I would like to verify it that is working as indeed on both 3.1 and 3.2 its giving problems.

jbilander, 2022-05-21:
@Retro-updates

drop me an email:  jorgen.bilander at gmail com
and I will try and help.

Sm2dux, 2022-10-11:
I have v1 2gb,formatted with fat,att THE moment seems to work fine,with test it futher,copyed wb1.3,No problem

Hämta Outlook for Android<https://aka.ms/AAb9ysg>
________________________________
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

Sm2dux, 2023-04-22:
Hi all,need a sparepart to my nanovna-H,2,8t, the contact for changing menu has been broken,tnx for tips

santiac89, 2023-10-25:
> i made a startup-sequence fil on df0:(s:startup-sequence) setpatch setclock load resident Cli L:shell-seg system add resident c:execute pure mount newcon: binddrivers cd devs: mount SD0: from sd0 cd SD0: assign >NIL: SD0: exists if not warn assign sys: SD0: assign c: sys:c assign l: sys:l assign fonts: sys:fonts assign S: sys:s assign Devs: sys:devs assign Libs: sys:libs makedir ram:tr assign t: ram:tr path RAM: C: sys:utilities sys: system s: SYS:prefs add cd SD0: loadwb endcli

I managed to do this correctly but I have a further question, maybe you can help me. I'm trying to do exactly the same but using a subfolder in the SD card for the whole thing. so `assign sys: SD0:v13` (I'm trying to dual install WB1.3 and WB3.2)

It startups correctly, but after getting into WB1.3 the SD card icon on Desktop is gone and contents of it are empty. So I cannot access any of the apps. Should I also reassign whatever that icon points to to `assign <SDCARDNAME>: SD0:v13` ?

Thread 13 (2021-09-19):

Plz help

AMD1980, 2021-09-19:
I have a paralell to micro sd card box I can’t get it to work on my Amiga at all I do have a a590 attached so I have 2.5 of ram on my Amiga 500 I there anyone who can help me get this thing working I only have workbench 1.3 so a step by step guide would be very helpful to me if anyone can help

jbilander, 2021-09-19:
Hi, is this an SDBox that you have built yourself or something you bought from someone?. The seller should give you support in that case. I'll help if this is an SDBox that you built yourself. How far have you come?. Have you followed all the instructions for installing it? Can you show a picture of the device?.

Troubleshooting, start by reading here:
https://github.com/jbilander/sdbox/issues/2#issuecomment-766751175

AMD1980, 2021-09-19:
It’s a box that I got from Amigastore.eu I have drivers on disk all installs ok but when I try to mount the drive it crashes my system

AMD1980, 2021-09-19:
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
This the box I have.
It came with a 32g micro sd pre-formatted with a 4g partition I have tried different partition sizes but no detection by my system at all I don’t have any kind of software to move files on my Amiga 500

jbilander, 2021-09-19:
I would first try and test that your CIA-chips are working correctly. This you can do with the great Amiga Test Kit and verify CIA-timings. https://github.com/keirf/Amiga-Stuff/releases  Do you have another Amiga you can try the sdbox in to rule out anything wrong with your machine. I mean if another machine crashes the same way then something is definitely wrong with the sdbox and you should return it to the seller.

AMD1980, 2021-09-20:
This is my system setup at the moment
***@***.***

***@***.***

Unfortunately I don’t have the means to create a Amiga test kit disk
This is the the software error I get every time I try to double click on it
***@***.***

kaml123, 2021-09-20:
Hi,
I have a similar problem on a self-made sdbox.
My setup A1200 with 68040 accelerator (Apollo 1240/40).
I was able to connect logic analyzer on SPI pins:
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
.
It looks like the SCK signal is triggered too early. It is possible that Amiga sends extra pulses to the POUT pin.
I checked parallel port and CIA timings with AmigaKit and everything is ok.

jbilander, 2021-09-22:
@AMD1980 I cannot see any of your information posted but double-click you say. Try with typing the command in a shell. Double-clicking doesn't work under 1.3 unless you make a script. I don't know what version of KS/WB you are using.

@kaml Are you using the 0.4 sdbox firmware?. The latest by Niklas (https://github.com/niklasekstrom/amiga-par-to-spi-adapter) doesn't work with the Revision 1 of the SDBox. A V2 of the SDBox is in the works that will use the latest firmware...

kaml123, 2021-09-22:
@jbilander I use below files:
- schematic from: https://github.com/jbilander/sdbox/blob/master/hardware/KiCad/sdbox_schematic_rev1a.pdf
- FW and driver from https://github.com/jbilander/sdbox/releases/tag/v0.4
I was able to dump all data lines:
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

I don't know why POUT/CLK is so many times triggered. Each POUT/CLK triggers additional SPI transaction.

rchyla, 2022-07-03:
> Are you using the 0.4 sdbox firmware?. The latest by Niklas (https://github.com/niklasekstrom/amiga-par-to-spi-adapter) doesn't work with the Revision 1 of the SDBox. A V2 of the SDBox is in the works that will use the latest firmware...

Could you edit the page so it would me more clear of what to use where? I just happen to fight with REV 1 sdbox, because i used 0.4 FW and found out i used the wrong FW in this thread. Even in "release" there is no mention of this, nor in v0.4 readme file.

Cleaning up repo so all revisions are placed on different folders for. e.g. would help circumvent confusions and problems that doesn't exists. There are photos on main page of REV1, so i thought all files in this repo works on rev. , furthermore in Rev. 2 repo there is no FW, so i thought that one firmware works on all revisions.

Had a lot of problems because of this, resistor soldering, formatting cards with different filesystems, scratching head why have i block errors after copying few files or after removing files on windows.

Now i'm on V0.3 and it seems like all problems went away.

v.04 should be moved to SD-BOX V2 repo.

jbilander, 2022-07-03:
It's very simple.

With a PCB that says Rev 1 on it you'll have to use the v0.4 drivers and firmware (or older).
With a PCB that says Rev 2 on it you'll have to use the v2.0 drivers and firmware.

In other words, the new driver and firmware is not backwards compatible with Rev 1.

rchyla, 2022-07-03:
Sorry i understood it wrong (that 0.4 is not working with REV.1).

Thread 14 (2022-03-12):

Atmega328PB

SukkoPera, 2022-03-12:
I had a broken Nano and i repaired it by replacing the MCU with an ATmega328PB I had laying around. Said MCU is not 100% compatible with the 328P, but I managed to build an hex that seems to work fine.

I'm attaching the modified Makefile and the resulting hex file just for reference. No guarantees ;)
[Makefile.328pb.txt](https://github.com/jbilander/sdbox/files/8237473/Makefile.328pb.txt)
[main.hex.txt](https://github.com/jbilander/sdbox/files/8237474/main.hex.txt)
(Remove `.txt` etension)

RetepV, 2024-07-21:
Thanks SukkoPera, I was able to program my SDBOX MINI with your makefile changes. The resulting binary seems to be running well.

There are some big changes to the oscillator, the PB does not have a full-swing oscillator anymore. But I used the values for the ATMEGA328P to program the fuses, and it all seems to still work. I recommend to add the fuse values to the avrdude call:

`PORT = /dev/ttyUSB0
BAUD = 115200
MCU = atmega328pb
PROGRAMMER = arduino

all: build flash

main.elf: main.c
	avr-gcc -Os -DSPSR=SPSR0 -DSPCR=SPCR0 -DSPDR=SPDR0 -mmcu=$(MCU) main.c -o main.elf

main.hex: main.elf
	avr-objcopy -O ihex main.elf main.hex

build: main.hex

flash: main.hex
	avrdude -p$(MCU) -c$(PROGRAMMER) -P$(PORT) -b$(BAUD) -D -Uflash:w:main.hex:i -Ulfuse:w:0xe6:m -Uhfuse:w:0xdf:m -Uefuse:w:0xfc:m

clean:
	rm main.elf
	rm main.hex
`

This programs the fuses for full-swing oscillator, even though the PB does not support it. But apparently, with 16MHz the oscillator still works. Going 20MHz or higher, it stops working.

https://omzlo.com/articles/using-an-external-crystal-on-the-atmega328pb

If in doubt, you could also replace the crystal with a canned oscillator, but it's not drop-in (the oscillator needs a 5V vcc and you will have to change the PCB or cut traces and solder wires).

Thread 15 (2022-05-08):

Most compatible SD card brand?

salocinx, 2022-05-08:
I am going to perform some extensive testing on many different Amiga systems with different SD card types. Which is the most compatible SD card brand so far, according to your experience?

jbilander, 2022-05-08:
Hi,

Thanks for the effort. I have tested with four different cards. Three of them works with a 2GB FAT-partition on both SDBox V1 and V2/Mini. The most compatible one is the one in the middle because it didn't need the 10k pull-up resistor fix on the MISO-line on V1. The other two needed the pull-up fix. The one that I didn't get working was a 4GB card called Intenso that I tried formatting with different smaller partitions but none worked, this card https://www.reichelt.com/de/en/microsdhc-card-4-gb-intenso-intenso-msdhc4g-p83730.html

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

salocinx, 2022-05-13:
Hi. Thanks for the info! Other are welcome to share their experience as well :-) I will do some testing and post the results here for further discussion as soon as I find some spare time.

jbilander, 2022-05-13:
No problem. For what it's worth...I think that Niklas bought the exact same type of Kingston 8GB card as I did and formatted it 2GB FAT and he didn't need to do the pull-up MISO resistor fix on V1, so I guess you can't always rule out a whole model. Perhaps cards are different inside too?, I don't know.

salocinx, 2022-05-13:
> No problem. For what it's worth...I think that Niklas bought the exact same type of Kingston 8GB card as I did and formatted it 2GB FAT and he didn't need to do the pull-up MISO resistor fix on V1, so I guess you can't always rule out a whole model. Perhaps cards are different inside too?, I don't know.

That's exactly one of the problems, these SD cards don't follow any precise specification. I lately read [this lecture paper](http://www.dejazzer.com/ee379/lecture_notes/lec12_sd_card.pdf) and he states:

> ... which working with is kind of painful as a lot of times SD cards do not behave as theoretically described on sdcard.org or
for example in SanDisk’s ambiguous documentation…

I will try to collect some flow-charts for different SD cards, maybe we can make the `SD.c` a little bit more compatible/robust. However, I have a SanDisk MicroSD card here, which works perfectly fine on my A600 & A1200, but having lots of troubles on my A3000 & A4000 for example. So I suspect that there is another, OS or Kickstart related issue; beside the different SD card types themselves.

Retro-updates, 2022-05-14:
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

Thanks!
I did have a version 1 SDBox but that sometimes gave read/write errors on the Amiga when using.
I'm testing the V2 SDBox now on several amiga's and differnt microsd cards, but without any good luck.

jbilander, 2022-05-17:
> ...lots of troubles on my A3000 & A4000 for example. So I suspect that there is another, OS or Kickstart related issue; beside the different SD card types themselves.

Hi, do you also have a SDBox-Mini to try with?. Does it give the same result? otherwise, I could send you one if you want to do some more extensive testing on all the different Amiga machines.

If there is a problem with the MISO-line on V2/Mini I have thought of a possible fix to use a 74AHCT1G125 (https://eu.mouser.com/datasheet/2/115/diod_s_a0011233421_1-2265603.pdf) instead of the 74LVC1G17 (https://eu.mouser.com/datasheet/2/115/DIOD_S_A0010762428_1-2543542.pdf) because I think HCT actually is better for level conversion 3V3->5V in this case since 2V is enough to indicate a high which will be bumped up to VCC (5V) by the buffer. I have a hunch that maybe 74LVC1G17 powered by VCC (5V) isn't optimal detecting a high level from "all" MicroSD-cards. Regardsless, this should solve the ICSP-programming problem of the SDBox-Mini if pin 1 /OE on the IC is held high (with for example a simple jumper to VCC) during programming the output pin (MISO) will be in high impedance state and should not interfere with the flashing of new firmware.

Unfortunately 74AHCT1G125 is also affected by the ongoing chip shortage right now...
https://eu.mouser.com/ProductDetail/Diodes-Incorporated/74AHCT1G125QSE-7?qs=bAKSY%2FctAC7FyuyWGFcozw%3D%3D

For the Arduino/ATMega328 I think VIH -- Minimum INPUT Voltage level to be considered a HIGH is 0.6*VCC equals around 3V on the ATMega328 when VCC is 5V.
https://learn.sparkfun.com/tutorials/logic-levels/all#arduino-logic-levels

Regards, J

salocinx, 2022-05-18:
@jbilander : No I don't have a SDBox Mini yet. If you don't mind I would be happy to get one. I live in Switzerland, not part of the EU, but I also have a friend's German address if that's easier. I would be happy to include it into my tests. How should we exchange our mailing addresses?

Thanks for the explanation. This sounds like an idea we really have to check out :-D ! Too bad 74AHCT1G125SE-7 is currently sold out. Either we try it with another package type, like [SOT25](https://www.digikey.ch/de/products/detail/diodes-incorporated/74AHCT1G125W5-7/2711990) instead of SOT353 for testing purposes, or we give [aliexpress](https://de.aliexpress.com/item/1005003710583255.html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) a chance. I can order both and send you some samples, no problem. I have to order some parts to finish my Re-Amiga 1200 project anyway.

I also recently noticed that something has changed with the Arduino Nano Clones. I built quite some Plipbox's throughout the past years and I never had real problems by powering them through VIN with a 9V/1A power supply unit. But these "new" Arduino Nano clones only work with USB power. After checking many things, including replacing the AMS1117 voltage regulator with a better solution; I finally desoldered the ATMEGA 328p chip from an "old" working Arduino Nano clone to the "new" Arduino Nano clone. Then the Plipbox began to work again as usual. So something with MCU has changed on these clones. I also noticed, that both VCC and GND, even AVCC are internally connected on the "old" ones, whereas they are not on the "new" ones. So I manually connected these pins together on the "new" one, but without success, still not working when powered by VIN. I also mention this story because it's the same with the SDBox and these "new" clones, it only works when powered by regulated 5V USB. Funny enough, that the old/better ATMEGA 328p chips were those which have been refurbished, i.e. sanded and newly painted; the new ones look untouched.

jbilander, 2022-05-19:
@salocinx

Cool, I'll send you one, just email me your shipping address to: jorgen.bilander at gmail com
It doesn't matter for me Germany or Switzerland but perhaps there are customs problems (import duty and fees) when sending to a swiss address? Do you also need a 5V-from-floppy-port-cable? One of these:

https://github.com/jbilander/SDBox-v2/blob/main/images/SDBox_get_5V_from_external_floppy_port_cable_pic14.jpg

Maybe it could be useful when testing too. Normally the Amigas 5V is somewhat lower around ~4.8V under load. Perhaps it's also of interest to test powering the SDBox this way since using a bad/noisy external power for SDBox I guess could affect things.

I will think a little more about the 74AHCT1G125SE-7. There is also a ...126 that is exactly the same but active high (OE) instead of active low (/OE) on pin 1. Ordering ICs from AliExpress is always a little bit of gamble if you are going to get real or fake chips.

Thanks for the info regarding the clones.

salocinx, 2022-05-19:
@jbilander : Great, I would be glad if you could send me one of the parallel port power cables to test with. I sent you an email. I will test with the current setup and when 74AHCT1G125SE-7 becomes available again, I can do further testing on the machines I encountered problems.

rchyla, 2022-07-03:
> Unfortunately 74AHCT1G125 is also affected by the ongoing chip shortage right now...

Maybe you should consider using different level shifter like FET based one with almost no propagation, for e.g. SN74CBT3245CPWR

jbilander, 2022-07-03:
Isn't it a bit overkill with bidirectional FETs when only unidirectional lines needed, don't you think?, but feel free to redesign if you want to.
I'll soon make a try with these:
Mouser has 74AHCT1G126GW125 in stock (1156 pcs at the time of writing):
https://eu.mouser.com/ProductDetail/Nexperia/74AHCT1G126GW125?qs=P62ublwmbi%252BsCpFPoi5fgw%3D%3D

I have a couple of these on order so I will soon be able to test if they'll work.
I have also updated the [SDBox Mini-PCB](https://github.com/jbilander/SDBox-Mini) (I called it Revision 2B) with a jumper setting and a pull-up resistor for pin 1 OE, which I hope will solve the problem with flashing new firmware to the AVR. By setting a jumper block on (grounding OE) while programming it should put the output pin in High-Z and not drive the line and cause any conflict with the SPI-communication from the ICSP-header, I hope, and then you just remove the jumper for normal operation again.

rchyla, 2022-07-03:
it's not overkill because FET level-shifters are bi-directional by design (i don't know if there are uni-directional versions at all), they're just easy to use have close to 0ns propagation and for few MHz you can even use simple and cheap transistor based variant (there is a module for Arduino with those even).

I'm often using LVT245 even for uni-directional shifting because they're usually same price as LVT244 and sometimes cheaper.

It's not like i'm pressing you to pick one, i'm just saying that sometimes it's better to look for something standard and widely used even if you're going to use 50% of it's capabilities, some good headaches could be circumvented and you're not swimming in tons of different IC's in your home.

jbilander, 2022-07-03:
Yeah, I mean overkill in the sense of expensive...with a $0.46 74AHCT1G126 we will get proper level shifting 3V3->5V of the MISO-line. HCT has 2V as minimum input voltage to be considered a HIGH and will shift the output to VCC. With CBT they will drive with 3V3 which can be rather tight when used with the Arduino. Minimum INPUT Voltage level to be considered a HIGH is 0.6*VCC equals around 3V on the ATMega328 when VCC is 5V.

Also the FET-bus will not solve the problem with flashing fw on the SDBox-Mini where the MISO-line is driven (by the pull-up resistor pin 7 on SD-card) and hence conflicts when the ICSP-header is used for flashing. With 74AHCT1G126 and its OE-pin we will have a way to set the output pin 4 in high-impedance during programming. At least that's the theory, we'll se how it works out...

rchyla, 2022-07-03:
I think it should solve it because it is basicly an open-drain with pullup (it doesn't have direction select pin, yet it is bi-directional), current buffer is interferring with programming because it drives full 5V or GND, so programmer can't break through such strong driving, you have to put it to high-impedance. FET drives only GND strong.

With 74AHCT1G126 yo just have to pulldown OE with resistor and connect it to pin 14 in parallel port, or alternatively use reset pin (if i remember correctly classic programmers are are holding this signal active during programming).

jbilander, 2022-07-04:
Flashing of the AVR on the SDBox-Mini is done like this:

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

and curently U4 cannot be in there when flashing, but with this new updated design:

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

and 74AHCT1G126 in U4 in place of 74LVC1G17. I should be able to easily ground the OE (pin 1) with a 2.0mm jumper-shunt on JP1 during flashing...and then remove it when done.

rchyla, 2022-07-04:
It is also a solution :)

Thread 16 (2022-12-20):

Replacement for PVG612S

PicoElements, 2022-12-20:
Hi,
i'm playing with rev1 of the board. Can you suggest me a replacement part for PVG612S ?
Thanks a lot,
PE

jbilander, 2022-12-20:
Hi,
PVG612S is optional and only used if you are going to power via the barrel-jack (9V). You can find them on AliExpress, just search on PVG612S and you will find many stores that have them. Another way is to make a cable to power the unit from the external floppy port using a cable with a usb connector (Mini-USB for SDBox-v1)
https://github.com/jbilander/SDBox-v2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
Regards, J

PicoElements, 2022-12-23:
Thank you! I will order some on Ali then. Not the best place but it's not a CPLD.. Great project by the way. :)

salocinx, 2022-12-23:
Never had problems with CPLDs from aliexpress, but the CPLDs from utsource were mostly crap.

PicoElements, 2022-12-23:
You're lucky mate, or i'm unlucky . Good to know better to avoid Utsource then, thanks! :)

salocinx, 2022-12-23:
You are right, it's probably just gambling by ordering these second hand CPLDs from these stores ☺️

Closed 2022-12-23.

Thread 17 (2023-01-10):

Quick reference to install on different OS - so I don't mess it up next time i need to use it

morch-uk, 2023-01-10:
considering I work in IT I always forget my amiga-fu so this is for mt

Make sure fat95 is in L:
OS 1.3.3 on floppy = put the spisd.device and the SD0 file (in the 1.3 v34.28+ folder) that is 461 bytes in Devs
Make/obtain script file called Mount_SDCARD with contents (iconX important???)
`cd devs:
mount SD0: from SD0
cd SD0:
quit`

on WB 3.1 just put the proper spisd.device, SD0 and SD0.info the Devs folder, and can double click SD0 to open.

i know it seems simple but i always struggle to remember that the devs folder is where i want it so it's a manual load

giobbino, 2023-07-06:
I got a strange behavior with my script (basically the same of yours) run by IconX. It returned an error (something like bad arguments iirc). But if I put a DIR command in the middle:
cd devs:
**dir**
mount SD0: from SD0
cd SD0:
then it works fine. I suppose the DIR command give a little delay and it makes the difference. But I'm just guessing, I don't know why it refuses to work without the dir command.   ...but hey, it works, so it's OK for me :-)

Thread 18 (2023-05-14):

Not an SDBox V2 Not playing nice with 3000D

DegeRandolf, 2023-05-14:
Hi,
I have an SDBox V2 installed on my Amiga 500 and 4000.  I installed the exact same software on my 3000.  The 3000 just has OS3.2 installed and working properly.  I also ran the CIA tests with Amiga Test Kit and all passed.  For the life of me I cannot get the 3000 to see the SDbox.  I have checked and double checked that the same files (and versions) are in the same locations as the 500 and 4000.  When I move the box from the 500 or 4000, the 3000 does not see it. (powering down and back up of course).

The only difference that I know of is the 3000 is using a zuluscsi SD on the scsi controller of the 3000.  It does have the new 3660 card installed in it but I have the MMU libraries installed as well.  I tried putting the mountlist in the SD0: icon with no success.  I'm at a loss as to what my next step would be.
Any help would be appreciated!

jbilander, 2023-05-14:
Hi,

This question should maybe have been better asked in the SDBox-v2 repository but anyway...yes the A3000 can be a difficult lady. Make sure you use the latest _spisd.device_ for V2, Build from source or you can download from here:
https://github.com/niklasekstrom/amiga-par-to-spi-adapter/releases
@salocinx fixed a bug that were causing problem in A3000 some time ago.

Also @salocinx reported he saw problems with the A3000 until he put 4.7k pull-up resistors (resistor packs) on the control and data lines (D0-D7,ACK,BUSY,POUT,SELECT). It can be worth trying if it still doesn't work for you.

Also for troubleshooting it can be good to know that the E-CLK behaves differently on machines with Fat Gary (A3000/A4000):
http://megaburken.net/~patrik/A3000/390540-02_Gary_specification.pdf

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

salocinx, 2023-05-14:
Yes, pull-up resistors should solve your issue on the A3000D. I am using 10K resistors connecting the parallel port lines to the 5V rail. Resistor arrays in DIP package come in handy for this purpose.

DegeRandolf, 2023-05-16:
Thanks all for the comments.  Looks like I have some soldering chores to do.  Salocinx, are you talking just about the SDbox or did you modify the parallel port on the MB?  I'm assuming the SDbox but I wanted to clarify.

salocinx, 2023-05-16:
@DegeRandolf :

- 1 piece [10K SIP with 4 resistors (5 pins)](https://www.mouser.ch/ProductDetail/Bourns/4605M-101-103LF?qs=tENXCkUKGaEmYbYpLG%2FWBw%3D%3D) for ACK, BUSY, POUT and SEL signals
- 1 piece [10K SIP with 8 resistors (9 pins)](https://www.mouser.ch/ProductDetail/Bourns/4609X-101-103LF?qs=1dK%2Fvx87kV0Ren26sFot6A%3D%3D) for D0-D7 signals

DegeRandolf, 2023-05-26:
Nicolas,

Thanks for guidance!.  I’ve ordered the 10K resistor arrays and I’ve marked the pins I’m going to solder to.  I’m thinking the easiest place to run the 5v wire to the arrays will be directly from the power port.  Excited to see if I can get it working.  In the meantime I had an old Highway USB card I stuck in and got up and running.  It provides me what I was looking for in the SDbox; a way to transfer large files easily to my 3000. Still, I am going to see if I can get this SDBox up and working on my 3000.  A question though.  Will this affect how it works on the 4000 and 500?  It’s not a show stopper, I have two, but it would be nice to interchangeably use either. Thanks again for your help.

Randy

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

salocinx, 2023-05-27:
Hi Randy

The pull-up resistors will not have any down-side to the other Amiga models. In fact, it's always good to have pull-up resistors on any parallel port device, they make the signals more stable. So go ahead and send me a picture when you are done.

Regards
Nicolas

patrikaxelsson, 2023-08-08:
@salocinx: noticed in the [A3000D schematics](https://www.amigawiki.org/dnl/schematics/A3000.pdf) that it has onboard 3.3k pullups on the control lines.

This differs between models btw - for example the A2000 has 10k instead, the A500 has 10k but is missing on BUSY and POUT, same on the A600 and A1200 but they additionally have a diodes to VCC on STROBE and ACK (what could that be for?).

patrikaxelsson, 2023-08-13:
@salocinx:

Regarding A3000D compatibility:
I have a stock 030@25MHz A3000D and it does not work with the V2 SDBox I have. It does not have pull-ups and I have not tried adding any yet to see if that fixed the issue. I usually run the SDBox with my A1200.

Regarding MicroSD compatibility:
I have not yet experienced a card giving me read/write errors. That doesn't really mean anything, I have not gone through a massive amount of cards and only two relative recent SanDisk cards - a 32GB Ultra and 64GB Extreme manufactured 2022. I can produce a list for you here of my collection of cards I have been using successfully:

MicroSD:
Transcend MLC 410M 2GB MicroSD
Transcend MLC 410M 4GB MicroSD HC I U1 A1 V10
Team 2GB MicroSD
Kingstron INDUSTRIAL MicroSD HC I 8GB U3 V30 A1 SDCIT2/8GB
SanDisk Extreme 64GB MicroSD XC I V30 U3 A2
Netac PRO A1 MicroSD HC I U1 V10 32GB
SanDisk Ultra 32GB MicroSD HC I U1 10 A1

SD (via microSD->SD adapter):
SanDisk Ultra 15MB/s 4 SD HC 4GB
hama SD HC 10 4GB
Transcend 10 SD HC I U1 32GB
SanDisk SD Card 256MB
SanDisk Ultra 15MB/s SD HC 4 8GB

salocinx, 2023-08-15:
Interesting, thanks for your compatibility list. The latest non-working (r/w errors) MicroSD card I encountered is:

SanDisk Extreme microSD A1, microSDHC, 32 GB, U3, UHS-I

Bought from a reputable reseller.

patrikaxelsson, 2023-08-15:
@salocinx: Could I perhaps buy such a card from you? One that is tested as non-working with the SDBox (r/w errors), while working without issues in a modern card reader.

salocinx, 2023-08-15:
@patrikaxelsson : I am happy to send you the MicroSD card for free : ) Please send me your mailing address to amiga.workshop@gmail.com

patrikaxelsson, 2023-08-15:
@salocinx: very generous! 🙏

jbilander, 2023-08-16:
@patrikaxelsson One card that didn't work for me was this 4GB Intenso:
https://www.reichelt.com/se/en/microsdhc-card-4-gb-intenso-intenso-msdhc4g-p83730.html
I don't have it any longer unfortunately, I gave it away together with a RGBtoHDMI otherwise I would send it to you. Anyway I thought I should mention it.

Also from before all these works for me:
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

salocinx, 2023-08-16:
> @salocinx: very generous! 🙏

You are welcome, will post it tomorrow. Glad to have talented people interested in this project : )

patrikaxelsson, 2023-08-26:
@salocinx:

Received the parcel yesterday. In addition to the 32GB SanDisk Ultra A1 card with issues on the SDBox, you had also included an additional noname 2GB card with similar issues plus an SDBox of your design with pullups on the parallel port lines, very appreciated 🙏.

Have done some initial testing:
1. I can confirm that I get read and write errors reported by fat95 when accessing both these cards.
2. These errors are 100% repeatable and happens on the same blocks, when you access the card in the same pattern, so I don't think it is a hardware signal problem between the AVR and the SD card, but rather some sort problem with state in the SD card or similar.
3. These read and write errors with the above cards are identical if I test with your SDBox which has pullup resistors, instead of my own V2 which has no pullup resistors.
4. I can confirm that your SDBox which has pullup resistors works on my A3000D (stock 030@25MHz), while my own V2 which has no pullup resistors does not work.

salocinx, 2023-08-29:
@patrikaxelsson : You are welcome, I am happy it arrived. Interesting finds so far, thanks for your efforts! Let me know if I can support you anytime by testing. I have quite a lot testing equipment and broad Amiga collection.

patrikaxelsson, 2023-08-29:
@salocinx:
I have found one issue which affects both your cards and created a PR for it: https://github.com/niklasekstrom/amiga-par-to-spi-adapter/pull/9

I cannot trigger any issues with the 32GB SanDisk Ultra A1 card after applying this fix.

The 2GB noname card unfortunately card also has some other issue which I haven't been able to pinpoint, it fails at large reads (multiple read block command) sometimes when for example extracting a large lha file that is on the card to the card itself.

@jbilander:
I have sourced a 4GB and 8GB class 4 Intenso card and they also suffer from this issue, but works great after the fix, cannot trigger any issues.

jbilander, 2023-08-30:
@patrikaxelsson
wow, great work, many thanks for doing this. As always the devil is in the details.

salocinx, 2023-08-31:
@patrikaxelsson : Great, you are a genius : D ! I will test asap and report back.

salocinx, 2023-09-08:
I meanwhile did some testing with the following two MicroSD cards:

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

The SanDisk Extreme did previously not work, the SanDisk Extreme Pro did work before. With the fix from @patrikaxelsson, now both cards work fine on all tested systems so far:

- A1000 / 512kB Chip-RAM / Kickstart 1.3
- A500 / 1MB Chip-RAM / Kickstart 1.3 + 3.1 + 3.2
- A1200 / 2MB Chip-RAM / 64MB Fast-RAM / Kickstart 3.1 / OS 3.1
- A3000D / 2MB Chip-RAM / 128MB Fast-RAM / Kickstart 3.2 / OS 3.2
- A4000D / 2MB Chip-RAM / 128MB Fast-RAM / Kickstart 3.1 / OS 3.9

I will do further testing with more MicroSD cards and more Amiga hardware configurations as soon as I get back from my 2-week Italy road-trip : )

Many thanks Patrik, I am really enjoying the new compatibility power of your recent bug-fix!

patrikaxelsson, 2023-09-08:
@salocinx: Thanks for testing the fix on so many setups!

jbilander, 2023-10-15:
@patrikaxelsson
Hi Patrik, if you want a Parallel_to_ESP32 device to tinker with https://github.com/jbilander/Parallel_to_ESP32 then drop me an email with your address to jorgen.bilander at gmail com, and I send one to you.
I think the hardware is working, and I started making applications running on the device, an ftp-server and so on. My thinking was to make a backup-device where files easily could be copied to and from the device, PC to ESP32 and ESP32 to Amiga and vice versa. I have very limited time for this however, at the moment it's on the backburner, but let me know if you want a device to play with. I have spare PCBs. Potentially it could be made to work as an ImpBox https://github.com/AmigaPorts/ImpBox32 or something like that but I haven't looked into that.

patrikaxelsson, 2023-11-28:
@DegeRandolf: As reported earlier in this thread, my original V2 SDBox without pullups did not work on my A3000, but the SDBox built by @salocinx with pullup resistors does.

However, after adding a 8x10k resistor network SIL (partno: 9A103G) as pullup to the D0-D7 pins of my original V2 SDBox, it now also works on the A3000.

The resistor network was really easy and convenient to fit, did it like this:

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

@jbilander: Would it perhaps make sense to include pullups on the datapins in the design to make it work out of the box also on the A3000?

jbilander, 2023-11-28:
@patrikaxelsson

Nice work.

Yes, if a new version is made sometime in the future it will be added, however I have currently no plans to make a new revision as I tinker with a lot of other stuff at the moment, for example a flicker-fixer PCB. On the Parallel_to_ESP32 that I made earlier I put optional pull-up resistor packs in the design as you can see here:
https://github.com/jbilander/Parallel_to_ESP32/blob/main/images/Parallel_to_ESP32_pic3.png
Similar could be done for SDBox-mini for example if there are enough room for it, not sure about that, on the other hand it is easy to fit a SIL-network just like you did, on v2 I guess it would be very easy to add a TH-footprint for a SIL on the main PCB as well.

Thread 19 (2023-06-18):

I need some help about the setup (disk, etc.)

giobbino, 2023-06-18:
Hi all,
I've a couple of Amiga 500 _(one donated, one I got from a litter box -literally!- and fixed)_ but I have no skill/knowledge about Amiga _(I'm most on 8-bit Commodore computers)_. One has the Kickstart 1.2 so I have to update it; the other has the KS 1.3 + WB 1.3.3 so this one should be compatible with SDbox.

I'm updating my post since I finally make the Lotharek drive working as DF0, but I can't make a working image with the needed files (it boots from the sdcard but then I can't copy it  on a floppy using the physical drive DF1, it says the image I've built is someway corrupted.

Long story short **: does anybody here has an image (.ADF or .HFE) of a bootable KS 1.3 with the needed files on it?**
I'm not planning to put the lotharek (or gotek) virtual drive inside the A500, since the FDD is working fine and I've tons of floppies here.

jbilander, 2023-06-19:
Hi, yes I have an ADF-image of WB 1.3 with everything configured correctly. I would love to share it but WB (and KS) is not free software unfortunately. Is your SDBox a version 1 or version 2? The device driver (_spisd.device_) is different between the two.

giobbino, 2023-06-19:
Hi,
thanks for your answer!
yes I understand; WB is freely available on the web though (and honestly it's abandoned software...). However I understand if you are not comfortable to share the disk.
I've built the V.1 because I have everything at home (SD card reader and Arduino Nano).
Since eventually I got my Lotharek FDD emulator working, I'm trying to make an image with the needed files, but it's giving me some error after the boot: I'm getting some "disk failure" and I don't know why. Maybe the .hfe images made by the HxCFloppyEmulator (dropping files inside) aren't ok?

giobbino, 2023-06-19:
Jorgen, thank you for your help. After I mounted sd0: and tried a DIR command, I get the "Could not get information for SD0: Error 115" as described in the https://github.com/jbilander/sdbox/issues/2 thread.
I'm trying with different SD cards / FAT-FAT32 / partition sizes etc.

I have no clue from the LEDs... since I have no LED (yet) on my SDbox. I'm waiting for the transistor from Aliexpress (I didn't find them neither at the local store, nor on-line for a reasonable price here in Brazil). Actually my board has just the Nano and the SD card with the pullup resistor as described by Sukkopera.

At least, thank to you, I can focus on the board! :-)
Ah, I think I will also try to replace the 8520, just in case the installed one is bad (luckily I have a couple spare, here)

Will let you know later!

giobbino, 2023-06-19:
Success! I think I'm opening a new thread (some kind of a tutorial) talking about my problems and doubts and how I solved.

Closed 2023-06-19.

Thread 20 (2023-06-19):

almost a tutorial (the problem I had and how I solved them)

giobbino, 2023-06-19:
OK, a little intro: I know nothing about Amiga. I have two, one donated and one broken, found in a cold night of many years ago in the trash bin , that I salvaged (ignoring my wife's complain ;-) and fixed. But again, I've never used one, actually (I know better the 8 bit Commodore computers). Just to explain why this tutorial will be probably seem a little dumb for the ones who know Amiga.
------------------------
HARDWARE:
I'm talking here about the V.1 version (I've built this one because I had all the needed parts, except the PCB I got from PCBway).

The minimum required for a working unit is:
- An Arduino Nano 16 MHz
- A compatible SD card reader
- A DB25 male connector
- A 10 k ohm resistor for a pullup patch, as explained by Sukkopera (see: https://github.com/jbilander/sdbox/issues/2#issuecomment-767763618)

According with the schematics, all the other parts are optional.  You can power the board by the Arduino USB port. I didn't put the LEDs yet because I'm waiting for the transistors.
---------------------------
SOFTWARE:
Here is where things are getting tricky. If you just own a stock Amiga with floppy, it will not be enough. You need a Gotek (or Lotharek) floppy disk emulator connected to your Amiga, because you need some extra files on your boot disk.
Since the WB is still protected by copyright [but of course you can find them on Google:](https://www.google.com/search?q=amiga+workbench+download) I will only attach here the needed files you need to add to the WB 1.3.3 image (I used the
_"Workbench v1_3_3 rev 34_34 (1990)(Commodore)(A500-A2000)(Disk 1 of 2)(Workbench)"_  image)

[files required for sdbox.zip](https://github.com/jbilander/sdbox/files/11790742/files.required.for.sdbox.zip)

As told, this is worked for MY configuration: Amiga 500 with Kickstart 1.3 and Workbench 1.3.3 (afaik the 1.3 version is the minimum required, previous KS/WB will not work).

You can open and edit the ADF images using the HxC Floppy Emulator Tool from this page (scroll the page until the "software" section: [https://hxc2001.com/download/floppy_drive_emulator/](https://hxc2001.com/download/floppy_drive_emulator/)

Now, get the "files required for sdbox.zip" file attached to this post and unzip it in some folder.
You will see a structure like this:
\
fat95.info*
  DEVS
    +--SD0
    +--SD0.info
    +--spid.device
  L
    +--fat95
    +--install95*

(I'm not sure if the files marked with "*" are needed, actually, but -hey!- this is the first image that worked after many failed attempts, so it's ok for me ;-)

Open the ADF workbench image, in example _Workbench v1_3_3 rev 34_34 (1990)(Commodore)(A500-A2000)(Disk 1 of 2)(Workbench)_ and click on the "Disk Browser" button. You will need to delete some files to make space on the disk.
From the UTILITIES folder I removed _calculator, calculator.info, clock, clock.info, installprinter, installprinter.info_

Now grab the whole structure (files and folders) from the "files required for sdbox.zip" file and drop into the HxCFloppyEmulator Floppy Browser. Check that the files were dropped into the right folders (NOTE: you can't drop a single file inside a folder; you must to drop the whole structure, files and folders. It will drop everything in the root of the floppy disk image, preserving the folder structure).

Then, click the Save/Export button and choose the right extension for your image.
Lotharek emulators, should be the HFE type (at least my old one: it doesn't accept ADF files).
Gotek emulators, should be the ADS type (I guess: I just bought one by it didn't arrive it yet).
--------------------------------------------
AMIGA 500 WB 1.3 (can't say about other model/WB):

About the SD card, how to format, etc.: see below, where I'm talking about the errors

Boot with the Lotharek/Gotek emulator and your modded image. Open the Workbench, open the shell, and type:
mount sd0: from devs/sd0
cd sd0:
dir sd0:

IF you get any error, there's a good thread about that: https://github.com/jbilander/sdbox/issues/2

However, the two big errors I got were:

1) "can't find sd0:" (iirc; something like this)
2) a windows with the message "lesefehler 20 bei block <nnnn>" (or "read error 20 at block <nnnn>")

in my case both messages were related with bad or bad partitioned/formatted SD card. I tried three different SD cards before to get the rid of this. **THIS THING IS REALLY PICKY WITH SDCARD** and not all of them are recognized! If you have some trouble, try another brand/partition/format.

I used AOMEI Partition Assistant 9.6.1 to create a small partition (less than 2 Gb) and to format it as FAT16 (should work with FAT32, I didn't test it yet).
-----------------------------
Please feel free to correct me or to add any comment below if I went wrong or I missed some important info.

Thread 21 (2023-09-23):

Nano Every

2of5aliasmaik, 2023-09-23:
I replaced the Nano with a Nano Every and get the error messages listed below when compiling Main.c. Is the Nano Every with its 4809 so different than the Nano with the 328. Yes, some pins have different names, but if they are adjusted it should work, right?
If I use a Uno for testing purposes, compiling and uploading works without any problems, the same chip is installed here and the pin assignment is identical.
I hope someone can explain this to me or, best of all, adapt the Main.c to the Every.
-------------------------------
D:\Daten\Dokumente\Arduino\Sketch_SDBox\Sketch_SDBox.ino: In function 'int main()':
D:\Daten\Dokumente\Arduino\Sketch_SDBox\Sketch_SDBox.ino:34:5: error: 'SPCR' was not declared in this scope
     SPCR = (1 << SPE) | (1 << MSTR) | (1 << SPR1) | (1 << SPR0);
     ^~~~
D:\Daten\Dokumente\Arduino\Sketch_SDBox\Sketch_SDBox.ino:34:5: note: suggested alternative: 'SCL'
     SPCR = (1 << SPE) | (1 << MSTR) | (1 << SPR1) | (1 << SPR0);
     ^~~~
     SCL
D:\Daten\Dokumente\Arduino\Sketch_SDBox\Sketch_SDBox.ino:34:18: error: 'SPE' was not declared in this scope
     SPCR = (1 << SPE) | (1 << MSTR) | (1 << SPR1) | (1 << SPR0);
                  ^~~
D:\Daten\Dokumente\Arduino\Sketch_SDBox\Sketch_SDBox.ino:34:18: note: suggested alternative: 'PE'
     SPCR = (1 << SPE) | (1 << MSTR) | (1 << SPR1) | (1 << SPR0);
                  ^~~
                  PE
D:\Daten\Dokumente\Arduino\Sketch_SDBox\Sketch_SDBox.ino:34:31: error: 'MSTR' was not declared in this scope
     SPCR = (1 << SPE) | (1 << MSTR) | (1 << SPR1) | (1 << SPR0);
                               ^~~~
D:\Daten\Dokumente\Arduino\Sketch_SDBox\Sketch_SDBox.ino:34:31: note: suggested alternative: 'PSTR'
     SPCR = (1 << SPE) | (1 << MSTR) | (1 << SPR1) | (1 << SPR0);
                               ^~~~
                               PSTR
D:\Daten\Dokumente\Arduino\Sketch_SDBox\Sketch_SDBox.ino:34:45: error: 'SPR1' was not declared in this scope
     SPCR = (1 << SPE) | (1 << MSTR) | (1 << SPR1) | (1 << SPR0);
                                             ^~~~
D:\Daten\Dokumente\Arduino\Sketch_SDBox\Sketch_SDBox.ino:34:45: note: suggested alternative: 'SPI0'
     SPCR = (1 << SPE) | (1 << MSTR) | (1 << SPR1) | (1 << SPR0);
                                             ^~~~
                                             SPI0
D:\Daten\Dokumente\Arduino\Sketch_SDBox\Sketch_SDBox.ino:34:59: error: 'SPR0' was not declared in this scope
     SPCR = (1 << SPE) | (1 << MSTR) | (1 << SPR1) | (1 << SPR0);
                                                           ^~~~
D:\Daten\Dokumente\Arduino\Sketch_SDBox\Sketch_SDBox.ino:34:59: note: suggested alternative: 'SPI0'
     SPCR = (1 << SPE) | (1 << MSTR) | (1 << SPR1) | (1 << SPR0);
                                                           ^~~~
                                                           SPI0
D:\Daten\Dokumente\Arduino\Sketch_SDBox\Sketch_SDBox.ino:35:5: error: 'SPSR' was not declared in this scope
     SPSR |= (1 << SPI2X);
     ^~~~
D:\Daten\Dokumente\Arduino\Sketch_SDBox\Sketch_SDBox.ino:35:5: note: suggested alternative: 'SS'
     SPSR |= (1 << SPI2X);
     ^~~~
     SS
D:\Daten\Dokumente\Arduino\Sketch_SDBox\Sketch_SDBox.ino:35:19: error: 'SPI2X' was not declared in this scope
     SPSR |= (1 << SPI2X);
                   ^~~~~
D:\Daten\Dokumente\Arduino\Sketch_SDBox\Sketch_SDBox.ino:35:19: note: suggested alternative: 'SPI_t'
     SPSR |= (1 << SPI2X);
                   ^~~~~
                   SPI_t
D:\Daten\Dokumente\Arduino\Sketch_SDBox\Sketch_SDBox.ino:50:9: error: 'PIND' was not declared in this scope
     if (PIND & (1 << CLOCK_BIT))
         ^~~~
D:\Daten\Dokumente\Arduino\Sketch_SDBox\Sketch_SDBox.ino:50:9: note: suggested alternative: 'PIN0'
     if (PIND & (1 << CLOCK_BIT))
         ^~~~
         PIN0
D:\Daten\Dokumente\Arduino\Sketch_SDBox\Sketch_SDBox.ino:61:11: error: 'PIND' was not declared in this scope
     if (!(PIND & 0x80))
           ^~~~
D:\Daten\Dokumente\Arduino\Sketch_SDBox\Sketch_SDBox.ino:61:11: note: suggested alternative: 'PIN0'
     if (!(PIND & 0x80))
           ^~~~
           PIN0
D:\Daten\Dokumente\Arduino\Sketch_SDBox\Sketch_SDBox.ino:69:9: error: 'PIND' was not declared in this scope
     v = PIND;
         ^~~~
D:\Daten\Dokumente\Arduino\Sketch_SDBox\Sketch_SDBox.ino:69:9: note: suggested alternative: 'PIN0'
     v = PIND;
         ^~~~
         PIN0
D:\Daten\Dokumente\Arduino\Sketch_SDBox\Sketch_SDBox.ino:70:9: error: 'PINC' was not declared in this scope
     w = PINC;
         ^~~~
D:\Daten\Dokumente\Arduino\Sketch_SDBox\Sketch_SDBox.ino:70:9: note: suggested alternative: 'PIN0'
     w = PINC;
         ^~~~
         PIN0
D:\Daten\Dokumente\Arduino\Sketch_SDBox\Sketch_SDBox.ino:109:5: error: 'SPDR' was not declared in this scope
     SPDR = 0xff;
     ^~~~
D:\Daten\Dokumente\Arduino\Sketch_SDBox\Sketch_SDBox.ino:109:5: note: suggested alternative: 'SDA'
     SPDR = 0xff;
     ^~~~
     SDA
D:\Daten\Dokumente\Arduino\Sketch_SDBox\Sketch_SDBox.ino:120:27: error: 'SPIF' was not declared in this scope
     while (!(SPSR & (1 << SPIF)))
                           ^~~~
D:\Daten\Dokumente\Arduino\Sketch_SDBox\Sketch_SDBox.ino:120:27: note: suggested alternative: 'SPI0'
     while (!(SPSR & (1 << SPIF)))
                           ^~~~
                           SPI0
D:\Daten\Dokumente\Arduino\Sketch_SDBox\Sketch_SDBox.ino:190:27: error: 'SPIF' was not declared in this scope
     while (!(SPSR & (1 << SPIF)))
                           ^~~~
D:\Daten\Dokumente\Arduino\Sketch_SDBox\Sketch_SDBox.ino:190:27: note: suggested alternative: 'SPI0'
     while (!(SPSR & (1 << SPIF)))
                           ^~~~
                           SPI0

exit status 1

Compilation error: 'SPCR' was not declared in this scope

jbilander, 2023-09-24:
Hi,

for the AVR we build with `avr-gcc` by running `build.bat`, try that.
You can see the commands used if you click the build.bat file in the repository:
https://github.com/jbilander/sdbox/tree/master/avr

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

SukkoPera, 2024-07-22:
SPI registers are [totally different](https://ww1.microchip.com/downloads/aemDocuments/documents/MCU08/ApplicationNotes/ApplicationNotes/TB3215-Getting-Started-with-SPI-DS90003215.pdf) on the ATmega4809, the code will never work as-is, it needs quite some adaptation.

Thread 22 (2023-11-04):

Firmware programming

casyms, 2023-11-04:
I have built the hardware, it is version 1A as per the shared file on PCBWay.

My problem is that I cannot program the Arduino Nano, I can’t find the file to program the Nano or the method to do it. I have worked with Arduino’s before.

Can I please get help with this?

Charles

jbilander, 2023-11-04:
Hi, it's in the AVR folder in zip file here.
https://github.com/jbilander/sdbox/releases

Run flash.bat, instructions here:
https://github.com/jbilander/sdbox/tree/master/avr#building-and-flashing

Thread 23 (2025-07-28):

Works with OS 1.3 and 2.04, but not with OS 3.1 (and other 3.x's)

RetepV, 2025-07-28:
Hi!

A while ago I built a few of your SDBox Mini V2 devices. And they work great!

However, they work great under Amiga OS 1.3 and 2.04 (and probably others), but not with the OS 3.1 that I'm using (and also not 3.2.3 that somebody else is using).

Let me be clear: this is not related to my SDBox or my SD card. Exactly the same SD card works great with OS 1.3 and 2.04, but just doesn't want to work with OS 3.1.

Details:

* My setup is an Amiga CDTV with a kickstart switcher where I can switch between KS 1.3, 2.04 and 3.1.
* I have a 4GB SD card with a 250MB partition formatted to FAT16, and it contains a WB 1.3 setup.
* I have several boot floppies, so I can choose to boot 1.3, 2.04 or 3.1. I boot from floppy.
* OS 1.3 works great
* OS 2.04 works great
* OS 3.1 does not work

When booted to 3.1 WB, I start a CLI and mount the disk with:

* cd devs
* mount sd0: from sd0
* dir sd0:

On OS 3.1 (Workbench 3.1), the mounting seems to go fine, it gives me no error. But a "dir sd0:" returns an error "bad number". There are no flashes on the activity led of the SDBox.

Could it be an issue with the mount list in the SD0 file? I'm using a correct one, where I added "SD0:" at the start and "#" at the end of the file. It works under IS 1.3 and 2.04.

I'm using FAT95 version 3.18, and spisd.device 2.0 (verified).

Any clue? I read that you are also using it under WB 3.x, so I assume that it should work, and there's probably some small detail that we're missing.

jbilander, 2025-07-28:
Hi,

With 3.1 and later I think you can just double click the SD0 file and it should mount the device. Put this in the SD0 file:
```
FileSystem     = l:fat95
Device         = spisd.device
Unit           = 0
Flags          = 0
LowCyl         = 0
HighCyl        = 0
Surfaces       = 1
BlocksPerTrack = 1
BlockSize      = 512
Reserved       = 0
Buffers        = 20
BufMemType     = 1
BootPri        = 0
StackSize      = 4096
Priority       = 5
GlobVec        = -1
DosType        = 0x46415401
```
You can download SD0 and SD0.info from here
[SD0.zip](https://github.com/user-attachments/files/21473058/SD0.zip)
and put in devs: and download latest `spisd.device` from here and put in devs:
https://github.com/niklasekstrom/amiga-par-to-spi-adapter/releases
then try and double click the SD0 icon and see if that works.

Closed 2025-07-28.

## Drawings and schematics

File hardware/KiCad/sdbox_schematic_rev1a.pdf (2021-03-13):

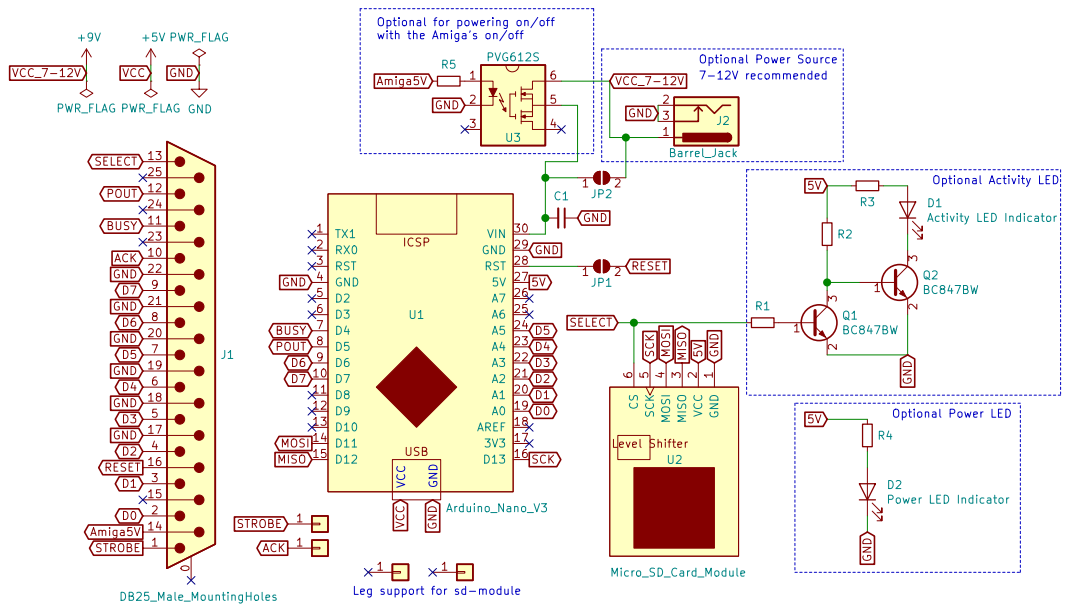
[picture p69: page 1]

Optional for powering on/off
with the Amigas on/off

Optional Power Source

5V GND

Leg support for sd-module

Id: 1/1 Title: File: sdbox.sch Sheet: /

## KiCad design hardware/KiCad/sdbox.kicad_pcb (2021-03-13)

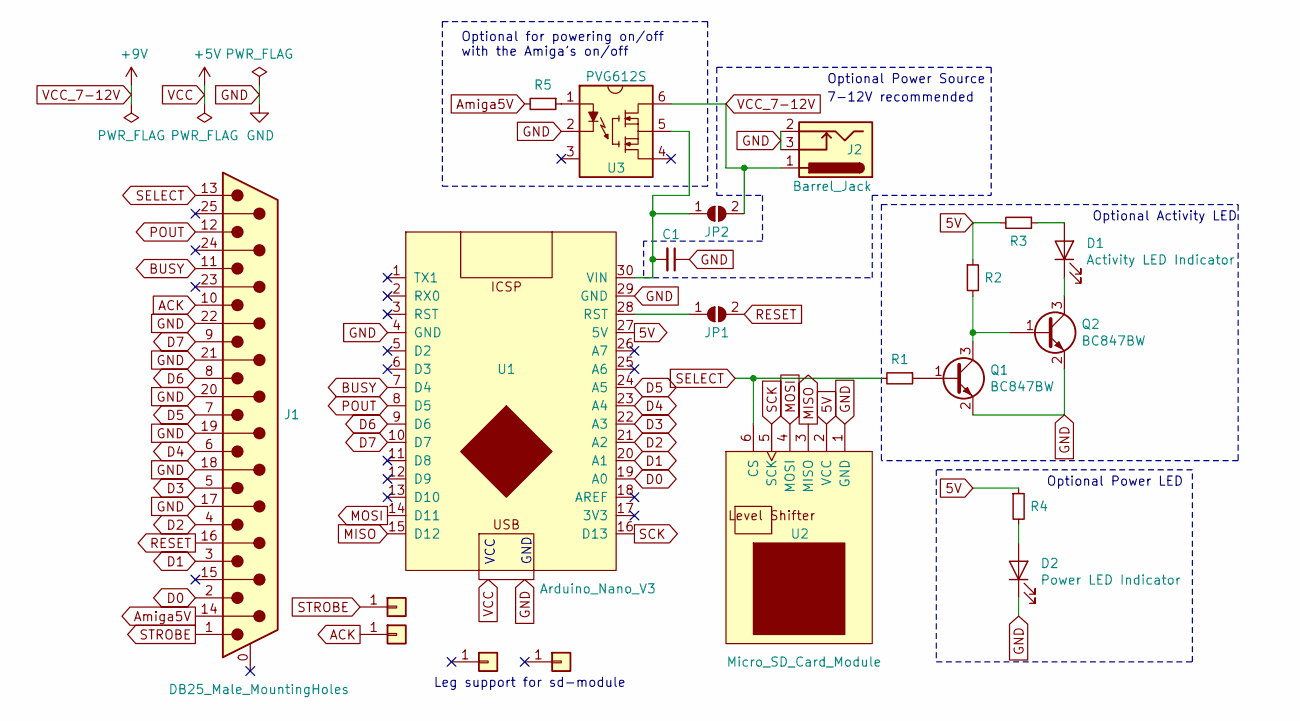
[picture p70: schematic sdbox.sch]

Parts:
C1: C_Small; C_1210_3225Metric_Pad1.42x2.65mm_HandSolder
D1: Activity LED Indicator; LED_D3.0mm
D2: Power LED Indicator; LED_D3.0mm
J1: DB25_Male_MountingHoles; DSUB-25_Male_Horizontal_P2.77x2.84mm_EdgePinOffset4.94mm_Ho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
J2: Barrel_Jack; BarrelJack_Horizontal
J3, J4: Conn_01x01; PinHeader_1x01_P2.54mm_Vertical
J5, J6: Conn_01x01; PinSocket_1x01_P2.54mm_Vertical
JP1, JP2: SolderJumper_Open; SolderJumper-2_P1.3mm_Open_Pad1.0x1.5mm
Q1, Q2: BC847BW; SOT-323_SC-70
R1, R2, R3, R4, R5: R_Small; R_1206_3216Metric_Pad1.42x1.75mm_HandSolder
U1: Arduino_Nano_V3; Arduino_Nano_V3_Schield
U2: Micro_SD_Card_Module; PinSocket_1x06_P2.54mm_Vertical
U3: PVG612S; SOIC254P978X443-6N

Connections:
5V: R2.1, R3.2, R4.1, U1.27 (5V), U2.2 (VCC)
ACK: J1.10, J4.1
Amiga5V: J1.14, R5.2
BUSY: J1.11, U1.7 (D4)
D0: J1.2, U1.19 (A0)
D1: J1.3, U1.20 (A1)
D2: J1.4, U1.21 (A2)
D3: J1.5, U1.22 (A3)
D4: J1.6, U1.23 (A4)
D5: J1.7, U1.24 (A5)
D6: J1.8, U1.9 (D6)
D7: J1.9, U1.10 (D7)
GND: C1.1, D2.1 (K), J1.17, J1.18, J1.19, J1.20, J1.21, J1.22, J2.2, J2.3, Q1.2 (E), Q2.2 (E), U1.4 (GND), U1.29 (GND), U2.1 (GND), U3.2
MISO: U1.15 (D12), U2.3 (MISO)
MOSI: U1.14 (D11), U2.4 (MOSI)
unnamed: C1.2, JP2.1 (A), U1.30 (VIN), U3.5
unnamed: D1.1 (K), Q2.3 (C)
unnamed: D1.2 (A), R3.1
unnamed: D2.2 (A), R4.2
unnamed: JP1.1 (A), U1.28 (RST)
unnamed: Q1.1 (B), R1.1
unnamed: Q1.3 (C), Q2.1 (B), R2.2
unnamed: R5.1, U3.1
POUT: J1.12, U1.8 (D5)
RESET: J1.16, JP1.2 (B)
SCK: U1.16 (D13), U2.5 (SCK)
SELECT: J1.13, R1.2, U2.6 (CS)
STROBE: J1.1, J3.1
VCC_7-12V: J2.1, JP2.2 (B), U3.6

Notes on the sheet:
Optional for powering on/off with the Amiga’s on/off
Optional Power Source
7-12V recommended
VCC
GND
Leg support for sd-module
Optional Activity LED
Optional Power LED

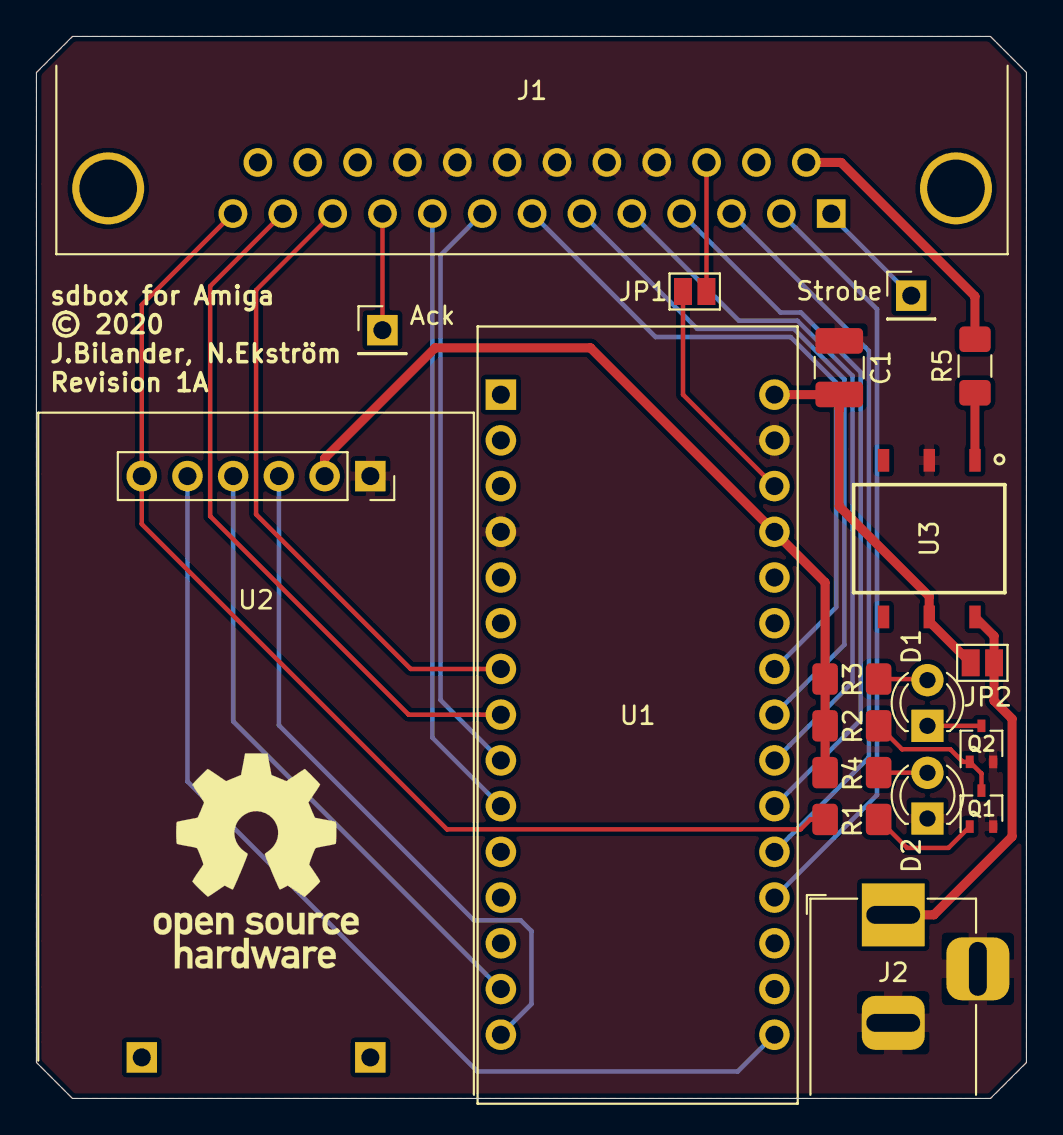
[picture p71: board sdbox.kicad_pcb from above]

Board: 2 copper layers, 55.0 x 59.0 mm, 21 parts (0 on the bottom side), 29 nets.

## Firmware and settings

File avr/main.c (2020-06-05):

/*
 * Written in the end of April 2020 by Niklas Ekström.
 */
#include <avr/io.h>

// Amiga pins:
// D0 = A0 = PC0
// D1 = A1 = PC1
// D2 = A2 = PC2
// D3 = A3 = PC3
// D4 = A4 = PC4
// D5 = A5 = PC5
// D6 = D6 = PD6
// D7 = D7 = PD7
// BUSY = D4 = PD4
// POUT = D5 = PD5

// SPI pins in port B.
#define SCK_BIT     5
#define MISO_BIT    4
#define MOSI_BIT    3
#define SS_BIT      2

// These bits are in port D.
#define IDLE_BIT    4
#define CLOCK_BIT   5

int main()
{
    DDRB = (1 << SCK_BIT) | (1 << MOSI_BIT) | (1 << SS_BIT);
    PORTB = (1 << SS_BIT);

    // SPI enabled, master, fosc/64 = 250 kHz
    SPCR = (1 << SPE) | (1 << MSTR) | (1 << SPR1) | (1 << SPR0);
    SPSR |= (1 << SPI2X);

    DDRD = (1 << IDLE_BIT);
    DDRC = 0;

    PORTD = 0;
    PORTC = 0;

    uint8_t v;
    uint8_t w;
    uint8_t next_port_d;
    uint8_t next_port_c;
    uint16_t byte_count;

main_loop:
    if (PIND & (1 << CLOCK_BIT))
    {
        while (PIND & (1 << CLOCK_BIT))
            ;
    }
    else
    {
        while (!(PIND & (1 << CLOCK_BIT)))
            ;
    }

    if (!(PIND & 0x80))
    {
        if (PIND & 0x40)
            goto do_read1;
        else
            goto do_write1;
    }

    v = PIND;
    w = PINC;

    if (!(v & 0x40)) // READ2 or WRITE2
    {
        byte_count = (w & 0x1f) << 8;

        if (v & (1 << CLOCK_BIT))
        {
            while (PIND & (1 << CLOCK_BIT))
                ;
        }
        else
        {
            while (!(PIND & (1 << CLOCK_BIT)))
                ;
        }

        v = PIND;

        byte_count |= (v & 0xc0) | PINC;
        if (w & 0x20)
            goto do_read;
        else
            goto do_write;
    }
    else if ((w & 0x3e) == 0) // SPEED
    {
        if (w & 1) // Fast
            SPCR = (1 << SPE) | (1 << MSTR);
        else // Slow
            SPCR = (1 << SPE) | (1 << MSTR) | (1 << SPR1) | (1 << SPR0);
    }

    goto main_loop;

do_read1:
    byte_count = PINC;

do_read:
    SPDR = 0xff;

    v = PIND;

    PORTD = (v & 0xc0) | (1 << IDLE_BIT);
    DDRD = 0xc0 | (1 << IDLE_BIT);

    PORTC = byte_count & 0x3f;
    DDRC = 0x3f;

read_loop:
    while (!(SPSR & (1 << SPIF)))
        ;

    next_port_c = SPDR;
    next_port_d = (next_port_c & 0xc0) | (1 << IDLE_BIT);

    if (v & (1 << CLOCK_BIT))
    {
        while (PIND & (1 << CLOCK_BIT))
            ;
    }
    else
    {
        while (!(PIND & (1 << CLOCK_BIT)))
            ;
    }

    PORTD = next_port_d;
    PORTC = next_port_c;

    v = PIND;

    if (byte_count)
    {
        byte_count--;
        SPDR = 0xff;
        goto read_loop;
    }

    if (v & (1 << CLOCK_BIT))
    {
        while (PIND & (1 << CLOCK_BIT))
            ;
    }
    else
    {
        while (!(PIND & (1 << CLOCK_BIT)))
            ;
    }

    DDRD = (1 << IDLE_BIT);
    DDRC = 0;

    PORTD = 0;
    PORTC = 0;

    goto main_loop;

do_write1:
    byte_count = PINC;
    v = PIND;

do_write:
    PORTD = (1 << IDLE_BIT);

write_loop:
    if (v & (1 << CLOCK_BIT))
    {
        while (PIND & (1 << CLOCK_BIT))
            ;
    }
    else
    {
        while (!(PIND & (1 << CLOCK_BIT)))
            ;
    }

    v = PIND;
    SPDR = (v & 0xc0) | PINC;

    while (!(SPSR & (1 << SPIF)))
        ;

    (void) SPDR;

    if (byte_count)
    {
        byte_count--;
        goto write_loop;
    }

    PORTD = 0;

    goto main_loop;

    return 0;
}

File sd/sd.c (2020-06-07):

/*
 *  SPI SD device driver for K1208/Amiga 1200
 *
 *  Copyright (C) 2018 Mike Stirling
 *
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
 *  You should have received a copy of the GNU General Public License
 *  along with this program.  If not, see <https://www.gnu.org/licenses/>.
 */

//#include <stdint.h>
#include <string.h>

#include "common.h"
#include "spi.h"
#include "sd.h"
#include "timer.h"

#define SLOW_CLOCK			400000
#define FAST_CLOCK			3000000

#define READY_TIMEOUT_MS	500
#define INIT_TIMEOUT_MS		1000
#define MAX_RESPONSE_POLLS	10

/* MMC/SD command */
#define CMD0	(0)			/* GO_IDLE_STATE */
#define CMD1	(1)			/* SEND_OP_COND (MMC) */
#define	ACMD41	(0x80+41)	/* SEND_OP_COND (SDC) */
#define CMD8	(8)			/* SEND_IF_COND */
#define CMD9	(9)			/* SEND_CSD */
#define CMD10	(10)		/* SEND_CID */
#define CMD12	(12)		/* STOP_TRANSMISSION */
#define ACMD13	(0x80+13)	/* SD_STATUS (SDC) */
#define CMD16	(16)		/* SET_BLOCKLEN */
#define CMD17	(17)		/* READ_SINGLE_BLOCK */
#define CMD18	(18)		/* READ_MULTIPLE_BLOCK */
#define CMD23	(23)		/* SET_BLOCK_COUNT (MMC) */
#define	ACMD23	(0x80+23)	/* SET_WR_BLK_ERASE_COUNT (SDC) */
#define CMD24	(24)		/* WRITE_BLOCK */
#define CMD25	(25)		/* WRITE_MULTIPLE_BLOCK */
#define CMD32	(32)		/* ERASE_ER_BLK_START */
#define CMD33	(33)		/* ERASE_ER_BLK_END */
#define CMD38	(38)		/* ERASE */
#define CMD55	(55)		/* APP_CMD */
#define CMD58	(58)		/* READ_OCR */

static sd_card_info_t sd_card_info;

/*! Utility function for parsing CSD fields */
static int sd_parse_csd(sd_card_info_t *ci, const uint32_t *bits)
{
	sd_card_csd_t *csd = &ci->csd;
	memset(csd, 0, sizeof(sd_card_csd_t));

	TRACE("CSD: %08X %08X %08X %08X\n",
			(unsigned int)bits[0],
			(unsigned int)bits[1],
			(unsigned int)bits[2],
			(unsigned int)bits[3]);

	csd->csd_structure = (bits[0] >> 30) & 0x2;
	csd->taac = (bits[0] >> 16) & 0xff;
	csd->nsac = (bits[0] >> 8) & 0xff;
	csd->max_transfer_rate = (bits[0] >> 0) & 0xff;
	csd->card_command_classes = (bits[1] >> 20) & 0xfff;
	csd->read_block_len = (bits[1] >> 16) & 0xf;
	csd->read_partial_blocks = (bits[1] >> 15) & 0x1;
	csd->write_block_misalign = (bits[1] >> 14) & 0x1;
	csd->read_block_misalign = (bits[1] >> 13) & 0x1;
	csd->dsr_implemented = (bits[1] >> 12) & 0x1;

	if (ci->type == sdCardType_SD1_x || ci->type == sdCardType_SD2_0) {
		csd->device_size = (bits[1] << 2) & 0xffc;
		csd->device_size |= (bits[2] >> 30) & 0x3;

		csd->max_read_current_vdd_min = (bits[2] >> 27) & 0x7;
		csd->max_read_current_vdd_max = (bits[2] >> 24) & 0x7;
		csd->max_write_current_vdd_min = (bits[2] >> 21) & 0x7;
		csd->max_write_current_vdd_max = (bits[2] >> 18) & 0x7;
		csd->device_size_mult = (bits[2] >> 15) & 0x7;

		ci->capacity = (uint64_t)(csd->device_size + 1) << (csd->device_size_mult + csd->read_block_len + 2);
	} else if (ci->type == sdCardType_SDHC) {
		csd->device_size = (bits[1] << 16) & 0x3f;
		csd->device_size |= (bits[2] >> 16) & 0xffff;

		ci->capacity = (uint64_t)(csd->device_size + 1) << 19;
	} else {
		ERROR("Card type not supported for CSD decode\n");
		return sdError_Unsupported;
	}

	csd->erase_single_block = (bits[2] >> 14) & 0x1;
	csd->erase_sector_size = (bits[2] >> 7) & 0x7f;
	csd->write_protect_group_size = (bits[2] >> 0) & 0x7f;
	csd->write_protect_group = (bits[3] >> 31) & 0x1;
	csd->write_speed_factor = (bits[3] >> 26) & 0x7;
	csd->write_block_len = (bits[3] >> 22) & 0xf;
	csd->write_partial_blocks = (bits[3] >> 21) & 0x1;
	csd->file_format_group = (bits[3] >> 15) & 0x1;
	csd->copy_flag = (bits[3] >> 14) & 0x1;
	csd->perm_write_prot = (bits[3] >> 13) & 0x1;
	csd->temp_write_prot = (bits[3] >> 12) & 0x1;
	csd->file_format = (bits[3] >> 10) & 0x3;
	csd->crc = (bits[3] >> 1) & 0x7f;

	if (csd->read_block_len != csd->write_block_len) {
		ERROR("Different read/write block sizes not supported\n");
		return sdError_Unsupported;
	}

	ci->block_size = csd->read_block_len;
	INFO("capacity %u MiB block size = %u bytes\n",
			(unsigned int)(ci->capacity / 1024 / 1024),
			1 << ci->block_size);

	/* FIXME: Check CRC */

	return 0;
}

/*! Utility function for parsing CID fields */
static int sd_parse_cid(sd_card_info_t *ci, const uint32_t *bits)
{
	sd_card_cid_t *cid = &ci->cid;
	memset(cid, 0, sizeof(sd_card_cid_t));

	TRACE("CID: %08X %08X %08X %08X\n",
			(unsigned int)bits[0],
			(unsigned int)bits[1],
			(unsigned int)bits[2],
			(unsigned int)bits[3]);

	cid->manufacturer_id = (bits[0] >> 24) & 0xff;
	cid->app_id[0] = (bits[0] >> 16) & 0xff;
	cid->app_id[1] = (bits[0] >> 8) & 0xff;
	cid->product_name[0] = (bits[0] >> 0) & 0xff;
	cid->product_name[1] = (bits[1] >> 24) & 0xff;
	cid->product_name[2] = (bits[1] >> 16) & 0xff;
	cid->product_name[3] = (bits[1] >> 8) & 0xff;
	cid->product_name[4] = (bits[1] >> 0) & 0xff;
	cid->product_rev = (bits[2] >> 24) & 0xff;
	cid->product_sn = (bits[2] << 8) & 0xffffff00;
	cid->product_sn |= (bits[3] >> 24) & 0xff;
	cid->mfg_date = (bits[3] >> 8) & 0xfff;
	cid->crc = (bits[3] >> 1) & 0x7f;

	INFO("SD mfg %02X app '%c%c' product '%.5s' rev %02X sn %08X mfg %02u/%04u\n",
			cid->manufacturer_id,
			cid->app_id[0], cid->app_id[1],
			cid->product_name,
			cid->product_rev,
			(unsigned int)cid->product_sn,
			(unsigned int)(cid->mfg_date & 0xf),
			(unsigned int)((cid->mfg_date >> 8) + 2000));

	/* FIXME: Check CRC */

	return 0;
}


static int sd_wait_ready(void)
{
	uint32_t timeout;
	uint8_t in;

	timeout = timer_get_tick_count() + TIMER_MILLIS(READY_TIMEOUT_MS);
	do {
		spi_read(&in, 1);
	} while (in != 0xff && (int32_t)(timer_get_tick_count() - timeout) < 0);

	return (in == 0xff) ? 0 : sdError_Timeout;
}

static void sd_deselect(void)
{
	spi_deselect();
}

static int sd_select(void)
{
	spi_select();
	if (sd_wait_ready() == 0) {
		return 0;
	}
	spi_deselect();

	ERROR("Timeout waiting for card ready\n");
	return sdError_Timeout;
}

static int sd_read_block(uint8_t *buf, unsigned int size)
{
	uint32_t timeout;
	uint8_t token, crc[2];

	/* Wait for data start token */
	timeout = timer_get_tick_count() + TIMER_MILLIS(READY_TIMEOUT_MS);
	do {
		spi_read(&token, 1);
	} while (token == 0xff && (int32_t)(timer_get_tick_count() - timeout) < 0);
	if (token != 0xfe) {
		ERROR("No data token received\n");
		return sdError_Timeout;
	}

	/* Read data */
	spi_read(buf, size);
	spi_read(crc, 2);

	return 0;
}

static int sd_write_block(const uint8_t *buf, uint8_t token)
{
	uint8_t crc[2] = {0xff, 0xff};
	uint8_t resp;

	if (sd_wait_ready() < 0) {
		ERROR("Card not ready\n");
		return sdError_Timeout;
	}

	/* Send token */
	spi_write(&token, 1);
	if (token != 0xfd) {
		/* Send data, except for STOP_TRAN */
		spi_write(buf, SD_SECTOR_SIZE);
		spi_write(crc, 2); /* dummy */

		/* Receive data response */
		spi_read(&resp, 1);
		if ((resp & 0x1f) != 0x05) {
			ERROR("Bad response\n");
			return sdError_BadResponse;
		}
	}

	return 0;
}
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

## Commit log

2020-06-05 added source files
    [sdbox.kicad_pcb, sdbox.sch]
2020-06-05 corrected driver name
2020-06-13 Remove loading of unused libraries
    The libraries were not being used, and prevented the driver from loading
    on kickstart 1.3.
    [device.c]
2020-11-07 Update spi-par.c
    More elegant way to avoid blocking boot sequence if adaptor is not physically present.
    [spi-par.c]
2020-11-07 Update spi.h
    Including timer.h header file.
2021-03-13 fixed symbol and footprint libs now included as project libs
    [sdbox.kicad_pcb, sdbox.sch]
2021-03-13 add schematic pdf
2021-03-13 added gerbers

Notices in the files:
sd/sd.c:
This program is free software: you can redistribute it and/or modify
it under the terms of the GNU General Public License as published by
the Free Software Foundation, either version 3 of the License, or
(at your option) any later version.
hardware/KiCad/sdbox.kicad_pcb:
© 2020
